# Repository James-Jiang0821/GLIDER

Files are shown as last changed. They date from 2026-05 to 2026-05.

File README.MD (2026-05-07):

# Glider System

Top-level repo for the underwater glider. 

ROS 2 stack on the Raspberry Pi, Teensy firmware for the P&R and VBD boards, KiCad designs for the custom electronics, and post-test analysis tooling.

Each subfolder has its own README with full details.

## Subsystems

- **[ROS2_SYSTEM/](ROS2_SYSTEM/README.md)** — ROS 2 Jazzy stack on the Raspberry Pi: sensor drivers, mission state machine, inner/outer-loop controller, safety watchdog, Iridium telemetry, and the CAN bridge to the Teensy boards.
- **[TEENSY/](TEENSY/)** — Teensy 4.0 firmware for the actuator boards.
  - **[tsyPR/](TEENSY/tsyPR/README.md)** — Pitch & Roll firmware (stepper-driven pitch mass + roll mass).
  - **[tsyVBDL/](TEENSY/tsyVBDL/README.md)** — Variable Buoyancy Device firmware (lead-screw piston with closed-loop position control).
- **[PCB/](PCB/README.MD)** — KiCad schematics and layouts for the custom P&R and VBD boards.
- **[BATTERY_BOARD/](BATTERY_BOARD/README.MD)** — KiCad designs for the P&R and VBD battery boards (A/B variants).
- **[ROS2_TESTING/](ROS2_TESTING/README.md)** — Post-test analysis scripts for ROS 2 bag files (`.mcap` to CSV).

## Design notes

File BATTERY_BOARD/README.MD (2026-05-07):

# Battery Board

KiCad design files for the glider's battery boards.

## Subsystems

- **P&R/** — Pitch & Roll battery board. Powers the P&R subsystem; A and B variants.
- **VBD/** — Variable Buoyancy Device battery board. Powers the VBD subsystem; A and B variants.

Each folder contains the KiCad schematic (`.kicad_sch`), PCB layout (`.kicad_pcb`), and project file (`.kicad_pro`) for both A and B revisions.

## Authors

Bartol Vahcic

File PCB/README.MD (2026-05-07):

# PCB

KiCad design files for the glider's custom boards.

## Subsystems

- **P&R/** — Pitch & Roll board. Drives the pitch and roll actuators; also connects to the Raspberry Pi.
- **VBD/** — Variable Buoyancy Device board. Drives the VBD pump/valve subsystem.

Each folder contains the KiCad schematic (`.kicad_sch`) and PCB layout (`.kicad_pcb`); `P&R/` also includes the project file (`.kicad_pro`).

## Authors

Qihao Zhang

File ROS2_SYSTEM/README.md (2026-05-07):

# Glider ROS 2 System

ROS 2 Jazzy stack for an underwater glider: sensor drivers, mission
state machine, inner/outer-loop controller, safety watchdog, Iridium
telemetry, and a CAN bridge to the Teensy-based P&R and VBD boards.

## Requirements

- Ubuntu 24.04 + ROS 2 Jazzy
- Python 3.12
- Hardware:
  - Raspberry Pi with I2C and UART enabled
  - Pololu MinIMU-9 v6 (I2C)
  - MAX-M10S GNSS (I2C)
  - Keller pressure sensor (I2C)
  - Ping sonar (UART)
  - Iridium modem (UART)
  - CAN bus to Teensy P&R (pitch & roll) + VBD (variable buoyancy) boards

## Build

The project is cloned into the `src/` of a ROS 2 workspace — e.g.
`~/glider_ws/src/ROS2_SYSTEM/`. Build from the workspace root:

```bash
source /opt/ros/jazzy/setup.bash
cd ~/glider_ws
colcon build --packages-select glider_msgs
source install/setup.bash
colcon build --packages-select glider_ros
source install/setup.bash
```

## Run

The system is split across three launch files so each runs in its own
terminal with clean, isolated log output:

```bash
# Main system: drivers, adapters, safety, controller
ros2 launch glider_ros all_nodes_launch.py

# Mission state machine — separate terminal
ros2 launch glider_ros state_manager_launch.py

# CAN bridge (Teensy P&R + VBD) — separate terminal
ros2 launch glider_ros can_bridge_launch.py
```

Each fresh terminal needs `source install/setup.bash` once before
`ros2 launch`. Individual nodes can also be launched with
`ros2 run glider_ros <executable>` — see the full executable list in
[setup.py](src/glider_ros/setup.py).

## System overview

The state manager drives two lifecycle nodes (`controller_node`,
`communication_iridium_node`) through `configure` / `activate` /
`deactivate` / `cleanup` transitions as part of mission phasing.

## Layout

- `src/glider_msgs/` — custom messages and actions (`Float64Stamped`,
  `HomeActuators`, `IridiumWindow`).
- `src/glider_ros/glider_ros/driver/` — hardware-facing nodes (I2C,
  UART).
- `src/glider_ros/glider_ros/bridge/` — protocol bridges to external
  microcontrollers (CAN ↔ Teensy P&R / VBD).
- `src/glider_ros/glider_ros/adapter/` — data fusion and formatting
  adapters.
- `src/glider_ros/glider_ros/manager/` — mission state machine.
- `src/glider_ros/glider_ros/controller/` — flight controller (lifecycle).
- `src/glider_ros/glider_ros/safety/` — and watchdog
  monitor.
- `src/glider_ros/launch/` — launch files per deployment scenario.
- `src/glider_ros/config/` — YAML parameter files.
- `src/glider_ros/test/` — pytest unit/integration tests.

For what each node does, please read the module docstring at the top of its
`.py` file.

## Testing

### Unit Testing

To perform unit testing, from the workspace root, run:

```bash
source /opt/ros/jazzy/setup.bash
source install/setup.bash
python3 -m pytest src/glider_ros/test/ -v --cov=glider_ros --cov-report=term-missing --cov-report=html

```

Unit tests cover the adapter, safety, and state manager nodes. HTML
coverage lands in `htmlcov/`.

## Authors

- James Jiang <jamesjiang0821@gmail.com>
- Hussain Khan <hussainniassuh786@gmail.com>

## License

MIT. See `package.xml` / `setup.py`.

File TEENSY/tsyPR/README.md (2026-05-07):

# P&R Teensy Firmware (`tsyPR`)

Firmware for the Pitch & Roll (P&R) board on the underwater glider.
Runs on a Teensy 4.0 and drives two stepper-actuated axes — a linear
pitch mass and a rotational roll mass — with limit-based homing and a
CAN bridge back to the Raspberry Pi running the
[Glider ROS 2 stack](../../ROS2_SYSTEM/README.md).

A single board handles both axes (`NODE_ID=3`).

## Requirements

- PlatformIO (Arduino framework, `platform = teensy`)
- Hardware:
  - Teensy 4.0
  - 2 × DRV8825 stepper drivers (pitch + roll)
  - Pitch stepper + lead-screw mass slider (0.01 mm/step)
  - Roll stepper + rotational mass (0.045 °/step)
  - 2 × push-switch endstops (pitch fwd/rev limits)
  - Hall-effect sensor (roll zero/homing)
  - Adafruit VL6180X ToF sensor (I2C, pitch position cross-check)
  - TinyBMS over UART (battery telemetry)
  - Leak sensor
  - CAN transceiver on CAN2 (Teensy pins 0/1)

## Build & Flash

From [TEENSY/tsyPR/](.):

```bash
# Build
pio run

# Build + flash over USB
pio run -t upload

# Serial monitor (115200 baud)
pio device monitor
```

Node identity is set by the `-D NODE_ID=...` build flag in
[platformio.ini](platformio.ini). Default is `3` (P&R). Override with:

```bash
pio run -t upload --project-option="build_flags=-D NODE_ID=3"
```

## System overview

The control loop runs:

1. Read step counters + endstops/hall + ToF -> per-axis position
   estimate (steps as primary, ToF/hall as homing reference).
2. `SafetyManager` aggregates leak, driver fault, overcurrent, stall,
   command timeout, and BMS health into `hard_fault` / `soft_fault`
   bits — controllers never decide faults themselves.
3. `PitchController` and `RollController` each run their state machine
   (`UNHOMED -> HOMING -> RUN -> HOLD -> FAULT`), stepping the DRV8825 at
   the configured step rate.
4. CAN frames publish pitch/roll position and status; setpoints and
   mode commands arrive on CAN from the ROS bridge.

## Layout

- [platformio.ini](platformio.ini) — build env, lib deps, `NODE_ID`
- [include/config/](include/config/) — `pin_map.hpp`, `constants.hpp`
  (step geometry, travel limits, safety thresholds, CAN scaling)
- [include/drivers/](include/drivers/) /
  [src/drivers/](src/drivers/) — hardware-facing classes:
  - `stepper_driver` (DRV8825, STEP/DIR/ENA/FLT)
  - `push_switch` (pitch fwd/rev limit endstops)
  - `hall_sensor` (roll homing reference)
  - `tof_sensor` (VL6180X over Wire1)
  - `leak_sensor`, `bms` (TinyBMS UART)
  - `can_bus` (FlexCAN wrapper, 11-bit IDs)
  - `main.cpp` — composition root, control loop
- [include/controllers/](include/controllers/) /
  [src/controllers/](src/controllers/) — control logic:
  - `pitch_controller` (state machine, limit-switch homing,
    soft-zone limits)
  - `roll_controller` (state machine, hall-sensor homing,
    soft-zone limits)
  - `safety_manager` (centralised fault aggregation, latched)
  - `bms_manager` (battery state + timeout policy)
- [include/protocols/](include/protocols/) /
  [src/protocols/](src/protocols/) — `can_messages.hpp`/`.cpp`,
  CAN frame IDs and packing.
- [include/utils/logger.hpp](include/utils/logger.hpp) — serial logging.
- [test/](test/) — bench-test notes for motors, CAN, safety, BMS, etc.

## Key parameters

Defined in [include/config/constants.hpp](include/config/constants.hpp):

- Pitch: 0.01 mm/step, ±56.9 mm physical travel
- Roll: 0.045 °/step, ±90° physical travel
- Overcurrent: 6.0 A hard, 3.0 A stall threshold
- Stall confirm: 2.0 s at ≥25% duty with <0.1 mm motion
- Homing timeout: 60 s
- Leak debounce: 50 ms; driver-fault debounce: 20 ms
- Command timeout: 300 ms (small) / 120 s (large)
- BMS timeout: 5 s (small) / 120 s (large)

## Testing

Bench tests are scripted/manual procedures captured as notes in
[test/](test/), numbered by integration stage (motor only -> motor +
CAN -> safety -> BMS). Run them in order when bringing up a new board.

## Authors

Jasper Yip

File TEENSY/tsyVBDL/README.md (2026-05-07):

# VBD Teensy Firmware (`tsyVBDL`)

Firmware for the Variable Buoyancy Device (VBD) board on the underwater
glider. Runs on a Teensy 4.0 and drives a lead-screw piston via a
brushed DC motor, with closed-loop position control and a CAN bridge
back to the Raspberry Pi running the [Glider ROS 2 stack](../../ROS2_SYSTEM/README.md).

Two physical boards share this firmware — `PORT` (NODE_ID=1) and
`STARBOARD` (NODE_ID=2) — selected at build time.

## Requirements

- PlatformIO (Arduino framework, `platform = teensy`)
- Hardware:
  - Teensy 4.0
  - Pololu G2 High-Power 24v13 motor driver
  - Maxon brushed DC motor + 1024 CPR quadrature encoder, 156:1 gearbox
  - 4 mm/rev lead screw, 150 mm stroke piston
  - Adafruit VL6180X ToF sensor (I2C, stroke fusion)
  - Inductive proximity sensor (homing endstop)
  - TinyBMS over UART (battery telemetry)
  - Leak sensor
  - CAN transceiver on CAN2 (Teensy pins 0/1)

## Build & Flash

From [TEENSY/tsyVBDL/](.):

```bash
# Build
pio run

# Build + flash over USB
pio run -t upload

# Serial monitor (115200 baud)
pio device monitor
```

Node identity is set by the `-D NODE_ID=...` build flag in
[platformio.ini](platformio.ini). Default is `1` (LEFT). Override per
board:

```bash
pio run -t upload --project-option="build_flags=-D NODE_ID=2"
```

## System overview

The 1 kHz control loop runs:

1. Read encoder + ToF -> `Estimator` produces fused stroke estimate
   (counts as primary, ToF as drift/slip correction).
2. `SafetyManager` aggregates leak, motor fault, overcurrent, stall,
   command timeout, and BMS health into `hard_fault` / `soft_fault`
   bits — controllers never decide faults themselves.
3. `PistonController` runs its state machine
   (`UNHOMED -> HOMING -> RUN -> HOLD -> FAULT`), driving `PIDController`
   inside `RUN`.
4. CAN frames at 50 Hz publish position, current, and status; setpoints
   and mode commands arrive on CAN from the ROS bridge.

## Layout

- [platformio.ini](platformio.ini) — build env, lib deps, `NODE_ID`
- [include/config/](include/config/) — `pin_map.hpp`, `constants.hpp`
  (stroke geometry, PID gains, safety thresholds, CAN scaling)
- [include/drivers/](include/drivers/) /
  [src/drivers/](src/drivers/) — hardware-facing classes:
  - `motor_driver` (Pololu G2, PWM/DIR/SLP/FLT, current sense)
  - `encoder` / `enc_alt` (quad encoder, two backends)
  - `tof_sensor` (VL6180X over Wire1)
  - `proximity` (homing endstop)
  - `leak_sensor`, `bms` (TinyBMS UART)
  - `can_bus` (FlexCAN wrapper, 11-bit IDs)
  - `main.cpp` — composition root, control loop
- [include/controllers/](include/controllers/) /
  [src/controllers/](src/controllers/) — control logic:
  - `estimator` (encoder + ToF fusion, slip detection)
  - `pid_controller` (P, I, D with anti-windup + output clamp)
  - `piston_controller` (state machine, homing, soft-zone limits)
  - `safety_manager` (centralised fault aggregation, latched)
  - `bms_manager` (battery state + timeout policy)
- [include/protocols/](include/protocols/) /
  [src/protocols/](src/protocols/) — `can_messages.hpp`/`.cpp`,
  CAN frame IDs and packing (e.g. `STATUS_FAULT 0x050`,
  position in 0.1 mm units).
- [include/utils/logger.hpp](include/utils/logger.hpp) — serial logging.
- [test/](test/) — bench-test notes for motor, ToF, PID, CAN, homing,
  safety, encoder, BMS, leak, prox, etc.

## Key parameters

Defined in [include/config/constants.hpp](include/config/constants.hpp):

- Control loop: 1 kHz, PWM 25 kHz
- Stroke: 0–150 mm physical, 10–145 mm hard limits, 20–135 mm soft zone
- PID: Kp=0.10, Ki=0.0, Kd=0.003
- Position tolerance: 0.1 mm (enter HOLD), 2.0 mm drift restarts PID
- Homing: 40% PWM toward prox, 10% backoff
- Slip detection: 3 mm encoder-vs-ToF disagreement
- Overcurrent: 6.0 A hard, 3.0 A stall threshold
- CAN position scaling: 0.1 mm/LSB

## Testing

Bench tests are scripted/manual
procedures captured as notes in [test/](test/), numbered by integration
stage (motor only -> ToF -> PID -> CAN -> homing -> safety). Run them in
order when bringing up a new board.

## Authors

Jasper Yip

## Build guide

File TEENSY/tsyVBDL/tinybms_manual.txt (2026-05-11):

                     Communication
                     Protocols
                     Tiny BMS
        Revision D, 2025-07-04
                                         Tiny BMS Communication Protocols
         Contents
         Chapter 1: Tiny BMS UART communication protocol.....................................................................................4
           1. Introduction........................................................................................................................................... 4
            1.1. UART communication commands list............................................................................................4
              1.1.1. Tiny BMS acknowledgement.................................................................................................4
              1.1.2. Read Tiny BMS registers block.............................................................................................4
              1.1.3. Read Tiny BMS individual registers......................................................................................5
              1.1.4. Write Tiny BMS registers block.............................................................................................5
              1.1.5. Write Tiny BMS individual registers.......................................................................................5
              1.1.6. Read Tiny BMS registers block (MODBUS compatible)........................................................6
              1.1.7. Write Tiny BMS registers block (MODBUS compatible)........................................................6
              1.1.8. Reset Tiny BMS, clear Events and Statistics........................................................................7
              1.1.9. Read Tiny BMS newest Events.............................................................................................7
              1.1.10.  Read Tiny BMS all Events..................................................................................................7
              1.1.11.  Read battery pack voltage (Reg:36)...................................................................................8
              1.1.12.  Read battery pack current (Reg:38)...................................................................................8
              1.1.13.  Read battery pack max. cell voltage (Reg:41)....................................................................8
              1.1.14.  Read battery pack min. cell voltage (Reg:40).....................................................................8
              1.1.15.  Read Tiny BMS online status (Reg:50)..............................................................................8
              1.1.16.  Read Tiny BMS lifetime counter (Reg:32)..........................................................................9
              1.1.17.  Read Tiny BMS estimated SOC value (Reg:46)................................................................9
              1.1.18.  Read Tiny BMS device temperatures (Reg:48, Reg:42, Reg:43).......................................9
              1.1.19.  Read battery pack cells voltages......................................................................................10
              1.1.20.  Read Tiny BMS settings values (min, max, default, current)............................................10
              1.1.21.  Read Tiny BMS version....................................................................................................10
              1.1.22.  Read Tiny BMS extended version....................................................................................10
              1.1.23.  Read Tiny BMS calculated speed, left distance and estimated time values.....................11
            1.2. CRC checksum calculation..........................................................................................................11
            1.3. UART communication examples.................................................................................................12
              1.3.1. MODBUS write registers example.......................................................................................12
              1.3.2. MODBUS read registers example.......................................................................................13
              1.3.3. Tiny BMS read temperatures example................................................................................13
         Chapter 2: Tiny BMS CAN bus communication protocol..............................................................................14
           2. Introduction......................................................................................................................................... 14
            2.1. CAN bus communication commands list.....................................................................................14
              2.1.1. Reset Tiny BMS, clear Events and Statistics......................................................................14
              2.1.2. Read Tiny BMS registers block...........................................................................................14
              2.1.3. Write Tiny BMS registers block...........................................................................................15
              2.1.4. Read Tiny BMS newest Events...........................................................................................15
              2.1.5. Read Tiny BMS all Events...................................................................................................16
              2.1.6. Read battery pack voltage (Reg:36)....................................................................................17
              2.1.7. Read battery pack current (Reg:38)....................................................................................17
              2.1.8. Read battery pack max. cell voltage (Reg:41).....................................................................17
              2.1.9. Read battery pack min. cell voltage (Reg:40)......................................................................18
              2.1.10.  Read Tiny BMS online status (Reg:50)............................................................................18
              2.1.11.  Read Tiny BMS lifetime counter (Reg:32)........................................................................18
              2.1.12.  Read Tiny BMS estimated SOC value (Reg:46)..............................................................19
              2.1.13.  Read Tiny BMS device temperatures (Reg:48, Reg:42, Reg:43).....................................19
              2.1.14.  Read battery pack cells voltages......................................................................................20
              2.1.15.  Read Tiny BMS settings values (min, max, default, current)............................................20
              2.1.16.  Read Tiny BMS version....................................................................................................21
              2.1.17.  Read Tiny BMS calculated speed, left distance and estimated time values.....................21
              2.1.18.  Read CAN node ID..........................................................................................................22
              2.1.19.  Write CAN node ID...........................................................................................................22
         Chapter 3: Tiny BMS registers map.............................................................................................................23
           3. Introduction......................................................................................................................................... 23
          www.enepaq.com     Revision D, 2025-07-04    Page 2
                                  Tiny BMS Communication Protocols
       3.1. Tiny BMS Live data.....................................................................................................................23
       3.2. Tiny BMS Statistics data.............................................................................................................23
       3.3. Tiny BMS Events data.................................................................................................................24
       3.4. Tiny BMS settings.......................................................................................................................24
       3.5. Tiny BMS version data................................................................................................................25
    Chapter 4: Tiny BMS Events messages list.................................................................................................26
      4. Introduction......................................................................................................................................... 26
       4.1. Tiny BMS Fault messages list.....................................................................................................26
       4.2. Tiny BMS Warning messages list................................................................................................26
       4.3. Tiny BMS Information messages list...........................................................................................26
     www.enepaq.com    Revision D, 2025-07-04    Page 3
                                                                                                       Tiny BMS Communication Protocols
                       Chapter 1: Tiny BMS UART communication protocol
                       1. Introduction
                       Tiny BMS device includes a single multi-purpose UART interface. In combination with various converters, 
                       the interface is compatible with USB, bluetooth and CAN interfaces. Various proprietary commands are 
                       available for fast communication, also MODBUS commands 03 and 16 are supported for rapid integration 
                       to existing industrial systems. An internal Tiny BMS device register map is given in Chapter 3. The register 
                       map values can be read and modified using MODBUS and proprietary commands. This chapter in detail 
                       covers all available commands implemented to communicate with Tiny BMS device. Every command 
                       request and response contains 16 bit CRC checksum. How to calculate CRC value refer to Chapter 1.2.
                        Note: UART configuration: baudrate 115200 bit/s, 8 data bits, 1 stop bit, no parity, no flow control. UART 
                        configuration is not allowed to be changed by the user.
                       1.1. UART communication commands list
                       1.1.1. Tiny BMS acknowledgement
                       Response from BMS [NACK]
                        Byte 1   Byte 2   Byte 3             Byte 4               Byte 5      Byte 6
                         0xAA     0x00     CMD               ERROR              CRC:LSB     CRC:MSB
                                                      0x00 – CMD ERROR
                                                       0x01 – CRC ERROR
                       Response from BMS [ACK]
                        Byte 1   Byte 2   Byte 3     Byte 4      Byte 5
                         0xAA     0x01     CMD     CRC:LSB CRC:MSB
                       CMD – Command code
                       ERROR – Error code
                       1.1.2. Read Tiny BMS registers block
                       Request to BMS
                         Byte1   Byte 2   Byte 3      Byte 4       Byte 5       Byte 6       Byte 7
                         0xAA     0x07      RL     ADDR:LSB      ADDR:MSB      CRC:LSB     CRC:MSB
                                                           [UINT_16]
                       Response from BMS [OK]
                         Byte1   Byte 2   Byte 3      Byte 4       Byte 5      ...   Byte n*2+2     Byte n*2+3    Byte n*2+4    Byte n*2+5
                         0xAA     0x07      PL     DATA1:LSB DATA1:MSB         ...   DATAn:LSB     DATAn:MSB       CRC:LSB      CRC:MSB
                                                           [UINT_16]                         [UINT_16]
                       RL – Registers to read
                       ADDR – First registers block address
                       DATA – Registers block values
                       PL – Payload length byte
                         Bit 7      Bit 6       Bit 5    Bit 4     Bit 3     Bit 2    Bit 1    Bit 0
                           0      Reserved                Payload size in bytes (last packet)
                           1      Reserved                       Current packet ID
                       Response from BMS [ERROR]
                         Byte 1   Byte 2    Byte 3    Byte 4     Byte 5       Byte 6
                         0xAA      0x00      0x07    ERROR CRC:LSB          CRC:MSB
                        www.enepaq.com                                  Revision D, 2025-07-04                                              Page 4
                                                                                   Tiny BMS Communication Protocols
         1.1.3. Read Tiny BMS individual registers
         Request to BMS
           Byte1  Byte 2   Byte 3     Byte 4        Byte 5      ...  Byte n*2+2    Byte n*2+3   Byte n*2+4  Byte n*2+5
           0xAA    0x09      PL     ADDR1:LSB ADDR1:MSB         ...  ADDRn:LSB    ADDRn:MSB      CRC:LSB    CRC:MSB
                                            [UINT_16]                        [UINT_16]
         PL – Payload length in bytes
         Response from BMS [OK]
           Byte1   Byte 2  Byte 3     Byte 4        Byte 5        Byte 6      Byte 7      ...    Byte n*4    Byte n*4+1
           0xAA    0x09      PL     ADDR1:LSB    ADDR1:MSB DATA1:LSB DATA1:MSB            ...  ADDRn:LSB     ADDRn:MSB
                                            [UINT_16]                  [UINT_16]                       [UINT_16]
           Byte n*4+2   Byte n*4+3   Byte n*4+4  Byte n*4+5
           DATAn:LSB   DATAn:MSB     CRC:LSB     CRC:MSB
                  [UINT_16]
         Request to BMS
         ADDR – Individual registers addresses
         DATA – Registers values
         PL – Payload length byte
           Bit 7     Bit 6      Bit 5   Bit 4     Bit 3    Bit 2    Bit 1   Bit 0
             0     Reserved              Payload size in bytes (last packet)
             1     Reserved                     Current packet ID
         Response from BMS [ERROR]
            Byte 1     Byte 2    Byte 3     Byte 4      Byte 5       Byte 6
            0xAA       0x00       0x09      ERROR      CRC:LSB     CRC:MSB
         1.1.4. Write Tiny BMS registers block
         Request to BMS
           Byte1    Byte 2   Byte 3      Byte 4       Byte 5        Byte 6       Byte 7      ... Byte n*2+4   Byte n*2+5
           0xAA     0x0B       PL      ADDR:LSB     ADDR:MSB     DATA1:LSB     DATA1:MSB     ... DATAn:LSB    DATAn:MSB
                                              [UINT_16]                  [UINT_16]                      [UINT_16]
           Byte n*2+6  Byte n*2+7
           CRC:LSB     CRC:MSB
         ADDR – First registers block address (valid addresses to write 0x012C to 0x018F)
         DATA – Registers block values to write
         PL – Payload length byte
           Bit 7     Bit 6      Bit 5   Bit 4     Bit 3    Bit 2    Bit 1   Bit 0
             0     Reserved              Payload size in bytes (last packet)
             1     Reserved                     Current packet ID
         Response from BMS [ACK]
           Byte 1  Byte 2    Byte 3    Byte 4      Byte 5
           0xAA     0x01     0x0B     CRC:LSB    CRC:MSB
         Response from BMS [ERROR]
           Byte 1  Byte 2    Byte 3    Byte 4      Byte 5      Byte 6
           0xAA     0x00     0x0B     ERROR      CRC:LSB     CRC:MSB
         1.1.5. Write Tiny BMS individual registers
         Request to BMS
           Byte1   Byte 2    Byte 3      Byte 4        Byte 5        Byte 6       Byte 7     ...   Byte n*4     Byte n*4+1
           0xAA     0x0D      PL      ADDR1:LSB     ADDR1:MSB     DATA1:LSB    DATA1:MSB     ... ADDRn:LSB ADDRn:MSB
                                              [UINT_16]                   [UINT_16]                      [UINT_16]
          www.enepaq.com                               Revision D, 2025-07-04                                        Page 5
                                                                                                   Tiny BMS Communication Protocols
                        Byte n*4+2   Byte n*4+3    Byte n*4+4  Byte n*4+5
                        DATAn:LSB    DATAn:MSB     CRC:LSB      CRC:MSB
                               [UINT_16]
                      ADDR – Individual registers addresses (valid addresses to write 0x012C to 0x018F)
                      DATA – Individual registers values to write
                      PL – Payload length byte
                        Bit 7      Bit 6      Bit 5    Bit 4    Bit 3     Bit 2    Bit 1    Bit 0
                          0      Reserved              Payload size in bytes (last packet)
                          1      Reserved                      Current packet ID
                      Response from BMS [ACK]
                       Byte 1   Byte 2     Byte 3    Byte 4      Byte 5
                        0xAA     0x01      0x0D     CRC:LSB CRC:MSB
                      Response from BMS [ERROR]
                       Byte 1   Byte 2     Byte 3    Byte 4      Byte 5      Byte 6
                        0xAA     0x00      0x0D      ERROR     CRC:LSB     CRC:MSB
                      1.1.6. Read Tiny BMS registers block (MODBUS compatible)
                      Request to BMS
                        Byte1   Byte 2       Byte 3         Byte 4      Byte 5   Byte 6    Byte 7      Byte 8
                        0xAA     0x03     ADDR1:MSB      ADDR1:LSB      0x00       RL     CRC:LSB CRC:MSB
                                                   [UINT_16]
                      ADDR – First registers block address
                      RL – Registers to read. Max. 127 registers (0x7F)
                      Response from BMS [OK]
                        Byte1    Byte 2    Byte 3     Byte 4        Byte 5      ...   Byte n*2+2    Byte n*2+3   Byte n*2+4  Byte n*2+5
                        0xAA      0x03       PL     DATA1:MSB     DATA1:LSB     ...  DATAn:MSB     DATAn:LSB     CRC:LSB     CRC:MSB
                                                            [UINT_16]                        [UINT_16]
                      PL – Payload length in bytes
                      Response from BMS [ERROR]
                        Byte 1   Byte 2    Byte 3    Byte 4     Byte 5      Byte 6
                        0xAA      0x00      0x03    ERROR CRC:LSB         CRC:MSB
                      1.1.7. Write Tiny BMS registers block (MODBUS compatible)
                      Request to BMS
                        Byte 1   Byte 2      Byte 3        Byte 4     Byte 5     Byte 6    Byte 7         Byte8           Byte 9      ...
                        0xAA      0x10     ADDR:MSB      ADDR:LSB      0x00       RL         PL        DATA1:MSB        DATA1:LSB     ...
                                                  [UINT_16]                                                     [UINT_16]
                        Byte n*2+6   Byte n*2+7    Byte n*2+8  Byte n*2+9
                       DATAn:MSB     DATAn:LSB     CRC:LSB      CRC:MSB
                               [UINT_16]
                      Response from BMS [OK]
                        Byte1    Byte 2       Byte 3         Byte 4       Byte 5     Byte 6       Byte 7        Byte 8
                        0xAA      0x10     ADDR:MSB        ADDR:LSB        0x00        RL       CRC:LSB       CRC:MSB
                                                    [UINT_16]
                      ADDR – First registers block address
                      RL – Registers to write. Max. 100 registers (0x64)
                      PL – Payload length in bytes
                      DATA – Registers block values to write
                      Response from BMS [ERROR]
                        Byte 1   Byte 2     Byte 3     Byte 4      Byte 5       Byte 6
                        0xAA      0x00      0x10      ERROR      CRC:LSB      CRC:MSB
                        www.enepaq.com                                Revision D, 2025-07-04                                           Page 6
                                                                                         Tiny BMS Communication Protocols
          1.1.8. Reset Tiny BMS, clear Events and Statistics
          Request to BMS
           Byte 1    Byte 2             Byte 3              Byte 4       Byte 5
            0xAA      0x02             OPTION              CRC:LSB     CRC:MSB
                                  0x01 – Clear Events
                                 0x02 – Clear Statistics
                                   0x05 – Reset BMS
          Response from BMS [ACK]
           Byte 1    Byte 2     Byte 3     Byte 4      Byte 5
            0xAA      0x01      0x02      CRC:LSB     CRC:MSB
          Response from BMS [ERROR]
           Byte 1    Byte 2     Byte 3     Byte 4       Byte 5      Byte 6
            0xAA      0x00      0x02      ERROR       CRC:LSB     CRC:MSB
          1.1.9. Read Tiny BMS newest Events
          Request to BMS
           Byte 1    Byte 2     Byte 3      Byte 4
            0xAA      0x11     CRC:LSB CRC:MSB
          Response from BMS [OK]
           Byte 1    Byte 2     Byte 3      Byte 4     Byte 5   Byte 6     Byte 7       Byte 8     Byte 9     Byte 10    Byte 11    ...
            0xAA      0x11        PL      BTSP:LSB     BTSP      BTSP BTSP:MSB TSP1:LSB             TSP1    TSP1:MSB EVENT1         ...
                                                          [UINT32]                                [UINT24]              [UINT_8]
           Byte n*4+4 Byte n*4+5 Byte n*4+6 Byte n*4+7     Byte n*4+8   Byte n*4+9
           TSPn:LSB      TSPn     TSPn:MSB     EVENTn      CRC:LSB      CRC:MSB
                      [UINT_24]                [UINT_8]
          PL – Payload length in bytes
          PTSP – BMS timestamp in seconds
          TSP – Event timestamp in seconds
          EVENT – BMS Event ID
          Response from BMS [ERROR]
            Byte 1    Byte 2    Byte 3      Byte 4       Byte 5        Byte 6
            0xAA      0x00       0x11      ERROR       CRC:LSB       CRC:MSB
          1.1.10. Read Tiny BMS all Events
          Request to BMS
            Byte 1    Byte 2    Byte 3      Byte 4
            0xAA      0x12     CRC:LSB CRC:MSB
          Response from BMS [OK]
            Byte 1    Byte 2    Byte 3      Byte 4     Byte 5   Byte 6     Byte 7       Byte 8     Byte 9     Byte 10   Byte 11    ...
            0xAA      0x12        PL      BTSP:LSB     BTSP      BTSP BTSP:MSB TSP1:LSB             TSP1    TSP1:MSB EVENT1        ...
                                                          [UINT_32]                              [UINT_24]              [UINT_8]
           Byte n*4+4 Byte n*4+5 Byte n*4+6 Byte n*4+7     Byte n*4+8   Byte n*4+9
           TSPn:LSB      TSPn     TSPn:MSB     EVENTn      CRC:LSB      CRC:MSB
                      [UINT_24]                [UINT_8]
          PL – Payload length in bytes
          PTSP – BMS timestamp in seconds
          TSP – Event timestamp in seconds
          EVENT – BMS Event ID
          Response from BMS [ERROR]
            Byte 1    Byte 2    Byte 3      Byte 4      Byte 5      Byte 6
            0xAA      0x00       0x12      ERROR      CRC:LSB CRC:MSB
           www.enepaq.com                                  Revision D, 2025-07-04                                              Page 7
                                                                                                       Tiny BMS Communication Protocols
                       1.1.11. Read battery pack voltage (Reg:36)
                       Request to BMS
                         Byte 1    Byte 2     Byte 3      Byte 4
                         0xAA      0x14     CRC:LSB     CRC:MSB
                       Response from BMS [OK]
                         Byte 1    Byte 2       Byte 3       Byte 4        Byte 5        Byte 6      Byte 7       Byte 8
                         0xAA       0x14      DATA:LSB        DATA         DATA       DATA:MSB      CRC:LSB     CRC:MSB
                                                                   [FLOAT]
                       Response from BMS [ERROR]
                         Byte 1    Byte 2      Byte 3      Byte 4       Byte 5       Byte 6
                         0xAA       0x00        0x14      ERROR       CRC:LSB      CRC:MSB
                       1.1.12. Read battery pack current (Reg:38)
                       Request to BMS
                         Byte 1    Byte 2      Byte 3       Byte 4
                         0xAA       0x15     CRC:LSB      CRC:MSB
                       Response from BMS [OK]
                         Byte 1    Byte 2       Byte 3      Byte 4      Byte 5       Byte 6        Byte 7        Byte 8
                         0xAA       0x15      DATA:LSB       DATA       DATA       DATA:MSB       CRC:LSB      CRC:MSB
                                                                 [FLOAT]
                       Response from BMS [ERROR]
                         Byte 1    Byte 2      Byte 3       Byte 4      Byte 5       Byte 6
                         0xAA       0x00        0x15       ERROR      CRC:LSB      CRC:MSB
                       1.1.13. Read battery pack max. cell voltage (Reg:41)
                       Request to BMS
                         Byte 1    Byte 2      Byte 3       Byte 4
                         0xAA       0x16     CRC:LSB      CRC:MSB
                       Response from BMS [OK]
                         Byte 1    Byte 2       Byte 3         Byte 4         Byte 5        Byte 6
                         0xAA       0x16      DATA:LSB       DATA:MSB       CRC:LSB       CRC:MSB
                                                      [UINT_16]
                       Response from BMS [ERROR]
                         Byte 1    Byte 2     Byte 3      Byte 4       Byte 5       Byte 6
                         0xAA       0x00       0x16      ERROR       CRC:LSB      CRC:MSB
                       1.1.14. Read battery pack min. cell voltage (Reg:40)
                       Request to BMS
                         Byte 1    Byte 2     Byte 3      Byte 4
                         0xAA       0x17     CRC:LSB CRC:MSB
                       Response from BMS [OK]
                         Byte 1    Byte 2       Byte 3         Byte 4         Byte 5         Byte 6
                         0xAA       0x17      DATA:LSB       DATA:MSB        CRC:LSB       CRC:MSB
                                                      [UINT_16]
                       Response from BMS [ERROR]
                         Byte 1    Byte 2     Byte 3      Byte 4      Byte 5        Byte 6
                         0xAA       0x00       0x17      ERROR       CRC:LSB      CRC:MSB
                       1.1.15. Read Tiny BMS online status (Reg:50)
                       Request to BMS
                         Byte 1    Byte 2     Byte 3      Byte 4
                         0xAA       0x18     CRC:LSB CRC:MSB
                        www.enepaq.com                                  Revision D, 2025-07-04                                              Page 8
                                                                                         Tiny BMS Communication Protocols
          Response from BMS [OK]
            Byte 1    Byte 2        Byte 3          Byte 4        Byte 5      Byte 6
            0xAA       0x18       DATA:LSB       DATA:MSB       CRC:LSB      CRC:MSB
                                    0x91 – Charging [INFO]
                                 0x92 – Fully Charged [INFO]
                                  0x93 – Discharging [INFO]
                                  0x96 – Regeneration [INFO]
                                      0x97 – Idle [INFO]
                                    0x9B – Fault [ERROR]
          Response from BMS [ERROR]
            Byte 1    Byte 2       Byte 3       Byte 4       Byte 5       Byte 6
            0xAA       0x00         0x18       ERROR       CRC:LSB      CRC:MSB
          1.1.16. Read Tiny BMS lifetime counter (Reg:32)
          Request to BMS
            Byte 1    Byte 2      Byte 3       Byte 4
            0xAA       0x19     CRC:LSB      CRC:MSB
          Response from BMS [OK]
            Byte 1    Byte 2      Byte 3       Byte 4       Byte 5        Byte 6       Byte 7       Byte 8
            0xAA       0x19     DATA:LSB       DATA         DATA       DATA:MSB       CRC:LSB     CRC:MSB
                                                    [UINT_32]
          Response from BMS [ERROR]
            Byte 1    Byte 2      Byte 3       Byte 4       Byte 5        Byte 6
            0xAA       0x00       0x19        ERROR       CRC:LSB       CRC:MSB
          1.1.17. Read Tiny BMS estimated SOC value (Reg:46)
          Request to BMS
            Byte 1     Byte 2      Byte 3       Byte 4
             0xAA       0x1A      CRC:LSB     CRC:MSB
          Response from BMS [OK]
            Byte 1     Byte 2      Byte 3       Byte 4      Byte 5        Byte 6        Byte 7       Byte 8
             0xAA       0x1A     DATA:LSB       DATA        DATA       DATA:MSB       CRC:LSB      CRC:MSB
                                                     [UINT_32]
          Response from BMS [ERROR]
            Byte 1     Byte 2      Byte 3       Byte 4      Byte 5        Byte 6
             0xAA       0x00        0x1A       ERROR      CRC:LSB       CRC:MSB
          1.1.18. Read Tiny BMS device temperatures (Reg:48, Reg:42, Reg:43)
          Request to BMS
           Byte 1   Byte 2    Byte 3       Byte 4
            0xAA    0x1B     CRC:LSB     CRC:MSB
          Response from BMS [OK]
           Byte 1   Byte 2  Byte 3     Byte 4      Byte 5       Byte 6       Byte 7      Byte 8       Byte 9      Byte 10    Byte 11
            0xAA    0x1B      PL    DATA1:LSB DATA1:MSB DATA2:LSB DATA2:MSB DATA3:LSB DATA3:MSB CRC:LSB CRC:MSB
                                            [INT_16]                 [INT_16]                  [INT_16]
          PL – Payload length in bytes
          DATA1 – Tiny BMS internal temperature
          DATA2 – External temperature sensor #1 temperature value (value of -32768 if not connected)
          DATA3 – External temperature sensor #2 temperature value (value of -32768 if not connected)
          Response from BMS [ERROR]
           Byte 1   Byte 2    Byte 3    Byte 4      Byte 5        Byte 6
            0xAA    0x00      0x1B      ERROR      CRC:LSB      CRC:MSB
           www.enepaq.com                                  Revision D, 2025-07-04                                              Page 9
                                                                                                       Tiny BMS Communication Protocols
                       1.1.19. Read battery pack cells voltages
                       Request to BMS
                         Byte 1   Byte 2     Byte 3       Byte 4
                         0xAA      0x1C    CRC:LSB      CRC:MSB
                       Response from BMS [OK]
                        Byte 1   Byte 2   Byte 3    Byte 4      Byte 5      ...    Byte n*2+2   Byte n*2+3    Byte n*2+4    Byte n*2+5
                         0xAA    0x1C      PL    DATA1:LSB DATA1:MSB        ...   DATAn:LSB DATAn:MSB         CRC:LSB       CRC:MSB
                                                        [UINT_16]                         [UINT_16]
                       PL – Payload length in bytes
                       Response from BMS [ERROR]
                         Byte 1   Byte 2     Byte 3      Byte 4       Byte 5        Byte 6
                         0xAA      0x00      0x1C       ERROR       CRC:LSB       CRC:MSB
                       1.1.20. Read Tiny BMS settings values (min, max, default, current)
                       Request to BMS
                        Byte 1 Byte 2           Byte 3           Byte 4   Byte 5       Byte 6        Byte 7
                         0xAA    0x1D          OPTION             0x00      RL       CRC:LSB       CRC:MSB
                                          0x01 – Min. settings
                                          0x02 – Max. settings
                                         0x03 – Default settings
                                        0x04 – Current settings
                       RL – Registers to read. Max. 100 (0x64) registers
                       Response from BMS [OK]
                        Byte 1   Byte 2   Byte 3    Byte 4      Byte 5      ...    Byte n*2+2   Byte n*2+3    Byte n*2+4    Byte n*2+5
                         0xAA    0x1D      PL    DATA1:LSB DATA1:MSB        ...   DATAn:LSB DATAn:MSB         CRC:LSB       CRC:MSB
                                                        [UINT_16]                         [UINT_16]
                       PL – Payload length in bytes
                       Response from BMS [ERROR]
                        Byte 1   Byte 2   Byte 3    Byte 4      Byte 5        Byte 6
                         0xAA     0x00     0x1D     ERROR      CRC:LSB      CRC:MSB
                       1.1.21. Read Tiny BMS version
                       Request to BMS
                        Byte 1   Byte 2      Byte 3        Byte 4
                         0xAA    0x1E      CRC:LSB       CRC:MSB
                       Response from BMS [OK]
                        Byte 1   Byte 2   Byte 3    Byte 4      Byte 5     Byte 6      Byte 7        Byte 8      Byte 9     Byte 10
                         0xAA     0x1E     PL       DATA1       DATA2      DATA3     DATA4:LSB     DATA4:MSB CRC:LSB CRC:MSB
                                                   [UINT_8]    [UINT_8]   [UINT_8]          [UINT_16]
                       PL – Payload length in bytes
                       DATA1 – Hardware version
                       DATA2 – Hardware changes version
                       DATA3 – Firmware public version
                       DATA4 – Firmware internal version
                       Response from BMS [ERROR]
                        Byte 1   Byte 2    Byte 3       Byte 4       Byte 5        Byte 6
                         0xAA     0x00      0x1E       ERROR       CRC:LSB       CRC:MSB
                       1.1.22. Read Tiny BMS extended version
                       Request to BMS
                        Byte 1   Byte 2    Byte 3       Byte 4
                         0xAA     0x1F    CRC:LSB     CRC:MSB
                        www.enepaq.com                                  Revision D, 2025-07-04                                             Page 10
                                                                                         Tiny BMS Communication Protocols
          Response from BMS [OK]
           Byte 1    Byte 2   Byte 3   Byte 4     Byte 5    Byte 6      Byte 7       Byte 8      Byte 9   Byte 10    Byte 11   Byte 12
            0xAA      0x1F      PL     DATA1      DATA2     DATA3     DATA4:LSB DATA4:MSB DATA5            DATA6 CRC:LSBCRC:MSB
                                      [UINT_8] [UINT_8] [UINT_8]             [UINT_16]          [UINT_8] [UINT_8]
          PL – Payload length in bytes
          DATA1 – Hardware version
          DATA2 – Hardware changes version
          DATA3 – Firmware public version
          DATA4 – Firmware internal version
          DATA5 – Bootloader version
          DATA6 – Register map version
          Response from BMS [ERROR]
           Byte 1    Byte 2   Byte 3   Byte 4      Byte 5      Byte 6
            0xAA      0x00     0x1F   ERROR CRC:LSB CRC:MSB
          1.1.23. Read Tiny BMS calculated speed, left distance and estimated time values
          Request to BMS
           Byte 1    Byte 2      Byte 3       Byte 4
            0xAA      0x20     CRC:LSB      CRC:MSB
          Response from BMS [OK]
           Byte 1      Byte 2         Byte 3        Byte 4    Byte 5      Byte 6       Byte 7      Byte 8      Byte 9       Byte 10
            0xAA       0x20         DATA1:LSB       DATA1     DATA1 DATA1:MSB DATA2:LSB            DATA2       DATA2      DATA2:MSB
                                                      [FLOAT]                                            [UINT_32]
            Byte 11     Byte 12    Byte 13      Byte 14       Byte 15     Byte 16
          DATA3:LSB     DATA3       DATA3     DATA3:MSB      CRC:LSB     CRC:MSB
                              [UINT_32]
          DATA1 – Speed (km/h)
          DATA2 – Left distance to empty battery (km)
          DATA3 – Estimated time left to empty battery (seconds)
          Response from BMS [ERROR]
           Byte 1    Byte 2     Byte 3      Byte 4       Byte 5       Byte 6
            0xAA      0x00       0x20      ERROR       CRC:LSB      CRC:MSB
          1.2. CRC checksum calculation
          CRC stands for Cyclic Redundancy Check. It is two bytes added to the end of every command message for 
          error detection. Every byte in the message is used to calculate the CRC value. The receiving device also 
          must calculate the CRC and compare it to the CRC from sending device. If even one bit in the message is 
          received incorrectly, the CRC values will be different and will result in an error. In the Tiny BMS UART 
          communication protocol the CRC checksum is 16 bit value, calculated based on standard MODBUS CRC 
                          16  15   2
          polynomial  x +x +x +1  (0x8005  in  HEX  format). Below is the function example in  C  programming 
          language that can be used as a reference to calculate the 16 bit CRC value:
          const static uint16_t crcTable[256]={
              0x0000, 0xC0C1, 0xC181, 0x0140, 0xC301, 0x03C0, 0x0280, 0xC241,
              0xC601, 0x06C0, 0x0780, 0xC741, 0x0500, 0xC5C1, 0xC481, 0x0440,
              0xCC01, 0x0CC0, 0x0D80, 0xCD41, 0x0F00, 0xCFC1, 0xCE81, 0x0E40,
              0x0A00, 0xCAC1, 0xCB81, 0x0B40, 0xC901, 0x09C0, 0x0880, 0xC841,
              0xD801, 0x18C0, 0x1980, 0xD941, 0x1B00, 0xDBC1, 0xDA81, 0x1A40,
              0x1E00, 0xDEC1, 0xDF81, 0x1F40, 0xDD01, 0x1DC0, 0x1C80, 0xDC41,
              0x1400, 0xD4C1, 0xD581, 0x1540, 0xD701, 0x17C0, 0x1680, 0xD641,
              0xD201, 0x12C0, 0x1380, 0xD341, 0x1100, 0xD1C1, 0xD081, 0x1040,
              0xF001, 0x30C0, 0x3180, 0xF141, 0x3300, 0xF3C1, 0xF281, 0x3240,
              0x3600, 0xF6C1, 0xF781, 0x3740, 0xF501, 0x35C0, 0x3480, 0xF441,
           www.enepaq.com                                  Revision D, 2025-07-04                                             Page 11
                                                                       Tiny BMS Communication Protocols
                   0x3C00, 0xFCC1, 0xFD81, 0x3D40, 0xFF01, 0x3FC0, 0x3E80, 0xFE41,
                   0xFA01, 0x3AC0, 0x3B80, 0xFB41, 0x3900, 0xF9C1, 0xF881, 0x3840,
                   0x2800, 0xE8C1, 0xE981, 0x2940, 0xEB01, 0x2BC0, 0x2A80, 0xEA41,
                   0xEE01, 0x2EC0, 0x2F80, 0xEF41, 0x2D00, 0xEDC1, 0xEC81, 0x2C40,
                   0xE401, 0x24C0, 0x2580, 0xE541, 0x2700, 0xE7C1, 0xE681, 0x2640,
                   0x2200, 0xE2C1, 0xE381, 0x2340, 0xE101, 0x21C0, 0x2080, 0xE041,
                   0xA001, 0x60C0, 0x6180, 0xA141, 0x6300, 0xA3C1, 0xA281, 0x6240,
                   0x6600, 0xA6C1, 0xA781, 0x6740, 0xA501, 0x65C0, 0x6480, 0xA441,
                   0x6C00, 0xACC1, 0xAD81, 0x6D40, 0xAF01, 0x6FC0, 0x6E80, 0xAE41,
                   0xAA01, 0x6AC0, 0x6B80, 0xAB41, 0x6900, 0xA9C1, 0xA881, 0x6840,
                   0x7800, 0xB8C1, 0xB981, 0x7940, 0xBB01, 0x7BC0, 0x7A80, 0xBA41,
                   0xBE01, 0x7EC0, 0x7F80, 0xBF41, 0x7D00, 0xBDC1, 0xBC81, 0x7C40,
                   0xB401, 0x74C0, 0x7580, 0xB541, 0x7700, 0xB7C1, 0xB681, 0x7640,
                   0x7200, 0xB2C1, 0xB381, 0x7340, 0xB101, 0x71C0, 0x7080, 0xB041,
                   0x5000, 0x90C1, 0x9181, 0x5140, 0x9301, 0x53C0, 0x5280, 0x9241,
                   0x9601, 0x56C0, 0x5780, 0x9741, 0x5500, 0x95C1, 0x9481, 0x5440,
                   0x9C01, 0x5CC0, 0x5D80, 0x9D41, 0x5F00, 0x9FC1, 0x9E81, 0x5E40,
                   0x5A00, 0x9AC1, 0x9B81, 0x5B40, 0x9901, 0x59C0, 0x5880, 0x9841,
                   0x8801, 0x48C0, 0x4980, 0x8941, 0x4B00, 0x8BC1, 0x8A81, 0x4A40,
                   0x4E00, 0x8EC1, 0x8F81, 0x4F40, 0x8D01, 0x4DC0, 0x4C80, 0x8C41,
                   0x4400, 0x84C1, 0x8581, 0x4540, 0x8701, 0x47C0, 0x4680, 0x8641,
                   0x8201, 0x42C0, 0x4380, 0x8341, 0x4100, 0x81C1, 0x8081, 0x4040 
                };
                uint16_t CRC16 (const uint8_t* data, uint16_t length)
                {
                   uint8_t tmp;
                   uint16_t crcWord = 0xFFFF;
                   while (length--)
                   {
                      tmp = *data++ ^ crcWord;
                      crcWord >>= 8;
                      crcWord ^= crcTable[tmp];
                   }
                   return crcWord;
                }
                1.3. UART communication examples
                 Note: If Tiny BMS device is in sleep mode, the first command must be send twice. After received the first 
                 command BMS wakes up from sleep mode, but the response to the command will be sent when it 
                 receives the command a second time. Tiny BMS does not enter sleep mode again while communication is 
                 ongoing.
                1.3.1. MODBUS write registers example
                Below is an example, how to configure Over-Voltage Cutoff threshold to 4.2 V value and Under-Voltage 
                Cutoff threshold to 2.5 V value using MODBUS write command:
                Over-Voltage Cutoff register address is 315 (0x013B)
                Under-Voltage Cutoff register address is 316 (0x013C)
                According to 1.1.7 chapter: 
                ADDR = 0x013B (according to Tiny BMS registers map);
                RL=0x02 (write two registers);
                PL=0x04 (all Tiny BMS registers contains two bytes);
                DATA: 4.2 V=4200 mV (0x1068), 2.5 V=2500 mV (0x09C4);
                 www.enepaq.com                   Revision D, 2025-07-04                        Page 12
                                  Tiny BMS Communication Protocols
    CRC = 0x6119.
    Command request bytes sequence to send to BMS according to 1.1.7 chapter:
    0xAA 0x10 0x01 0x3B 0x00 0x02 0x04 0x10 0x68 0x09 0xC4 0x19 0x61.
    If command was sended successfully, BMS responds with data:
    0xAA 0x10 0x01 0x3B 0x00 0x02 0x28 0x22
    Configured registers block address – 0x013B; 
    Configurred two registers – 0x0002; 
    CRC – 0x2228. 
    1.3.2. MODBUS read registers example
    Below is an example, how to read five cells voltages (cell 5 to cell 9) using MODBUS read command:
    According to 1.1.6 chapter: 
    ADDR = 0x0005 (cell 5 address according to Tiny BMS registers map);
    RL=0x05 (read five registers);
    CRC = 0x138C.
    Command request bytes sequence to send to BMS according to 1.1.6 chapter:
    0xAA 0x03 0x00 0x05 0x00 0x05 0x8C 0x13.
    If command was sent successfully, BMS responds with data:
    0xAA 0x03 0x0A 0x97 0x40 0x97 0x40 0x97 0x2C 0x97 0x2C 0x97 0x2C 0x3E 0xC7
    Payload length – 0x0A (10 bytes);
    Cell 5 voltage – 0x9740 (38720 decimal or 3.872 V according to Tiny BMS registers map)
    Cell 6 voltage – 0x9740 (38720 decimal or 3.872 V according to Tiny BMS registers map)
    Cell 7 voltage – 0x972C (38700 decimal or 3.870 V according to Tiny BMS registers map)
    Cell 8 voltage – 0x972C (38700 decimal or 3.870 V according to Tiny BMS registers map)
    Cell 9 voltage – 0x972C (38700 decimal or 3.870 V according to Tiny BMS registers map)
    CRC – 0xC73E. 
    1.3.3. Tiny BMS read temperatures example
    Below is provided an example, how to read temperature values using read Tiny BMS device temperatures 
    command:
    Command request bytes sequence to send to BMS according to 1.1.18 chapter:
    0xAA 0x1B 0x3F 0x1B
    CRC = 0x1B3F.
    If command was sent successfully, BMS responds with data:
    0xAA 0x1B 0x06 0x16 0x01 0x14 0x01 0x16 0x01 0x0E 0x4E
    Payload length – 0x06 (6 bytes);
    Tiny BMS internal temperature – 0x0116 (278 decimal or 27.8 °C according to Tiny BMS registers map)
    Tiny BMS external #1 temperature – 0x0114 (276 decimal or 27.6 °C according to Tiny BMS registers map)
    Tiny BMS external #2 temperature – 0x0116 (278 decimal or 27.8 °C according to Tiny BMS registers map)
    CRC – 0x4E0E. 
     www.enepaq.com    Revision D, 2025-07-04   Page 13
                                                                                                         Tiny BMS Communication Protocols
                        Chapter 2: Tiny BMS CAN bus communication protocol
                        2. Introduction
                        Tiny BMS  device used along with  Enepaq CAN-UART  converter module gives an instant  CAN  bus 
                        connectivity with the user side CAN controller or other industrial equipment. Various proprietary commands 
                        are available for fast  CAN  bus communication. This chapter in detail covers all available commands 
                        implemented to communicate with Tiny BMS device.  An internal Tiny BMS registers map is given in 
                        Chapter 3.
                        Note: CAN bitrate is 500 kbit/s (not allowed to change by the user). Default node ID after firmware update 
                        is 0x01. When multi-slave CAN bus topology is used, node ID can be assigned with 19 Tiny BMS CAN 
                        command. Automatic node ID assignment is not available.
                        Note: Tiny BMS CAN-UART converter works and CAN bus communication is available only when BMS 
                        device is in active state (charging, discharging or Ignition enabled).
                        2.1. CAN bus communication commands list
                        2.1.1. Reset Tiny BMS, clear Events and Statistics
                        Request to BMS
                                 CAN identifier 11 bits                                              8 data bytes*
                        10 9 8 7 6 5 4 3 2 1 0 Byte 1                          Byte 2          Byte 3*  Byte 4*    Byte 5*   Byte 6*   Byte 7*  Byte 8*
                         0 1 0 0 0 Node ID (0x01...0x3F) 0x02                 OPTION            0x00     0x00       0x00      0x00      0x00     0x00
                                        Default node ID - 0x01          0x01 – Clear Events
                                                                       0x02 – Clear Statistics
                                                                         0x05 – Reset BMS
                        * - Last command bytes with zeros can be ignored
                        Response from BMS [OK]
                                 CAN identifier 11 bits          2 data bytes
                        10 9 8 7 6 5 4 3 2 1 0 Byte 1 Byte 2
                         0 1 0 0 1 Node ID (0x01...0x3F) 0x01            0x02
                                        Default node ID - 0x01
                        Response from BMS [ERROR]
                                 CAN identifier 11 bits                 3 data bytes
                        10 9 8 7 6 5 4 3 2 1 0 Byte 1 Byte 2                       Byte 3
                         0 1 0 0 1 Node ID (0x01...0x3F) 0x00            0x02      ERROR
                                        Default node ID - 0x01
                        ERROR – Response error code
                        2.1.2. Read Tiny BMS registers block
                        Request to BMS
                                 CAN identifier 11 bits                                              8 data bytes*
                        10 9 8 7 6 5 4 3 2 1 0 Byte 1                      Byte 2          Byte 3        Byte 4    Byte 5    Byte 6*   Byte 7*  Byte 8*
                         0 1 0 0 0 Node ID (0x01...0x3F) 0x03            ADDR:MSB        ADDR:LSB        0x00        RL       0x00      0x00     0x00
                                        Default node ID - 0x01                    [UINT_16]
                        * - Last command bytes with zeros can be ignored
                        ADDR – Registers block start addresses
                        RL – Registers to read. Max. 127 (0x7F) registers
                        The number of CAN messages responded from BMS is equal to the count of registers requested to read. First CAN message returns 
                        first register value and each other CAN message returns next registers values respectively.
                         www.enepaq.com                                   Revision D, 2025-07-04                                              Page 14
                                                                           Tiny BMS Communication Protocols
         Response from BMS [OK] – MSG 1
                CAN identifier 11 bits                          6 data bytes
         10 9 8 7 6 5 4 3 2 1 0 Byte 1 Byte 2           Byte 3    Byte 4       Byte 5      Byte 6
         0 1 0 0 1 Node ID (0x01...0x3F) 0x01    0x03    PL     DATA1:MSB    DATA1:LSB     0x00
                      Default node ID - 0x01                           [UINT_16]
         Response from BMS [OK] – MSG n
                CAN identifier 11 bits                          6 data bytes
         10 9 8 7 6 5 4 3 2 1 0 Byte 1 Byte 2           Byte 3    Byte 4       Byte 5      Byte 6
         0 1 0 0 1 Node ID (0x01...0x3F) 0x01    0x03    PL     DATAn:MSB    DATAn:LSB      n-1
                      Default node ID - 0x01                           [UINT_16]
        PL – Payload (DATA) length in bytes
        DATA – Registers data
         Response from BMS [ERROR]
                CAN identifier 11 bits          3 data bytes
         10 9 8 7 6 5 4 3 2 1 0 Byte 1 Byte 2            Byte 3
         0 1 0 0 1 Node ID (0x01...0x3F) 0x00    0x03    ERROR
                      Default node ID - 0x01
        ERROR – Response error code
        2.1.3. Write Tiny BMS registers block
        The number of CAN messages sent to BMS is equal to the count of registers requested to write. First CAN message contains start 
        address, register length and first register value and each other CAN message contains next registers values respectively.
         Request to BMS – MSG 1
                CAN identifier 11 bits                                  8 data bytes
         10 9 8 7 6 5 4 3 2 1 0 Byte 1            Byte 2    Byte 3    Byte 4 Byte 5    Byte 6     Byte 7    Byte 8
         0 1 0 0 0 Node ID (0x01...0x3F) 0x10  ADDR:MSB ADDR:LSB      0x00     RL   DATA1:MSB DATA1:LSB     0x00
                      Default node ID - 0x01         [UINT_16]                             [UINT_16]
         Request to BMS – MSG n
                CAN identifier 11 bits                                  8 data bytes
         10 9 8 7 6 5 4 3 2 1 0 Byte 1            Byte 2    Byte 3    Byte 4 Byte 5    Byte 6     Byte 7    Byte 8
         0 1 0 0 0 Node ID (0x01...0x3F) 0x10  ADDR:MSB ADDR:LSB      0x00     RL   DATAn:MSB DATAn:LSB      n-1
                      Default node ID - 0x01         [UINT_16]                             [UINT_16]
        ADDR - Registers block start addresses. Start address can be in range 0x12C to 0x18F
        RL – Registers to write. Max. 100 (0x64) registers
        DATA – Registers data to write
         Response from BMS [OK]
                CAN identifier 11 bits                          6 data bytes
         10 9 8 7 6 5 4 3 2 1 0 Byte 1 Byte 2             Byte 3      Byte 4     Byte 5    Byte 6
         0 1 0 0 1 Node ID (0x01...0x3F) 0x01    0x10   ADDR:MSB    ADDR:LSB      0x00      RL
                      Default node ID - 0x01                   [UINT_16]
        ADDR – Configured registers blosck start address
        RL – Configured registers
         Response from BMS [ERROR]
                CAN identifier 11 bits          3 data bytes
         10 9 8 7 6 5 4 3 2 1 0 Byte 1 Byte 2            Byte 3
         0 1 0 0 1 Node ID (0x01...0x3F) 0x00    0x10    ERROR
                      Default node ID - 0x01
        ERROR – Response error code
        2.1.4. Read Tiny BMS newest Events
         Request to BMS
                CAN identifier 11 bits                                8 data bytes*
         10 9 8 7 6 5 4 3 2 1 0 Byte 1           Byte 2*  Byte 3*  Byte 4*  Byte 5*  Byte 6*  Byte 7*  Byte 8*
         0 1 0 0 0 Node ID (0x01...0x3F)  0x11    0x00     0x00     0x00     0x00     0x00     0x00     0x00
                      Default node ID - 0x01
          www.enepaq.com                          Revision D, 2025-07-04                                  Page 15
                                                                                                       Tiny BMS Communication Protocols
                       * - Last command bytes with zeros can be ignored
                       The number of CAN messages responded from BMS is equal to the count of events requested. First CAN message returns current 
                       BMS timestamp and each other CAN message returns new event ID and timestamp respectively.
                       Response from BMS [OK] – MSG 1
                                CAN identifier 11 bits                                          8 data bytes
                        10 9 8 7 6 5 4 3 2 1 0 Byte 1 Byte 2 Byte 3                       Byte 4     Byte 5    Byte 6      Byte 7      Byte 8
                        0 1 0 0 1 Node ID (0x01...0x3F)        0x01    0x11      PL     BTSP:LSB      BTSP     BTSP      BTSP:MSB       0x00
                                       Default node ID - 0x01                                            [UINT_32]
                       Response from BMS [OK] – MSG n
                                CAN identifier 11 bits                                          8 data bytes
                        10 9 8 7 6 5 4 3 2 1 0 Byte 1 Byte 2 Byte 3                       Byte 4      Byte 5      Byte 6      Byte 7   Byte 8
                        0 1 0 0 1 Node ID (0x01...0x3F)        0x01    0x11      PL      TSPn:LSB      TSPn     TSPn:MSB       IDn       n-1
                                       Default node ID - 0x01                                        [UINT_24]               [UINT_8]
                       PL – Payload (DATA) length in bytes
                       BTSP – Tiny BMS timestamp in seconds
                       TSP – Newest Event timestamp in seconds
                       ID – Event ID
                       Response from BMS [ERROR]
                                CAN identifier 11 bits                3 data bytes
                        10 9 8 7 6 5 4 3 2 1 0 Byte 1 Byte 2                     Byte 3
                        0 1 0 0 1 Node ID (0x01...0x3F) 0x00           0x11      ERROR
                                       Default node ID - 0x01
                       ERROR – Response error code
                       2.1.5. Read Tiny BMS all Events
                       Request to BMS
                                CAN identifier 11 bits                                          8 data bytes*
                        10 9 8 7 6 5 4 3 2 1 0 Byte 1                   Byte 2*   Byte 3*    Byte 4*   Byte 5*    Byte 6*    Byte 7*   Byte 8*
                        0 1 0 0 0 Node ID (0x01...0x3F)        0x12      0x00      0x00       0x00      0x00       0x00       0x00      0x00
                                       Default node ID - 0x01
                       * - Last command bytes with zeros can be ignored
                       The number of CAN messages responded from BMS is equal to the count of events requested. First CAN message returns current 
                       BMS timestamp and each other CAN message returns event ID and timestamp respectively.
                       Response from BMS [OK] – MSG 1
                                CAN identifier 11 bits                                          8 data bytes
                        10 9 8 7 6 5 4 3 2 1 0 Byte 1 Byte 2 Byte 3                       Byte 4     Byte 5    Byte 6      Byte 7      Byte 8
                        0 1 0 0 1 Node ID (0x01...0x3F)        0x01    0x12      PL     BTSP:LSB      BTSP     BTSP      BTSP:MSB       0x00
                                       Default node ID - 0x01                                            [UINT_32]
                       Response from BMS [OK] – MSG n
                                CAN identifier 11 bits                                          8 data bytes
                        10 9 8 7 6 5 4 3 2 1 0 Byte 1 Byte 2 Byte 3                       Byte 4      Byte 5      Byte 6      Byte 7   Byte 8
                        0 1 0 0 1 Node ID (0x01...0x3F)        0x01    0x12      PL      TSPn:LSB      TSPn     TSPn:MSB       IDn       n-1
                                       Default node ID - 0x01                                        [UINT_24]               [UINT_8]
                       PL – Payload (DATA) length in bytes
                       BTSP – Tiny BMS timestamp in seconds
                       TSP – Newest Event timestamp in seconds
                       ID – Event ID
                       Response from BMS [ERROR]
                                CAN identifier 11 bits                3 data bytes
                        10 9 8 7 6 5 4 3 2 1 0 Byte 1 Byte 2                     Byte 3
                        0 1 0 0 1 Node ID (0x01...0x3F) 0x00           0x12      ERROR
                                       Default node ID - 0x01
                       ERROR – Response error code
                        www.enepaq.com                                  Revision D, 2025-07-04                                             Page 16
                                                                                            Tiny BMS Communication Protocols
          2.1.6. Read battery pack voltage (Reg:36)
          Request to BMS
                   CAN identifier 11 bits                                            8 data bytes*
           10 9 8 7 6 5 4 3 2 1 0 Byte 1                    Byte 2*    Byte 3*    Byte 4*   Byte 5*    Byte 6*    Byte 7*    Byte 8*
           0 1 0 0 0 Node ID (0x01...0x3F)         0x14      0x00       0x00       0x00      0x00       0x00       0x00       0x00
                           Default node ID - 0x01
          * - Last command bytes with zeros can be ignored
          Response from BMS [OK]
                   CAN identifier 11 bits                                     6 data bytes
           10 9 8 7 6 5 4 3 2 1 0 Byte 1 Byte 2                        Byte 3       Byte 4      Byte 5       Byte 6
           0 1 0 0 1 Node ID (0x01...0x3F) 0x01            0x14      DATA:LSB        DATA       DATA       DATA:MSB
                           Default node ID - 0x01                                        [FLOAT]
          Response from BMS [ERROR]
                   CAN identifier 11 bits                 3 data bytes
           10 9 8 7 6 5 4 3 2 1 0 Byte 1 Byte 2                       Byte 3
           0 1 0 0 1 Node ID (0x01...0x3F) 0x00             0x14     ERROR
                           Default node ID - 0x01
          ERROR – Response error code
          2.1.7. Read battery pack current (Reg:38)
          Request to BMS
                   CAN identifier 11 bits                                            8 data bytes*
           10 9 8 7 6 5 4 3 2 1 0 Byte 1                    Byte 2*    Byte 3*    Byte 4*   Byte 5*    Byte 6*    Byte 7*    Byte 8*
           0 1 0 0 0 Node ID (0x01...0x3F)         0x15      0x00       0x00       0x00      0x00       0x00       0x00       0x00
                           Default node ID - 0x01
          * - Last command bytes with zeros can be ignored
          Response from BMS [OK]
                   CAN identifier 11 bits                                     6 data bytes
           10 9 8 7 6 5 4 3 2 1 0 Byte 1 Byte 2                        Byte 3       Byte 4      Byte 5       Byte 6
           0 1 0 0 1 Node ID (0x01...0x3F) 0x01            0x15      DATA:LSB        DATA       DATA       DATA:MSB
                           Default node ID - 0x01                                        [FLOAT]
          Response from BMS [ERROR]
                   CAN identifier 11 bits                 3 data bytes
           10 9 8 7 6 5 4 3 2 1 0 Byte 1 Byte 2                       Byte 3
           0 1 0 0 1 Node ID (0x01...0x3F) 0x00             0x15     ERROR
                           Default node ID - 0x01
          ERROR – Response error code
          2.1.8. Read battery pack max. cell voltage (Reg:41)
          Request to BMS
                   CAN identifier 11 bits                                            8 data bytes*
           10 9 8 7 6 5 4 3 2 1 0 Byte 1                    Byte 2*    Byte 3*    Byte 4*   Byte 5*    Byte 6*    Byte 7*    Byte 8*
           0 1 0 0 0 Node ID (0x01...0x3F)         0x16      0x00       0x00       0x00      0x00       0x00       0x00       0x00
                           Default node ID - 0x01
          * - Last command bytes with zeros can be ignored
          Response from BMS [OK]
                   CAN identifier 11 bits                          4 data bytes
           10 9 8 7 6 5 4 3 2 1 0 Byte 1 Byte 2                        Byte 3         Byte 4
           0 1 0 0 1 Node ID (0x01...0x3F) 0x01            0x16      DATA:LSB      DATA:MSB
                           Default node ID - 0x01                           [UINT_16]
            www.enepaq.com                                   Revision D, 2025-07-04                                              Page 17
                                                                                                                  Tiny BMS Communication Protocols
                          Response from BMS [ERROR]
                                    CAN identifier 11 bits                    3 data bytes
                          10 9 8 7 6 5 4 3 2 1 0 Byte 1 Byte 2                             Byte 3
                           0 1 0 0 1 Node ID (0x01...0x3F) 0x00                0x16       ERROR
                                            Default node ID - 0x01
                          ERROR – Response error code
                          2.1.9. Read battery pack min. cell voltage (Reg:40)
                          Request to BMS
                                    CAN identifier 11 bits                                                 8 data bytes*
                          10 9 8 7 6 5 4 3 2 1 0 Byte 1                         Byte 2*     Byte 3*    Byte 4*     Byte 5*     Byte 6*     Byte 7*    Byte 8*
                           0 1 0 0 0 Node ID (0x01...0x3F)            0x17       0x00        0x00        0x00       0x00        0x00        0x00        0x00
                                            Default node ID - 0x01
                          * - Last command bytes with zeros can be ignored
                          Response from BMS [OK]
                                    CAN identifier 11 bits                             4 data bytes
                          10 9 8 7 6 5 4 3 2 1 0 Byte 1 Byte 2                              Byte 3          Byte 4
                           0 1 0 0 1 Node ID (0x01...0x3F) 0x01                0x17      DATA:LSB        DATA:MSB
                                            Default node ID - 0x01                                [UINT_16]
                          Response from BMS [ERROR]
                                    CAN identifier 11 bits                    3 data bytes
                          10 9 8 7 6 5 4 3 2 1 0 Byte 1 Byte 2                             Byte 3
                           0 1 0 0 1 Node ID (0x01...0x3F) 0x00                0x17       ERROR
                                            Default node ID - 0x01
                          ERROR – Response error code
                          2.1.10. Read Tiny BMS online status (Reg:50)
                          Request to BMS
                                    CAN identifier 11 bits                                                 8 data bytes*
                          10 9 8 7 6 5 4 3 2 1 0 Byte 1                         Byte 2*     Byte 3*    Byte 4*     Byte 5*     Byte 6*     Byte 7*    Byte 8*
                           0 1 0 0 0 Node ID (0x01...0x3F)            0x18       0x00        0x00        0x00       0x00        0x00        0x00        0x00
                                            Default node ID - 0x01
                          * - Last command bytes with zeros can be ignored
                          Response from BMS [OK]
                                    CAN identifier 11 bits                             4 data bytes
                          10 9 8 7 6 5 4 3 2 1 0 Byte 1 Byte 2                              Byte 3          Byte 4
                           0 1 0 0 1 Node ID (0x01...0x3F) 0x01                0x18      DATA:LSB        DATA:MSB
                                            Default node ID - 0x01                        0x91 – Charging [INFO]
                                                                                        0x92 – Fully charged [INFO]
                                                                                         0x93 – Discharging [INFO]
                                                                                        0x96 – Regeneration [INFO]
                                                                                             0x97 – Idle [INFO]
                                                                                           0x9B – Fault [ERROR]
                          Response from BMS [ERROR]
                                    CAN identifier 11 bits                    3 data bytes
                          10 9 8 7 6 5 4 3 2 1 0 Byte 1 Byte 2                             Byte 3
                           0 1 0 0 1 Node ID (0x01...0x3F) 0x00                0x18       ERROR
                                            Default node ID - 0x01
                          ERROR – Response error code
                          2.1.11. Read Tiny BMS lifetime counter (Reg:32)
                          Request to BMS
                                    CAN identifier 11 bits                                                 8 data bytes*
                          10 9 8 7 6 5 4 3 2 1 0 Byte 1                         Byte 2*     Byte 3*    Byte 4*     Byte 5*     Byte 6*     Byte 7*    Byte 8*
                           0 1 0 0 0 Node ID (0x01...0x3F)            0x19       0x00        0x00        0x00       0x00        0x00        0x00        0x00
                                            Default node ID - 0x01
                           www.enepaq.com                                       Revision D, 2025-07-04                                                    Page 18
                                                                           Tiny BMS Communication Protocols
        * - Last command bytes with zeros can be ignored
         Response from BMS [OK]
                CAN identifier 11 bits                          6 data bytes
         10 9 8 7 6 5 4 3 2 1 0 Byte 1 Byte 2             Byte 3     Byte 4    Byte 5     Byte 6
         0 1 0 0 1 Node ID (0x01...0x3F) 0x01    0x19    DATA:LSB    DATA      DATA     DATA:MSB
                      Default node ID - 0x01                             [UINT32]
         Response from BMS [ERROR]
                CAN identifier 11 bits          3 data bytes
         10 9 8 7 6 5 4 3 2 1 0 Byte 1 Byte 2            Byte 3
         0 1 0 0 1 Node ID (0x01...0x3F) 0x00    0x19    ERROR
                      Default node ID - 0x01
        ERROR – Response error code
        2.1.12. Read Tiny BMS estimated SOC value (Reg:46)
         Request to BMS
                CAN identifier 11 bits                                8 data bytes*
         10 9 8 7 6 5 4 3 2 1 0 Byte 1           Byte 2*  Byte 3*  Byte 4*  Byte 5*  Byte 6*  Byte 7*  Byte 8*
         0 1 0 0 0 Node ID (0x01...0x3F)  0x1A    0x00     0x00     0x00     0x00     0x00     0x00     0x00
                      Default node ID - 0x01
        * - Last command bytes with zeros can be ignored
         Response from BMS [OK]
                CAN identifier 11 bits                          6 data bytes
         10 9 8 7 6 5 4 3 2 1 0 Byte 1 Byte 2             Byte 3     Byte 4    Byte 5     Byte 6
         0 1 0 0 1 Node ID (0x01...0x3F) 0x01    0x1A    DATA:LSB    DATA      DATA     DATA:MSB
                      Default node ID - 0x01                             [UINT32]
         Response from BMS [ERROR]
                CAN identifier 11 bits          3 data bytes
         10 9 8 7 6 5 4 3 2 1 0 Byte 1 Byte 2            Byte 3
         0 1 0 0 1 Node ID (0x01...0x3F) 0x00    0x1A    ERROR
                      Default node ID - 0x01
        ERROR – Response error code
        2.1.13. Read Tiny BMS device temperatures (Reg:48, Reg:42, Reg:43)
         Request to BMS
                CAN identifier 11 bits                                8 data bytes*
         10 9 8 7 6 5 4 3 2 1 0 Byte 1           Byte 2*  Byte 3*  Byte 4*  Byte 5*  Byte 6*  Byte 7*  Byte 8*
         0 1 0 0 0 Node ID (0x01...0x3F)  0x1B    0x00     0x00     0x00     0x00     0x00     0x00     0x00
                      Default node ID - 0x01
        * - Last command bytes with zeros can be ignored
         Response from BMS [OK] – MSG 1
                CAN identifier 11 bits                          6 data bytes
         10 9 8 7 6 5 4 3 2 1 0 Byte 1 Byte 2           Byte 3     Byte 4       Byte 5     Byte 6
         0 1 0 0 1 Node ID (0x01...0x3F) 0x01    0x1B     PL     DATA1:LSB    DATA1:MSB     0x00
                      Default node ID - 0x01                             [INT_16]
         Response from BMS [OK] – MSG 2
                CAN identifier 11 bits                          6 data bytes
         10 9 8 7 6 5 4 3 2 1 0 Byte 1 Byte 2           Byte 3     Byte 4       Byte 5     Byte 6
         0 1 0 0 1 Node ID (0x01...0x3F) 0x01    0x1B     PL     DATA2:LSB    DATA2:MSB     0x01
                      Default node ID - 0x01                             [INT_16]
         Response from BMS [OK] – MSG 3
                CAN identifier 11 bits                          6 data bytes
         10 9 8 7 6 5 4 3 2 1 0 Byte 1 Byte 2           Byte 3     Byte 4       Byte 5     Byte 6
         0 1 0 0 1 Node ID (0x01...0x3F) 0x01    0x1B     PL     DATA3:LSB    DATA3:MSB     0x02
                      Default node ID - 0x01                             [INT_16]
          www.enepaq.com                          Revision D, 2025-07-04                                  Page 19
                                                                                                                  Tiny BMS Communication Protocols
                          PL – Payload (DATA) length in bytes
                          DATA1 – Tiny BMS internal temperature
                          DATA2 – External temperature sensor #1 temperature value (value of -32768 if not connected)
                          DATA3 – External temperature sensor #2 temperature value (value of -32768 if not connected)
                          Response from BMS [ERROR]
                                    CAN identifier 11 bits                    3 data bytes
                          10 9 8 7 6 5 4 3 2 1 0 Byte 1 Byte 2                             Byte 3
                           0 1 0 0 1 Node ID (0x01...0x3F) 0x00                0x1B       ERROR
                                            Default node ID - 0x01
                          ERROR – Response error code
                          2.1.14. Read battery pack cells voltages
                          Request to BMS
                                    CAN identifier 11 bits                                                 8 data bytes*
                          10 9 8 7 6 5 4 3 2 1 0 Byte 1                         Byte 2*     Byte 3*    Byte 4*     Byte 5*     Byte 6*     Byte 7*    Byte 8*
                           0 1 0 0 0 Node ID (0x01...0x3F)            0x1C       0x00        0x00        0x00       0x00        0x00        0x00        0x00
                                            Default node ID - 0x01
                          * - Last command bytes with zeros can be ignored
                          BMS response returned CAN messages are equal to battery cells count. First CAN message returns first cell voltage and each other 
                          CAN message returns next cells voltages respectively.
                          Response from BMS [OK] – MSG 1
                                    CAN identifier 11 bits                                          6 data bytes
                          10 9 8 7 6 5 4 3 2 1 0 Byte 1 Byte 2                           Byte 3        Byte 4            Byte 5        Byte 6
                           0 1 0 0 1 Node ID (0x01...0x3F) 0x01                0x1C        PL       DATA1:LSB         DATA1:MSB         0x00
                                            Default node ID - 0x01                                            [UINT_16]
                          Response from BMS [OK] – MSG n
                                    CAN identifier 11 bits                                          6 data bytes
                          10 9 8 7 6 5 4 3 2 1 0 Byte 1 Byte 2                           Byte 3        Byte 4            Byte 5        Byte 6
                           0 1 0 0 1 Node ID (0x01...0x3F) 0x01                0x1C        PL       DATAn:LSB         DATAn:MSB          n-1
                                            Default node ID - 0x01                                            [UINT_16]
                          PL – Payload (DATA) length in bytes
                          Response from BMS [ERROR]
                                    CAN identifier 11 bits                    3 data bytes
                          10 9 8 7 6 5 4 3 2 1 0 Byte 1 Byte 2                             Byte 3
                           0 1 0 0 1 Node ID (0x01...0x3F) 0x00                0x1C       ERROR
                                            Default node ID - 0x01
                          ERROR – Response error code
                          2.1.15. Read Tiny BMS settings values (min, max, default, current)
                          Request to BMS
                                    CAN identifier 11 bits                                                 8 data bytes*
                          10 9 8 7 6 5 4 3 2 1 0 Byte 1                               Byte 2            Byte 3    Byte 4 Byte 5* Byte 6* Byte 7* Byte 8*
                           0 1 0 0 0 Node ID (0x01...0x3F) 0x1D                      OPTION              0x00       RL      0x00      0x00     0x00      0x00
                                            Default node ID - 0x01             0x01 – Min. settings
                                                                              0x02 – Max. settings
                                                                             0x03 – Default settings
                                                                             0x04 – Current settings
                          * - Last command bytes with zeros can be ignored
                          RL – Registers to read. Max. 100 (0x64) registers
                          The number of CAN messages responded from BMS is equal to the count of settings registers requested. First CAN message returns 
                          first register and each other CAN message returns next registers respectively.
                          Response from BMS [OK] – MSG 1
                                    CAN identifier 11 bits                                          6 data bytes
                          10 9 8 7 6 5 4 3 2 1 0 Byte 1 Byte 2                           Byte 3        Byte 4            Byte 5        Byte 6
                           0 1 0 0 1 Node ID (0x01...0x3F) 0x01                0x1D        PL       DATA1:LSB         DATA1:MSB         0x00
                                            Default node ID - 0x01                                            [UINT_16]
                           www.enepaq.com                                       Revision D, 2025-07-04                                                    Page 20
                                                                           Tiny BMS Communication Protocols
         Response from BMS [OK] – MSG n
                CAN identifier 11 bits                          6 data bytes
         10 9 8 7 6 5 4 3 2 1 0 Byte 1 Byte 2           Byte 3     Byte 4       Byte 5     Byte 6
         0 1 0 0 1 Node ID (0x01...0x3F) 0x01    0x1D     PL     DATAn:LSB    DATAn:MSB      n-1
                      Default node ID - 0x01                            [UINT_16]
        PL – Payload (DATA) length in bytes
         Response from BMS [ERROR]
                CAN identifier 11 bits          3 data bytes
         10 9 8 7 6 5 4 3 2 1 0 Byte 1 Byte 2            Byte 3
         0 1 0 0 1 Node ID (0x01...0x3F) 0x00    0x1D    ERROR
                      Default node ID - 0x01
        ERROR – Response error code
        2.1.16. Read Tiny BMS version
         Request to BMS
                CAN identifier 11 bits                                8 data bytes*
         10 9 8 7 6 5 4 3 2 1 0 Byte 1           Byte 2*  Byte 3*  Byte 4*  Byte 5*  Byte 6*  Byte 7*  Byte 8*
         0 1 0 0 0 Node ID (0x01...0x3F)  0x1E    0x00     0x00     0x00     0x00     0x00     0x00     0x00
                      Default node ID - 0x01
        * - Last command bytes with zeros can be ignored
         Response from BMS [OK]
                CAN identifier 11 bits                                8 data bytes
         10 9 8 7 6 5 4 3 2 1 0 Byte 1 Byte 2 Byte 3           Byte 4  Byte 5  Byte 6    Byte 7      Byte 8
         0 1 0 0 1 Node ID (0x01...0x3F)  0x01   0x1E   PL    DATA1   DATA2    DATA3   DATA4:LSB   DATA4:MSB
                      Default node ID - 0x01                  [UINT_8] [UINT_8] [UINT_8]      [UINT_16]
        PL – Payload (DATA) length in bytes
        DATA1 – Hardware version
        DATA2 – Hardware changes version
        DATA3 – Firmware public version
        DATA4 – Firmware internal version
         Response from BMS [ERROR]
                CAN identifier 11 bits          3 data bytes
         10 9 8 7 6 5 4 3 2 1 0 Byte 1 Byte 2            Byte 3
         0 1 0 0 1 Node ID (0x01...0x3F) 0x00    0x1E    ERROR
                      Default node ID - 0x01
        ERROR – Response error code
        2.1.17. Read Tiny BMS calculated speed, left distance and estimated time values
         Request to BMS
                CAN identifier 11 bits                                8 data bytes*
         10 9 8 7 6 5 4 3 2 1 0 Byte 1           Byte 2*  Byte 3*  Byte 4*  Byte 5*  Byte 6*  Byte 7*  Byte 8*
         0 1 0 0 0 Node ID (0x01...0x3F)  0x20    0x00     0x00     0x00     0x00     0x00     0x00     0x00
                      Default node ID - 0x01
        * - Last command bytes with zeros can be ignored
         Response from BMS [OK] – MSG 1
                CAN identifier 11 bits                                8 data bytes
         10 9 8 7 6 5 4 3 2 1 0 Byte 1 Byte 2 Byte 3            Byte 4    Byte 5   Byte 6    Byte 7    Byte 8
         0 1 0 0 1 Node ID (0x01...0x3F) 0x01    0x20    PL   DATA1:LSB   DATA1    DATA1   DATA1:MSB    0x00
                      Default node ID - 0x01                                  [FLOAT]
         Response from BMS [OK] – MSG 2
                CAN identifier 11 bits                                8 data bytes
         10 9 8 7 6 5 4 3 2 1 0 Byte 1 Byte 2 Byte 3            Byte 4    Byte 5   Byte 6    Byte 7    Byte 8
         0 1 0 0 1 Node ID (0x01...0x3F) 0x01    0x20    PL   DATA2:LSB   DATA2    DATA2   DATA2:MSB    0x01
                      Default node ID - 0x01                                 [UINT_32]
          www.enepaq.com                          Revision D, 2025-07-04                                  Page 21
                                                                                      Tiny BMS Communication Protocols
                    Response from BMS [OK] – MSG 3
                           CAN identifier 11 bits                                8 data bytes
                    10 9 8 7 6 5 4 3 2 1 0 Byte 1 Byte 2 Byte 3            Byte 4    Byte 5   Byte 6    Byte 7    Byte 8
                    0 1 0 0 1 Node ID (0x01...0x3F) 0x01    0x20    PL   DATA3:LSB   DATA3    DATA3   DATA3:MSB    0x02
                                 Default node ID - 0x01                                 [UINT_32]
                    PL – Payload length in bytes
                    DATA1 – Speed (km/h)
                    DATA2 – Left distance to empty battery (km)
                    DATA3 – Estimated time left to empty battery (seconds)
                    Response from BMS [ERROR]
                           CAN identifier 11 bits          3 data bytes
                    10 9 8 7 6 5 4 3 2 1 0 Byte 1 Byte 2             Byte 3
                    0 1 0 0 1 Node ID (0x01...0x3F) 0x00    0x20    ERROR
                                 Default node ID - 0x01
                    ERROR – Response error code
                    2.1.18. Read CAN node ID
                    Request to BMS
                           CAN identifier 11 bits                                8 data bytes*
                    10 9 8 7 6 5 4 3 2 1 0 Byte 1            Byte 2* Byte 3*  Byte 4*  Byte 5*  Byte 6*  Byte 7*  Byte 8*
                    0 1 0 0 0 0 0 0 0 0 0            0x28    0x00     0x00     0x00     0x00     0x00     0x00     0x00
                    * - Last command bytes with zeros can be ignored
                    Response from BMS [OK]
                           CAN identifier 11 bits          3 data bytes
                    10 9 8 7 6 5 4 3 2 1 0 Byte 1 Byte 2             Byte 3
                    0 1 0 0 1 Node ID (0x01...0x3F) 0x01    0x28     DATA
                                 Default node ID - 0x01
                    DATA – CAN-UART converter CAN node ID (0x01 to 0x3F)
                    Response from BMS [ERROR]
                           CAN identifier 11 bits          3 data bytes
                    10 9 8 7 6 5 4 3 2 1 0 Byte 1 Byte 2             Byte 3
                    0 1 0 0 1 Node ID (0x01...0x3F) 0x00    0x28    ERROR
                                 Default node ID - 0x01
                    ERROR – Response error code
                    2.1.19. Write CAN node ID
                    Request to BMS
                           CAN identifier 11 bits                                8 data bytes*
                    10 9 8 7 6 5 4 3 2 1 0 Byte 1            Byte 2  Byte 3*  Byte 4*  Byte 5*  Byte 6*  Byte 7*  Byte 8*
                    0 1 0 0 0 Old ID (0x01...0x3F)   0x29    DATA     0x00     0x00     0x00     0x00     0x00     0x00
                    * - Last command bytes with zeros can be ignored
                    DATA - CAN-UART converter CAN node new ID (0x01 to 0x3F)
                    Response from BMS [OK]
                           CAN identifier 11 bits          3 data bytes
                    10 9 8 7 6 5 4 3 2 1 0 Byte 1 Byte 2             Byte 3
                    0 1 0 0 1 New ID (0x01...0x3F)   0x01   0x29     DATA
                    DATA – CAN-UART converter CAN node new ID (0x01 to 0x3F)
                    Response from BMS [ERROR]
                           CAN identifier 11 bits          3 data bytes
                    10 9 8 7 6 5 4 3 2 1 0 Byte 1 Byte 2             Byte 3
                    0 1 0 0 1 New ID (0x01...0x3F)   0x00   0x28    ERROR
                    ERROR – Response error code
                     www.enepaq.com                          Revision D, 2025-07-04                                  Page 22
                                                                                                 Tiny BMS Communication Protocols
           Chapter 3: Tiny BMS registers map
           3. Introduction
           This chapter in detail covers all an internal Tiny BMS registers map.
           3.1. Tiny BMS Live data
           Reg. Nr.    0      1      2       3      4      5       6      7       8       9      10     11      12     13      14     15    Action
               0                                        Cell 1 Voltage [UINT_16] / Resolution 0.1 mV                                          R
               1                                        Cell 2 Voltage [UINT_16] / Resolution 0.1 mV                                          R
               2                                        Cell 3 Voltage [UINT_16] / Resolution 0.1 mV                                          R
               3                                        Cell 4 Voltage [UINT_16] / Resolution 0.1 mV                                          R
               4                                        Cell 5 Voltage [UINT_16] / Resolution 0.1 mV                                          R
               5                                        Cell 6 Voltage [UINT_16] / Resolution 0.1 mV                                          R
               6                                        Cell 7 Voltage [UINT_16] / Resolution 0.1 mV                                          R
               7                                        Cell 8 Voltage [UINT_16] / Resolution 0.1 mV                                          R
               8                                        Cell 9 Voltage [UINT_16] / Resolution 0.1 mV                                          R
               9                                        Cell 10 Voltage [UINT_16] / Resolution 0.1 mV                                         R
              10                                        Cell 11 Voltage [UINT_16] / Resolution 0.1 mV                                         R
              11                                        Cell 12 Voltage [UINT_16] / Resolution 0.1 mV                                         R
              12                                        Cell 13 Voltage [UINT_16] / Resolution 0.1 mV                                         R
              13                                        Cell 14 Voltage [UINT_16] / Resolution 0.1 mV                                         R
              14                                        Cell 15 Voltage [UINT_16] / Resolution 0.1 mV                                         R
              15                                        Cell 16 Voltage [UINT_16] / Resolution 0.1 mV                                         R
             16-31                                                         Reserved                                                           R
              32                                      BMS Lifetime Counter [UINT_32] / Resolution 1 s                                         R
              33
              34                                        Estimated Time Left [UINT_32] / Resolution 1 s                                        R
              35
              36                                        Battery Pack Voltage [FLOAT] / Resolution 1 V                                         R
              37
              38                                        Battery Pack Current [FLOAT] / Resolution 1 A                                         R
              39
              40                                      Minimal Cell Voltage [UINT_16] / Resolution 1 mV                                        R
              41                                      Maximal Cell Voltage [UINT_16] / Resolution 1 mV                                        R
              42                             External Temp. Sensor #1 Temperature [INT_16] / Resolution 0.1 °C                                R
              43                             External Temp. Sensor #2 Temperature [INT_16] / Resolution 0.1 °C                                R
              44                                 Distance Left To Empty Battery [UINT_16] / Resolution 1 km                                   R
              45                                State Of Health [UINT_16] [0 to 50000] / Resolution 0.002 %                                   R
              46                                     State Of Charge [UINT_32] / Resolution 0.000001 %                                        R
              47
              48                                   BMS Internal Temperature [INT_16] / Resolution 0.1 °C                                      R
              49                                                           Reserved                                                           R
              50                            BMS Online Status [UINT_16] / 0x91-Charging, 0x92-Fully Charged,                                  R
                                                 0x93-Discharging, 0x96-Regenertion, 0x97-Idle, 0x9B-Fault
              51      Balancing Decision Bits [UINT_16] / First Cell - LSB Bit of LSB Byte: 1 - need balancing, 0 - cell no need balance      R
              52               Real Balancing Bits [UINT_16] / First Cell - LSB Bit of LSB Byte: 1 - balancing, 0 – not balancing             R
              53                                             Number Of Detected Cells [UINT_16]                                               R
              54                                                     Speed [FLOAT] km/h                                                       R
              55                                                                                                                              R
             56-99                                                         Reserved                                                           R
           3.2. Tiny BMS Statistics data
           Reg. Nr.    0      1      2       3      4      5       6      7       8       9      10     11      12     13      14     15    Action
              100                                       Total Distance [UINT_32] / Resolution 0.01 km                                         R
              101
              102                                Maximal Discharge Current [UINT_16] / Resolution 100 mA                                      R
              103                                  Maximal Charge Current [UINT_16] / Resolution 100 mA                                       R
              104                              Maximal Cell Voltage Difference [UINT_16] / Resolution 0.1 mV                                  R
              105                              Under-Voltage Protection Count [UINT_16] / Resolution 1 count                                  R
              106                               Over-Voltage Protection Count [UINT_16] / Resolution 1 count                                  R
            www.enepaq.com                                      Revision D, 2025-07-04                                                  Page 23
                                                                                                         Tiny BMS Communication Protocols
                          107                         Discharge Over-Current Protection Count [UINT_16] / Resolution 1 count                        R
                          108                          Charge Over-Curent Protection Count [UINT_16] / Resolution 1 count                           R
                          109                               Over-Heat Protection Count [UINT_16] / Resolution 1 count                               R
                           110                                                      Reserved                                                        R
                           111                                    Charging Count [UINT_16] / Resolution 1 count                                     R
                           112                                   Full Charge Count [UINT_16] / Resolution 1 count                                   R
                           113       Min. Pack Temperature [INT_8] / Resolution 1 °C         Max. Pack Temperature [INT_8] / Resolution 1 °C        R
                                            Last BMS Reset Event [UINT_8] /               Last Wakeup From BMS Sleep Mode Event [UINT_8] /
                                         0x00-Unknown, 0x01-Low power reset,                     0x00-Charger connected, 0x01-Ignition, 
                           114                0x02-Window watchdog reset,                              0x02-Discharging detected,                   R
                                 0x03-Independent watchdog reset, 0x04-Software reset,             0x03-UART communication detected
                                          0x05-POR/PDR reset, 0x06-PIN reset, 
                                             0x07-Options bytes loading reset
                           115                                                      Reserved                                                        R
                           116                            Statistics Last Cleared On Tmestamp [UINT_32] / Resolution 1s                             R
                           117
                        118-199                                                     Reserved                                                        R
                        3.3. Tiny BMS Events data
                        Reg. Nr.   0      1      2      3      4      5      6      7      8      9      10     11     12      13     14     15   Action
                          200                                   Event_0 Timestamp [UINT_24 LSB] / Resolution 1 s                                    R
                          201      Event_0 Timestamp [UINT_24 MSB] / Resolution 1 s                  Event_0 Message ID* [UINT_8]                   R
                          202                                   Event_1 Timestamp [UINT_24 LSB] / Resolution 1 s                                    R
                          203      Event_1 Timestamp [UINT_24 MSB] / Resolution 1 s                  Event_1 Message ID* [UINT_8]                   R
                          204                                   Event_2 Timestamp [UINT_24 LSB] / Resolution 1 s                                    R
                          205      Event_2 Timestamp [UINT_24 MSB] / Resolution 1 s                  Event_2 Message ID* [UINT_8]                   R
                          206                                   Event_3 Timestamp [UINT_24 LSB] / Resolution 1 s                                    R
                          207      Event_3 Timestamp [UINT_24 MSB] / Resolution 1 s                  Event_3 Message ID* [UINT_8]                   R
                           ...                                                          ...                                                         ...
                           ...                              ...                                                     ...                             ...
                          296                                  Event_48 Timestamp [UINT_24 LSB] / Resolution 1 s                                    R
                          297      Event_48 Timestamp [UINT_24 MSB] / Resolution 1 s                 Event_48 Message ID* [UINT_8]                  R
                          298                                                       Reserved                                                        R
                          299                                                       Reserved                                                        R
                        * - Events messages ID list is attached in the Chapter 4.
                        3.4. Tiny BMS settings
                        Reg. Nr.   0      1      2      3      4      5      6      7      8      9      10     11     12      13     14     15   Action
                          300                            Fully Charged Voltage [UINT_16] [1200 to 4500] / Resolution 1 mV                          R/W
                          301                          Fully Discharged Voltage [UINT_16] [1000 to 3500] / Resolution 1 mV                         R/W
                          302                                                       Reserved                                                       R/W
                          303                          Early Balancing Threshold [UINT_16] [1000 to 4500] / Resolution 1 mV                        R/W
                          304                           Charge Finished Current [UINT_16] [100 to 5000]* / Resolution 1 mA                         R/W
                          305                                Peak Discharge Current Cutoff [UINT_16] /Resolution 1 A                               R/W
                          306                              Battery Capacity [UINT_16] [10 to 65500] / Resolution 0.01 Ah                           R/W
                          307                           Number Of Series Cells [UINT_16] [4 to 16] / Resolution 1 cell count                       R/W
                          308                               Allowed Disbalance [UINT_16] [15 to 100] / Resolution 1 mV                             R/W
                          309                                                       Reserved                                                       R/W
                          310                              Charger Startup Delay [UINT_16] [5 to 60] / Resolution 1 sec.                           R/W
                           311                             Charger Disable Delay [UINT_16] [0 to 60] / Resolution 1 sec.                           R/W
                          312                           Pulses Per Unit [UINT_32] [1 to 100000] / Resolution 1 pulse per unit                      R/W
                          313
                          314              Distance Unit Name [UINT_16] / 0x01-Meter, 0x02-Kilometer, 0x03-Feet, 0x04-Mile, 0x05-Yard              R/W
                          315                             Over-Voltage Cutoff [UINT_16] [1200 to 4500] / Resolution 1 mV                           R/W
                          316                             Under-Voltage Cutoff [UINT_16] [800 to 3500] / Resolution 1 mV                           R/W
                          317                           Discharge Over-Current Cutoff [UINT_16] [1 to 750]* / Resolution 1 A                       R/W
                          318                            Charge Over-Current Cutoff [UINT_16] [1 to 750]* / Resolution 1 A                         R/W
                          319                                 Over-Heat Cutoff [INT_16] [+20 to +90] / Resolution 1 °C                             R/W
                          320                         Low Temperature Charger Cutoff [INT_16] [-40 to +10] / Resolution 1 °C                       R/W
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

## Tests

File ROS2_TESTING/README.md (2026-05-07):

# ROS2 Testing

Post-test analysis scripts for ROS2 bag files recorded on a Raspberry Pi. Each folder corresponds to a test session and contains scripts to extract and process data from `.mcap` bag files into CSV format for analysis.

## Test Sessions

| Folder | Date | Description |
|---|---|---|
| `gnss_test_07-03-2026` | 07 Mar 2026 | GPS fix, velocity and diagnostics |
| `imu_test_07-03-2026` | 07 Mar 2026 | IMU data |
| `imu_test_2_16-03-2026` | 16 Mar 2026 | IMU data (second run) |
| `iridium_node_test_08-03-2026` | 08 Mar 2026 | Iridium modem node |
| `iridium_gnss_signal_test` | — | Iridium signal strength with GNSS |
| `iridium_gnss_test2_21-03-2026` | 21 Mar 2026 | Iridium and GNSS (second run) |
| `iridium_gnss_test4_22-03-2026` | 22 Mar 2026 | Iridium and GNSS (fourth run) |
| `pressure_test_16-03-2026` | 16 Mar 2026 | Fluid pressure and temperature |
| `sonar_test_14-03-2026` | 14 Mar 2026 | Sonar |
| `sonar_water_test_v2-20-04-2026` | 20 Apr 2026 | Sonar in water (v2) |

## Scripts

Each session folder typically contains one or more of these:

- `bag_to_csv.py` — extracts all topics from the bag into CSV files
- `split.py` — splits specific topics into separate CSV files
- `plot.py` / `graph.py` — plots extracted data

## Requirements

```
mcap
mcap-ros2-support
pandas
matplotlib
numpy
```

Install with:

```bash
pip install mcap mcap-ros2-support pandas matplotlib numpy
```

## Usage

Set the `MCAP_FILE` variable in each script to your bag file, then run:

```bash
python bag_to_csv.py
```

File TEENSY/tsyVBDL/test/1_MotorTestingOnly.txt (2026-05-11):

#include <Arduino.h>
#include "config/pin_map.hpp"
#include "config/constants.hpp"
#include "utils/logger.hpp"
#include "drivers/encoder.hpp"
#include "drivers/motor_driver.hpp"
#include "controllers/estimator.hpp"

// --- Encoder ---
static EncoderDriver enc({
  .pin_a = PIN_ENC_A,
  .pin_b = PIN_ENC_B,
  .pin_z = PIN_ENC_Z,

  .counts_per_rev = config::COUNTS_PER_SCREW_REV,
  .lead_screw_pitch_mm = config::LEAD_SCREW_MM_PER_REV
});

// --- Motor ---
static MotorDriver motor({
  .pin_pwm = PIN_MOTOR_PWM,
  .pin_dir = PIN_MOTOR_DIR,
  .pin_slp = PIN_MOTOR_SLP,
  .pin_flt = PIN_MOTOR_FLT,
  .pin_cs  = PIN_MOTOR_CS,

  .pwm_freq_hz = 25000.0f,
  .pwm_max = 255,

  .flt_active_low = true,

  .cs_volts_per_amp = 0.04f,
  .adc_ref_volts = 3.3f,
  .adc_bits = 12
});

static Estimator estimator;

enum class Phase {
  RAMP_UP,
  HOLD,
  RAMP_DOWN
};

enum class ControlMode {
  AUTO_PROFILE,
  MANUAL
};

Phase phase = Phase::RAMP_UP;
ControlMode mode = ControlMode::MANUAL;

int pwm = 0;
const int PWM_MAX = 240;
const int PWM_STEP = 1;

bool forward = true;

uint32_t lastUpdate = 0;
uint32_t phaseStart = 0;
uint32_t lastPrint = 0;

uint32_t lastEstimatorUpdate = 0;

const uint32_t PRINT_INTERVAL_MOVING = 1000;  // ms
const uint32_t PRINT_INTERVAL_IDLE   = 5000; // ms

// Serial command buffer
String cmdBuffer;

// -----------------------------
// Helpers
// -----------------------------
void printHelp() {
  Serial.println("\n=== Commands ===");
  Serial.println("h / help   -> show help");
  Serial.println("m          -> manual mode");
  Serial.println("a          -> auto trapezoid mode");
  Serial.println("f          -> direction forward / extend");
  Serial.println("b          -> direction backward / retract");
  Serial.println("p<number>  -> set PWM, example: p120");
  Serial.println("s          -> stop motor (PWM=0)");
  Serial.println("z          -> zero encoder counts");
  Serial.println("status     -> print current status");
  Serial.println();
}

bool isMoving() {
  return pwm > 0;
}

void applyDirection() {
  motor.setDirection(
    forward ? MotorDriver::Direction::EXTEND
            : MotorDriver::Direction::RETRACT
  );
}

void printStatus() {
  Serial.print("mode=");
  Serial.print(mode == ControlMode::AUTO_PROFILE ? "AUTO" : "MANUAL");

  Serial.print("  pwm=");
  Serial.print(pwm);

  Serial.print("  dir=");
  Serial.print(forward ? "F" : "B");

  Serial.print("  phase=");
  Serial.print(
    phase == Phase::RAMP_UP ? "UP" :
    phase == Phase::HOLD    ? "HOLD" : "DOWN"
  );

  Serial.print("  counts=");
  Serial.print(enc.readCounts());

  Serial.print("  mm=");
  Serial.print(enc.readPositionMm(), 4);

  Serial.println();
}

void handleCommand(String cmd) {
  cmd.trim();
  cmd.toLowerCase();

  if (cmd.length() == 0) return;

  if (cmd == "h" || cmd == "help") {
    printHelp();
  }
  else if (cmd == "m") {
    mode = ControlMode::MANUAL;
    Serial.println("Switched to MANUAL mode");
  }
  else if (cmd == "a") {
    mode = ControlMode::AUTO_PROFILE;
    phase = Phase::RAMP_UP;
    phaseStart = millis();
    Serial.println("Switched to AUTO profile mode");
  }
  else if (cmd == "f") {
    forward = true;
    applyDirection();
    Serial.println("Direction = FORWARD / EXTEND");
  }
  else if (cmd == "b") {
    forward = false;
    applyDirection();
    Serial.println("Direction = BACKWARD / RETRACT");
  }
  else if (cmd.startsWith("p")) {
    int newPwm = cmd.substring(1).toInt();
    newPwm = constrain(newPwm, 0, 255);
    pwm = newPwm;
    motor.setPWM(pwm);

    Serial.print("PWM set to ");
    Serial.println(pwm);
  }
  else if (cmd == "s") {
    pwm = 0;
    motor.setPWM(0);
    Serial.println("Motor stopped");
  }
  else if (cmd == "z") {
    enc.writeCounts(0);
    Serial.println("Encoder zeroed");
  }
  else if (cmd == "status") {
    printStatus();
  }
  else {
    Serial.print("Unknown command: ");
    Serial.println(cmd);
    printHelp();
  }
}

void readSerialCommands() {
  while (Serial.available()) {
    char c = Serial.read();

    if (c == '\n' || c == '\r') {
      if (cmdBuffer.length() > 0) {
        handleCommand(cmdBuffer);
        cmdBuffer = "";
      }
    } else {
      cmdBuffer += c;
    }
  }
}

// -----------------------------
// Setup
// -----------------------------
void setup() {
  logger::begin(115200);
  Serial.begin(115200);

  LOGI("Trapezoidal Motion Test");

  enc.begin();
  enc.writeCounts(0);

  motor.begin();
  motor.enable();

  applyDirection();

  phaseStart = millis();

  delay(500);
  printHelp();
  printStatus();
}

// -----------------------------
// Main loop
// -----------------------------
void loop() {
  readSerialCommands();

  // Safety
  if (motor.faultActive()) {
    motor.stop();
    LOGE("MOTOR FAULT!");
    Serial.println("MOTOR FAULT!");
    while (1);
  }

  uint32_t now = millis();

  // --- AUTO MOTION PROFILE ---
  if (mode == ControlMode::AUTO_PROFILE && (now - lastUpdate >= 10)) {
    lastUpdate = now;

    switch (phase) {
      case Phase::RAMP_UP:
        pwm += PWM_STEP;
        if (pwm >= PWM_MAX) {
          pwm = PWM_MAX;
          phase = Phase::HOLD;
          phaseStart = now;
        }
        break;

      case Phase::HOLD:
        if (now - phaseStart > 1500) {
          phase = Phase::RAMP_DOWN;
        }
        break;

      case Phase::RAMP_DOWN:
        pwm -= PWM_STEP;
        if (pwm <= 0) {
          pwm = 0;

          forward = !forward;
          applyDirection();

          phase = Phase::RAMP_UP;
        }
        break;
    }

    motor.setPWM(pwm);
  }

  // --- PERIODIC STATUS PRINT ---
  bool moving = isMoving();
  uint32_t interval = moving ? PRINT_INTERVAL_MOVING
                             : PRINT_INTERVAL_IDLE;

  if (now - lastPrint >= interval) {
    lastPrint = now;

    if (moving) {
      Serial.print("[MOV] ");
    } else {
      Serial.print("[IDLE] ");
    }

    printStatus();
  }
}

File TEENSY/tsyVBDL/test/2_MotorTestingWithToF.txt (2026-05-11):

#include <Arduino.h>
#include "config/pin_map.hpp"
#include "config/constants.hpp"
#include "utils/logger.hpp"
#include "drivers/enc_alt.hpp"
#include "drivers/motor_driver.hpp"
#include "controllers/estimator.hpp"
#include "drivers/tof_sensor.hpp"

// --- Encoder ---
static EncoderAlt enc({
  .channel = 2,

  .pin_a = PIN_ENC_A,
  .pin_b = PIN_ENC_B,

  .counts_per_rev = config::COUNTS_PER_SCREW_REV,
  .lead_screw_pitch_mm = config::LEAD_SCREW_MM_PER_REV
});

// --- Motor ---
static MotorDriver motor({
  .pin_pwm = PIN_MOTOR_PWM,
  .pin_dir = PIN_MOTOR_DIR,
  .pin_slp = PIN_MOTOR_SLP,
  .pin_flt = PIN_MOTOR_FLT,
  .pin_cs  = PIN_MOTOR_CS,

  .pwm_freq_hz = 25000.0f,
  .pwm_max = 255,

  .flt_active_low = true,

  .cs_volts_per_amp = 0.04f,
  .adc_ref_volts = 3.3f,
  .adc_bits = 12
});

static Estimator estimator({
  .mm_per_count      = config::MM_PER_COUNT,
  .tof_gain          = config::TOF_FUSION_GAIN,
  .recovery_gain     = config::SLIP_RECOVERY_GAIN,
  .slip_detect_mm    = config::SLIP_DETECT_MM,
  .tof_min_valid_mm  = config::TOF_MIN_VALID_MM
});

static ToFSensor tof(PIN_TOF_SDA, PIN_TOF_SCL);

enum class Phase {
  RAMP_UP,
  HOLD,
  RAMP_DOWN
};

enum class ControlMode {
  AUTO_PROFILE,
  MANUAL
};

Phase phase = Phase::RAMP_UP;
ControlMode mode = ControlMode::MANUAL;

int pwm = 0;
const int PWM_MAX = 240;
const int PWM_STEP = 1;

bool forward = true;

uint32_t lastUpdate = 0;
uint32_t phaseStart = 0;
uint32_t lastPrint = 0;

uint32_t lastEstimatorUpdate = 0;

const uint32_t PRINT_INTERVAL_MOVING = 1000;  // ms
const uint32_t PRINT_INTERVAL_IDLE   = 5000; // ms

Estimator::Output lastEst{};

// Serial command buffer
String cmdBuffer;

// -----------------------------
// Helpers
// -----------------------------
void printHelp() {
  Serial.println("\n=== Commands ===");
  Serial.println("h / help   -> show help");
  Serial.println("m          -> manual mode");
  Serial.println("a          -> auto trapezoid mode");
  Serial.println("f          -> direction forward / extend");
  Serial.println("b          -> direction backward / retract");
  Serial.println("p<number>  -> set PWM, example: p120");
  Serial.println("s          -> stop motor (PWM=0)");
  Serial.println("z          -> zero encoder counts");
  Serial.println("status     -> print current status");
  Serial.println();
}

bool isMoving() {
  return pwm > 0;
}

void applyDirection() {
  motor.setDirection(
    forward ? MotorDriver::Direction::EXTEND
            : MotorDriver::Direction::RETRACT
  );
}

void printStatus(const Estimator::Output& est) {
  Serial.print("mode=");
  Serial.print(mode == ControlMode::AUTO_PROFILE ? "AUTO" : "MANUAL");

  Serial.print("  pwm=");
  Serial.print(pwm);

  Serial.print("  dir=");
  Serial.print(forward ? "F" : "B");

  Serial.print("  phase=");
  Serial.print(
    phase == Phase::RAMP_UP ? "UP" :
    phase == Phase::HOLD    ? "HOLD" : "DOWN"
  );

  Serial.print("  counts=");
  Serial.print(enc.readCounts());

  Serial.print("  enc_mm=");
  Serial.print(enc.readPositionMm(), 4);

  Serial.print("  mm=");
  Serial.print(est.pos_est_mm, 4);

  Serial.print("  tof=");
  Serial.print(est.tof_mm);

  Serial.print("  valid=");
  Serial.print(est.tof_valid ? "Y" : "N");

  Serial.print("  slip=");
  Serial.print(est.slip_detected ? "Y" : "N");

  Serial.println();
}

void handleCommand(String cmd) {
  cmd.trim();
  cmd.toLowerCase();

  if (cmd.length() == 0) return;

  if (cmd == "h" || cmd == "help") {
    printHelp();
  }
  else if (cmd == "m") {
    mode = ControlMode::MANUAL;
    Serial.println("Switched to MANUAL mode");
  }
  else if (cmd == "a") {
    mode = ControlMode::AUTO_PROFILE;
    phase = Phase::RAMP_UP;
    phaseStart = millis();
    Serial.println("Switched to AUTO profile mode");
  }
  else if (cmd == "f") {
    forward = true;
    applyDirection();
    Serial.println("Direction = FORWARD / EXTEND");
  }
  else if (cmd == "b") {
    forward = false;
    applyDirection();
    Serial.println("Direction = BACKWARD / RETRACT");
  }
  else if (cmd.startsWith("p")) {
    int newPwm = cmd.substring(1).toInt();
    newPwm = constrain(newPwm, 0, 255);
    pwm = newPwm;
    motor.setPWM(pwm);

    Serial.print("PWM set to ");
    Serial.println(pwm);
  }
  else if (cmd == "s") {
    pwm = 0;
    motor.setPWM(0);
    Serial.println("Motor stopped");
  }
  else if (cmd == "z") {
    float home_mm = 10.0f;
    int32_t home_counts = (int32_t)roundf(home_mm / config::MM_PER_COUNT);
    enc.writeCounts(home_counts);
    estimator.reset();
    estimator.setPositionMm(home_mm);
    estimator.syncEncoder(enc.readCounts());
    lastEst = {};
    Serial.println("Position zeroed to 10 mm (encoder + estimator)");
  }
  else if (cmd == "status") {
    printStatus(lastEst);
  }
  else {
    Serial.print("Unknown command: ");
    Serial.println(cmd);
    printHelp();
  }
}

void readSerialCommands() {
  while (Serial.available()) {
    char c = Serial.read();

    if (c == '\n' || c == '\r') {
      if (cmdBuffer.length() > 0) {
        handleCommand(cmdBuffer);
        cmdBuffer = "";
      }
    } else {
      cmdBuffer += c;
    }
  }
}

// -----------------------------
// Setup
// -----------------------------
void setup() {
  logger::begin(115200);
  Serial.begin(115200);

  LOGI("Trapezoidal Motion Test");

  enc.begin();
  enc.writeCounts(0);

  estimator.reset();

  // --- ToF init ---
  if (!tof.begin(Wire1)) {
    Serial.println("ToF init FAILED");
  } else {
    Serial.println("ToF init OK");
  }

  motor.begin();
  motor.enable();

  applyDirection();

  phaseStart = millis();

  delay(500);
  printHelp();
  Estimator::Output dummy{};
  printStatus(dummy);
}

// -----------------------------
// Main loop
// -----------------------------
void loop() {
  uint32_t now = millis();

  float dt = (lastEstimatorUpdate == 0) ? 0.0f
                                        : (now - lastEstimatorUpdate) / 1000.0f;
  lastEstimatorUpdate = now;

  // --- ToF  ---
  auto tof_reading = tof.read();

  bool tof_valid = tof_reading.valid && tof_reading.fresh;
  uint16_t tof_mm = tof_reading.mm;

  // --- Estimator update ---
  lastEst = estimator.update(
    enc.readCounts(),
    false,     //enable = tof_valid
    tof_mm,    //enable = tof_mm
    dt
  );

  readSerialCommands();

  // Safety
  if (motor.faultActive()) {
    motor.stop();
    LOGE("MOTOR FAULT!");
    Serial.println("MOTOR FAULT!");
    while (1);
  }

  // --- AUTO MOTION PROFILE ---
  if (mode == ControlMode::AUTO_PROFILE && (now - lastUpdate >= 10)) {
    lastUpdate = now;

    switch (phase) {
      case Phase::RAMP_UP:
        pwm += PWM_STEP;
        if (pwm >= PWM_MAX) {
          pwm = PWM_MAX;
          phase = Phase::HOLD;
          phaseStart = now;
        }
        break;

      case Phase::HOLD:
        if (now - phaseStart > 1500) {
          phase = Phase::RAMP_DOWN;
        }
        break;

      case Phase::RAMP_DOWN:
        pwm -= PWM_STEP;
        if (pwm <= 0) {
          pwm = 0;

          forward = !forward;
          applyDirection();

          phase = Phase::RAMP_UP;
        }
        break;
    }

    motor.setPWM(pwm);
  }

  // --- PERIODIC STATUS PRINT ---
  bool moving = isMoving();
  uint32_t interval = moving ? PRINT_INTERVAL_MOVING
                             : PRINT_INTERVAL_IDLE;

  if (now - lastPrint >= interval) {
    lastPrint = now;

    if (moving) {
      Serial.print("[MOV] ");
    } else {
      Serial.print("[IDLE] ");
    }

    printStatus(lastEst);
  }
}

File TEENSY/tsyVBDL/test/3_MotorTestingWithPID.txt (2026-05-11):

#include <Arduino.h>
#include "config/pin_map.hpp"
#include "config/constants.hpp"
#include "utils/logger.hpp"
#include "drivers/enc_alt.hpp"
#include "drivers/motor_driver.hpp"
#include "controllers/estimator.hpp"
#include "controllers/pid_controller.hpp"
#include "drivers/tof_sensor.hpp"

// --- Encoder ---
static EncoderAlt enc({
  .channel = 2,

  .pin_a = PIN_ENC_A,
  .pin_b = PIN_ENC_B,

  .counts_per_rev = config::COUNTS_PER_SCREW_REV,
  .lead_screw_pitch_mm = config::LEAD_SCREW_MM_PER_REV
});

// --- Motor ---
static MotorDriver motor({
  .pin_pwm = PIN_MOTOR_PWM,
  .pin_dir = PIN_MOTOR_DIR,
  .pin_slp = PIN_MOTOR_SLP,
  .pin_flt = PIN_MOTOR_FLT,
  .pin_cs  = PIN_MOTOR_CS,
  .pwm_freq_hz = 25000.0f,
  .pwm_max = 255,
  .flt_active_low = true,
  .cs_volts_per_amp = 0.04f,
  .adc_ref_volts = 3.3f,
  .adc_bits = 12
});

// --- Estimator ---
static Estimator estimator({
  .mm_per_count      = config::MM_PER_COUNT,
  .tof_gain          = config::TOF_FUSION_GAIN,
  .recovery_gain     = config::SLIP_RECOVERY_GAIN,
  .slip_detect_mm    = config::SLIP_DETECT_MM,
  .tof_min_valid_mm  = config::TOF_MIN_VALID_MM
});

// --- PID ---
static PIDController pid;

// --- ToF ---
static ToFSensor tof(PIN_TOF_SDA, PIN_TOF_SCL);

enum class ControlMode {
  AUTO,
  MANUAL
};

ControlMode mode = ControlMode::MANUAL;

int pwm = 0;               // applied PWM after safety shaping
int manual_pwm_cmd = 0;    // raw manual command from serial
const int PWM_MAX = 255;

bool forward = true;

uint32_t lastEstimatorUpdate = 0;
uint32_t lastControlUpdate = 0;
uint32_t lastPrint = 0;

const uint32_t CONTROL_INTERVAL_MS = 2; // 500Hz

Estimator::Output lastEst{};
ToFSensor::Reading lastToF{};

// --- Control state ---
float target_mm_cmd = config::STROKE_HARD_MIN_MM;
float target_mm = target_mm_cmd;       // filtered target
float target_percent = 0.0f;

bool homed = false;
bool holding = false;
bool posHardFaultLatched = false;

// Serial buffer
String cmdBuffer;
const uint16_t CMD_BUFFER_MAX_LEN = 64;

// -----------------------------
// Helpers
// -----------------------------
float percentToMm(float percent)
{
  percent = constrain(percent, 0.0f, 100.0f);

  return config::STROKE_HARD_MIN_MM +
         (percent / 100.0f) * config::STROKE_SPAN_MM;
}

float computeSoftZoneScale(float pos_mm)
{
  if (pos_mm <= config::STROKE_SOFT_START_MM) {
    float t = (pos_mm - config::STROKE_HARD_MIN_MM) /
              (config::STROKE_SOFT_START_MM - config::STROKE_HARD_MIN_MM);
    t = constrain(t, 0.0f, 1.0f);

    return config::SOFT_ZONE_MAX_DUTY +
           t * (1.0f - config::SOFT_ZONE_MAX_DUTY);
  }

  if (pos_mm >= config::STROKE_SOFT_END_MM) {
    float t = (config::STROKE_HARD_MAX_MM - pos_mm) /
              (config::STROKE_HARD_MAX_MM - config::STROKE_SOFT_END_MM);
    t = constrain(t, 0.0f, 1.0f);

    return config::SOFT_ZONE_MAX_DUTY +
           t * (1.0f - config::SOFT_ZONE_MAX_DUTY);
  }

  return 1.0f;
}

bool isHardLimitHit(float pos_mm, bool extending)
{
  if (extending) {
    return pos_mm >= config::STROKE_HARD_MAX_MM;
  }

  return pos_mm <= config::STROKE_HARD_MIN_MM;
}

void printHelp() {
  Serial.println("\n=== Commands ===");
  Serial.println("m          -> manual mode");
  Serial.println("a          -> auto mode");
  Serial.println("%<num>     -> set target (AUTO only)");
  Serial.println("p<num>     -> set PWM (manual)");
  Serial.println("f / b      -> direction (manual)");
  Serial.println("s          -> stop");
  Serial.println("x          -> clear latched position hard fault");
  Serial.println("z          -> home (must be near 10mm)");
  Serial.println("status     -> print status\n");
}

void printStatus(const Estimator::Output& est) {
  float error = target_mm - est.pos_est_mm;
  float motor_current_a = motor.readCurrentA();
  bool flt_active = motor.faultActive();

  Serial.print("mode=");
  Serial.print(mode == ControlMode::AUTO ? "AUTO" : "MANUAL");

  Serial.print("  mm=");
  Serial.print(est.pos_est_mm, 3);

  Serial.print("  target=");
  Serial.print(target_mm, 2);

  Serial.print("  target%=");
  Serial.print(target_percent, 1);

  Serial.print("  err=");
  Serial.print(error, 3);

  Serial.print("  vel=");
  Serial.print(est.vel_est_mm_s, 2);

  Serial.print("  pwm=");
  Serial.print(pwm);

  Serial.print("  flt=");
  Serial.print(flt_active ? "Y" : "N");

  Serial.print("  iA=");
  Serial.print(motor_current_a, 2);

  Serial.print("  tof=");
  Serial.print(lastToF.mm);

  Serial.print("  tofSt=");
  Serial.print(lastToF.status);

  Serial.print("  tofV=");
  Serial.print(lastToF.valid ? "Y" : "N");

  Serial.print("  tofF=");
  Serial.print(lastToF.fresh ? "Y" : "N");

  Serial.print("  hardLatch=");
  Serial.print(posHardFaultLatched ? "Y" : "N");

  Serial.print("  homed=");
  Serial.print(homed ? "Y" : "N");

  Serial.println();
}

// -----------------------------
// Command handling
// -----------------------------
void handleCommand(String cmd) {
  cmd.trim();
  cmd.toLowerCase();

  if (cmd == "m") {
    mode = ControlMode::MANUAL;
    manual_pwm_cmd = 0;
    pwm = 0;
    motor.setPWM(0);
    Serial.println("MANUAL mode");
  }
  else if (cmd == "a") {
    if (!homed) {
      Serial.println("ERROR: Not homed");
      return;
    }

    mode = ControlMode::AUTO;
    target_mm = lastEst.pos_est_mm;
    target_mm_cmd = target_mm;
    pid.reset();
    holding = false;

    Serial.println("AUTO mode");
  }
  else if (cmd.startsWith("%")) {
    if (mode != ControlMode::AUTO) {
      Serial.println("ERROR: AUTO mode only");
      return;
    }

    float pct = cmd.substring(1).toFloat();
    target_percent = constrain(pct, 0.0f, 100.0f);
    target_mm_cmd = percentToMm(target_percent);

    Serial.print("Target: ");
    Serial.print(target_percent);
    Serial.print("% -> ");
    Serial.println(target_mm_cmd);
  }
  else if (cmd.startsWith("p")) {
    if (mode == ControlMode::AUTO) return;

    manual_pwm_cmd = constrain(cmd.substring(1).toInt(), 0, 255);
  }
  else if (cmd == "f") {
    if (mode == ControlMode::AUTO) return;
    forward = true;
    motor.setDirection(MotorDriver::Direction::EXTEND);
  }
  else if (cmd == "b") {
    if (mode == ControlMode::AUTO) return;
    forward = false;
    motor.setDirection(MotorDriver::Direction::RETRACT);
  }
  else if (cmd == "s") {
    manual_pwm_cmd = 0;
    pwm = 0;
    motor.setPWM(0);
  }
  else if (cmd == "x") {
    if (motor.faultActive()) {
      Serial.println("ERROR: Driver fault still active");
      return;
    }

    if (lastEst.pos_est_mm < config::STROKE_REAL_MIN_MM ||
        lastEst.pos_est_mm > config::STROKE_REAL_MAX_MM) {
      Serial.println("ERROR: Position still outside 0..150mm");
      return;
    }

    posHardFaultLatched = false;
    motor.enable();
    Serial.println("Position hard fault latch cleared");
  }
  else if (cmd == "z") {
    float pos = lastEst.pos_est_mm;

    // if (fabs(pos - 10.0f) > 2.0f) {
    //   Serial.println("ERROR: Not near 10mm");
    //   return;
    // }

    float home_mm = 10.0f;
    int32_t home_counts = roundf(home_mm / config::MM_PER_COUNT);

    enc.writeCounts(home_counts);
    estimator.reset();
    estimator.setPositionMm(home_mm);
    estimator.syncEncoder(enc.readCounts());

    pid.reset();
    homed = true;

    Serial.println("HOMED at 10mm");
  }
}

void readSerialCommands() {
  while (Serial.available()) {
    char c = Serial.read();

    if (c == '\n' || c == '\r') {
      handleCommand(cmdBuffer);
      cmdBuffer = "";
    } else {
      if (cmdBuffer.length() < CMD_BUFFER_MAX_LEN) {
        cmdBuffer += c;
      } else {
        cmdBuffer = "";
        Serial.println("ERROR: Command too long");
      }
    }
  }
}

// -----------------------------
// Setup
// -----------------------------
void setup() {
  Serial.begin(115200);
  logger::begin(115200);
  cmdBuffer.reserve(CMD_BUFFER_MAX_LEN);

  enc.begin();

  estimator.reset();
  estimator.syncEncoder(enc.readCounts());  // IMPORTANT

  if (!tof.begin(Wire1)) {
    Serial.println("WARN: ToF init failed");
  } else {
    Serial.println("ToF init OK");
  }

  motor.begin();
  motor.enable();

  pid.configure({
    config::PID_KP,
    config::PID_KI,
    config::PID_KD,
    config::PID_I_LIMIT,
    config::PID_OUT_LIMIT
  });

  printHelp();
}

// -----------------------------
// Loop
// -----------------------------
void loop() {
  uint32_t now = millis();

  // -----------------------------
  // Time delta (shared)
  // -----------------------------
  static uint32_t lastTime = 0;
  float dt = (lastTime == 0) ? 0.0f :
             (now - lastTime) / 1000.0f;
  lastTime = now;

  // If the control loop hiccups badly, drop motor output immediately.
  if (dt > 0.2f) {
    manual_pwm_cmd = 0;
    pwm = 0;
    holding = false;
    pid.reset();
    motor.setPWM(0);
  }

  // -----------------------------
  // Read encoder (fast path)
  // -----------------------------
  int32_t counts = enc.readCounts();

  // -----------------------------
  // Read ToF (slow / optional)
  // -----------------------------
  lastToF = tof.read();

  bool tof_valid = lastToF.valid && lastToF.fresh;

  // -----------------------------
  // Estimator (runs EVERY loop)
  // -----------------------------
  lastEst = estimator.update(
    counts,
    tof_valid,          // fuse only if valid (tof_valid) or false
    lastToF.mm,
    dt
  );

  // -----------------------------
  // Serial
  // -----------------------------
  readSerialCommands();

  // -----------------------------
  // Safety
  // -----------------------------
  bool driverFaultActive = motor.faultActive();
  bool posBeyondRealLimit =
    (lastEst.pos_est_mm < config::STROKE_REAL_MIN_MM) ||
    (lastEst.pos_est_mm > config::STROKE_REAL_MAX_MM);

  if (posBeyondRealLimit) {
    posHardFaultLatched = true;
  }

  bool inhibitMotion = false;
  if (posHardFaultLatched) {
    manual_pwm_cmd = 0;
    pwm = 0;
    motor.disable();
    inhibitMotion = true;

    static uint32_t lastFaultPrint = 0;
    if (now - lastFaultPrint >= 1000) {
      lastFaultPrint = now;
      Serial.println("FAULT: Position exceeded 0..150mm, output disabled");
    }
  } else if (driverFaultActive) {
    manual_pwm_cmd = 0;
    pwm = 0;
    motor.setPWM(0);
    inhibitMotion = true;

    static uint32_t lastDriverWarnPrint = 0;
    if (now - lastDriverWarnPrint >= 1000) {
      lastDriverWarnPrint = now;
      Serial.println("WARN: Driver fault active, output inhibited");
    }
  }

  // -----------------------------
  // MANUAL CONTROL WITH SAFETY (runs EVERY loop)
  // -----------------------------
  if (!inhibitMotion && mode == ControlMode::MANUAL) {
    float pos = lastEst.pos_est_mm;
    bool extending = forward;

    float duty = static_cast<float>(manual_pwm_cmd) / static_cast<float>(PWM_MAX);
    duty *= computeSoftZoneScale(pos);

    if (isHardLimitHit(pos, extending)) {
      duty = 0.0f;
    }

    duty = constrain(duty, 0.0f, 1.0f);

    pwm = static_cast<int>(roundf(duty * static_cast<float>(PWM_MAX)));

    motor.setDirection(extending ?
      MotorDriver::Direction::EXTEND :
      MotorDriver::Direction::RETRACT);
    motor.setPWM(pwm);
  }

  // -----------------------------
  // AUTO CONTROL (runs EVERY loop)
  // -----------------------------
  else if (!inhibitMotion) {

    float pos = lastEst.pos_est_mm;
    float vel = lastEst.vel_est_mm_s;

    // --- target smoothing ---
    float max_step = 40.0f * dt;  // mm/s limit (tune this)

    float delta = target_mm_cmd - target_mm;

    if (fabs(delta) > max_step) {
      target_mm += (delta > 0 ? max_step : -max_step);
    } else {
      target_mm = target_mm_cmd;
    }

    target_mm = constrain(target_mm,
                          config::STROKE_HARD_MIN_MM,
                          config::STROKE_HARD_MAX_MM);

    float error = target_mm - pos;

    bool skipPid = false;

    // --- Holding logic ---
    if (holding) {
      if (fabs(error) > config::DRIFT_RESTART_MM) {
        holding = false;
      } else {
        pwm = 0;
        motor.setPWM(0);
        skipPid = true;
      }
    }

    // --- improved stop condition ---
    if (!skipPid) {
      bool near_target = fabs(error) <= config::POS_TOL_MM;
      bool slow = fabs(vel) < 0.5f;  // tighter threshold

      // check if we are NOT still moving toward the target
      bool not_pushing_toward_target =
        (error > 0 && vel <= 0) ||   // target ahead, but not moving toward it
        (error < 0 && vel >= 0);     // target behind, but not moving toward it

      if (near_target && slow && not_pushing_toward_target) {
        pwm = 0;
        motor.setPWM(0);
        holding = true;
        skipPid = true;
      }
    }

    if (!skipPid) {
      // --- PID ---
      float effort = pid.update(target_mm, pos, vel, dt);

      bool dir = (effort > 0);
      motor.setDirection(dir ?
        MotorDriver::Direction::EXTEND :
        MotorDriver::Direction::RETRACT);

      float duty = fabs(effort);

      if (duty > 0.0f) {
        duty = config::MIN_DUTY +
               (1.0f - config::MIN_DUTY) * duty;
      }

      duty *= computeSoftZoneScale(pos);

      if (isHardLimitHit(pos, dir)) {
        duty = 0.0f;
      }

      duty = constrain(duty, 0.0f, 1.0f);

      pwm = duty * PWM_MAX;
      motor.setPWM(pwm);
    }
  }

  // -----------------------------
  // STATUS (slow)
  // -----------------------------
  if (now - lastPrint >= 1000) {
    lastPrint = now;
    printStatus(lastEst);
  }
}

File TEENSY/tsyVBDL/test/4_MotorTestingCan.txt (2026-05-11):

#include <Arduino.h>
#include <stdint.h>
#include "config/pin_map.hpp"
#include "config/constants.hpp"
#include "utils/logger.hpp"
#include "drivers/enc_alt.hpp"
#include "drivers/motor_driver.hpp"
#include "controllers/estimator.hpp"
#include "controllers/pid_controller.hpp"
#include "drivers/tof_sensor.hpp"
#include "drivers/can_bus.hpp"
#include "protocols/can_messages.hpp"

// --- CAN ---
CanFrame lastFrame{};
bool hasLastFrame = false;
constexpr uint8_t CAN_NODE_ID = config::NODE_ID_LEFT;
static CanBus canBus;
uint8_t canSequence = 0;
uint32_t lastCanTx = 0;
const uint32_t CAN_TX_INTERVAL_MS = 20; // 50Hz
float lastTofMm = 0.0f;
bool lastDirectionExtend = true;

struct FrameCache {
  bool valid;
  CanFrame frame;
};

FrameCache lastFrames[2048]; // enough for 11-bit IDs

// --- Encoder ---
static EncoderAlt enc({
  .channel = 2,

  .pin_a = PIN_ENC_A,
  .pin_b = PIN_ENC_B,

  .counts_per_rev = config::COUNTS_PER_SCREW_REV,
  .lead_screw_pitch_mm = config::LEAD_SCREW_MM_PER_REV
});

// --- Motor ---
static MotorDriver motor({
  .pin_pwm = PIN_MOTOR_PWM,
  .pin_dir = PIN_MOTOR_DIR,
  .pin_slp = PIN_MOTOR_SLP,
  .pin_flt = PIN_MOTOR_FLT,
  .pin_cs  = PIN_MOTOR_CS,
  .pwm_freq_hz = 25000.0f,
  .pwm_max = 255,
  .flt_active_low = true,
  .cs_volts_per_amp = 0.04f,
  .adc_ref_volts = 3.3f,
  .adc_bits = 12
});

// --- Estimator ---
static Estimator estimator({
  .mm_per_count      = config::MM_PER_COUNT,
  .tof_gain          = config::TOF_FUSION_GAIN,
  .recovery_gain     = config::SLIP_RECOVERY_GAIN,
  .slip_detect_mm    = config::SLIP_DETECT_MM,
  .tof_min_valid_mm  = config::TOF_MIN_VALID_MM
});

// --- PID ---
static PIDController pid;

// --- ToF ---
static ToFSensor tof(PIN_TOF_SDA, PIN_TOF_SCL);

enum class ControlMode {
  AUTO,
  MANUAL,
  CAN
};

ControlMode mode = ControlMode::MANUAL;

int pwm = 0;
const int PWM_MAX = 255;

uint32_t lastEstimatorUpdate = 0;
uint32_t lastControlUpdate = 0;
uint32_t lastPrint = 0;

const uint32_t CONTROL_INTERVAL_MS = 2; // 500Hz

Estimator::Output lastEst{};

float lastTofRawMm = 0.0f;

// --- Control state ---
float target_mm_cmd = config::STROKE_HARD_MIN_MM;
float target_mm = target_mm_cmd;       // filtered target
float target_percent = 0.0f;

bool homed = false;
bool holding = false;

// Serial buffer
String cmdBuffer;

// CAN timeout
uint32_t lastCanRx = 0;
const uint32_t CAN_TIMEOUT_MS = 5000;

// LED
uint32_t lastLedToggle = 0;
bool ledOn = false;

// -----------------------------
// Helpers
// -----------------------------
bool isFrameDifferentIgnoreSeq(const CanFrame& a, const CanFrame& b, int seqIndex)
{
  if (a.id != b.id) return true;
  if (a.len != b.len) return true;

  for (uint8_t i = 0; i < a.len; i++) {
    if (i == seqIndex) continue; // 👈 ignore sequence byte

    if (a.data[i] != b.data[i]) return true;
  }

  return false;
}

float percentToMm(float percent)
{
  percent = constrain(percent, 0.0f, 100.0f);

  return config::STROKE_HARD_MIN_MM +
         (percent / 100.0f) * config::STROKE_SPAN_MM;
}

float computeSoftZoneScale(float pos_mm)
{
  if (pos_mm <= config::STROKE_SOFT_START_MM) {
    float t = (pos_mm - config::STROKE_HARD_MIN_MM) /
              (config::STROKE_SOFT_START_MM - config::STROKE_HARD_MIN_MM);
    t = constrain(t, 0.0f, 1.0f);

    return config::SOFT_ZONE_MAX_DUTY +
           t * (1.0f - config::SOFT_ZONE_MAX_DUTY);
  }

  if (pos_mm >= config::STROKE_SOFT_END_MM) {
    float t = (config::STROKE_HARD_MAX_MM - pos_mm) /
              (config::STROKE_HARD_MAX_MM - config::STROKE_SOFT_END_MM);
    t = constrain(t, 0.0f, 1.0f);

    return config::SOFT_ZONE_MAX_DUTY +
           t * (1.0f - config::SOFT_ZONE_MAX_DUTY);
  }

  return 1.0f;
}

void printHelp() {
  Serial.println("\n=== Commands ===");
  Serial.println("m          -> manual mode");
  Serial.println("a          -> auto mode");
  Serial.println("%<num>     -> set target (AUTO only)");
  Serial.println("p<num>     -> set PWM (manual)");
  Serial.println("f / b      -> direction (manual)");
  Serial.println("s          -> stop");
  Serial.println("z          -> home (must be near 10mm)");
  Serial.println("status     -> print status\n");
}

void printStatus(const Estimator::Output& est) {
  float error = target_mm - est.pos_est_mm;

  Serial.print("mode=");
  switch (mode) {
    case ControlMode::AUTO:
      Serial.print("AUTO");
      break;

    case ControlMode::MANUAL:
      Serial.print("MANUAL");
      break;

    case ControlMode::CAN:
      Serial.print("CAN");
      break;
  }
  
  Serial.print("  mm=");
  Serial.print(est.pos_est_mm, 3);

  Serial.print("  tof=");
  Serial.print(lastTofMm, 1);

  Serial.print("  target=");
  Serial.print(target_mm, 2);

  Serial.print("  target%=");
  Serial.print(target_percent, 1);

  Serial.print("  err=");
  Serial.print(error, 3);

  Serial.print("  vel=");
  Serial.print(est.vel_est_mm_s, 2);

  Serial.print("  pwm=");
  Serial.print(pwm);

  Serial.print("  homed=");
  Serial.print(homed ? "Y" : "N");

  Serial.println();
}

// -----------------------------
// Command handling
// -----------------------------
void handleCommand(String cmd) {
  cmd.trim();
  cmd.toLowerCase();

  if (cmd == "m") {
    mode = ControlMode::MANUAL;
    motor.setPWM(0);
    Serial.println("MANUAL mode");
  }
  else if (cmd == "a") {
    if (!homed) {
      Serial.println("ERROR: Not homed");
      return;
    }

    mode = ControlMode::AUTO;
    target_mm = lastEst.pos_est_mm;
    target_mm_cmd = target_mm;
    pid.reset();
    holding = false;

    Serial.println("AUTO mode");
  }
  else if (cmd.startsWith("%")) {
    if (mode != ControlMode::AUTO) {
      Serial.println("ERROR: AUTO mode only");
      return;
    }

    float pct = cmd.substring(1).toFloat();
    target_percent = constrain(pct, 0.0f, 100.0f);
    target_mm_cmd = percentToMm(target_percent);

    Serial.print("Target: ");
    Serial.print(target_percent);
    Serial.print("% -> ");
    Serial.println(target_mm_cmd);
  }
  else if (cmd.startsWith("p")) {
    if (mode == ControlMode::AUTO) return;

    pwm = constrain(cmd.substring(1).toInt(), 0, 255);
    motor.setPWM(pwm);
  }
  else if (cmd == "f") {
    if (mode == ControlMode::AUTO) return;
    motor.setDirection(MotorDriver::Direction::EXTEND);
    lastDirectionExtend = true;  
  }
  else if (cmd == "b") {
    if (mode == ControlMode::AUTO) return;
    motor.setDirection(MotorDriver::Direction::RETRACT);
    lastDirectionExtend = false; 
  }
  else if (cmd == "s") {
    pwm = 0;
    motor.setPWM(0);
  }
  else if (cmd == "z") {
    //float pos = lastEst.pos_est_mm;

    // if (fabs(pos - 10.0f) > 2.0f) {
    //   Serial.println("ERROR: Not near 10mm");
    //   return;
    // }

    float home_mm = 10.0f;
    int32_t home_counts = roundf(home_mm / config::MM_PER_COUNT);

    enc.writeCounts(home_counts);
    estimator.reset();
    estimator.setPositionMm(home_mm);
    estimator.syncEncoder(enc.readCounts());

    pid.reset();
    homed = true;

    Serial.println("HOMED at 10mm");
  }
  else if (cmd == "c") {
    if (!homed) {
      Serial.println("ERROR: Not homed");
      return;
    }

    mode = ControlMode::CAN;

    lastCanRx = millis();

    target_mm = lastEst.pos_est_mm;
    target_mm_cmd = target_mm;

    pid.reset();
    holding = false;

    Serial.println("CAN mode");
  }
}

void readSerialCommands() {
  while (Serial.available()) {
    char c = Serial.read();

    if (c == '\n' || c == '\r') {
      handleCommand(cmdBuffer);
      cmdBuffer = "";
    } else {
      cmdBuffer += c;
    }
  }
}

void handleCan()
{
  CanFrame frame;

  while (canBus.read(frame)) {

    //🔍 DEBUG PRINT (add this)
    constexpr int SEQ_INDEX = 6;
    uint16_t id = frame.id & 0x7FF; // standard ID
    if (!lastFrames[id].valid ||
        isFrameDifferentIgnoreSeq(frame, lastFrames[id].frame, SEQ_INDEX)) {

      Serial.print("RX id=0x");
      Serial.print(frame.id, HEX);
      Serial.print(" len=");
      Serial.print(frame.len);
      Serial.print(" data=");

      for (uint8_t i = 0; i < frame.len; i++) {
        Serial.print(frame.data[i]);
        Serial.print(" ");
      }
      Serial.println();

      lastFrames[id].frame = frame;
      lastFrames[id].valid = true;
    }
    
    if (frame.id == can::CMD_SETPOINT_BASE + CAN_NODE_ID) {

      lastCanRx = millis();

      can::CmdSetpoint msg;
      can::unpackCmdSetpoint(frame.data, msg);

      // Only apply CAN commands if we are in CAN mode
      if (mode != ControlMode::CAN) {
        continue;
      }

      if (!homed) {
        continue;
      }

      // --- Apply setpoint ---
      float pct = constrain(msg.stroke_percent, 0, 100);

      static uint8_t last_pct = 255;

      if (msg.stroke_percent != last_pct) {
        pid.reset();
        holding = false;
        last_pct = msg.stroke_percent;
      }

      target_percent = pct;
      target_mm_cmd = percentToMm(pct);
    }
  }
}

uint8_t buildControlFlags()
{
  uint8_t flags = 0;

  if (homed) flags |= can::FLAG_HOMED;

  if (fabs(lastEst.vel_est_mm_s) > 0.5f)
    flags |= can::FLAG_MOVING;

  flags |= can::FLAG_MOTOR_EN;

  if (lastDirectionExtend)
    flags |= can::FLAG_DIR;

  if (motor.faultActive())
    flags |= can::FLAG_DRIVER_FLT;

  return flags;
}

void sendStatusControl()
{
  can::StatusControl msg{};

  msg.est_position_01mm =
    (uint16_t)constrain(lastEst.pos_est_mm * 100.0f, 0, 65535);

  msg.tof_position_mm =
    (uint16_t)constrain(lastTofMm, 0, 65535);

  msg.flags = buildControlFlags();

  msg.pwm = (uint8_t)pwm;

  msg.sequence = canSequence++;

  float currentA = motor.readCurrentA();
  msg.motor_current =
    (int8_t)constrain(currentA * 10.0f, -127, 127); // 0.1A/LSB

  uint8_t buf[8];
  can::packStatusControl(buf, msg);

  CanFrame frame;
  frame.id = can::STATUS_CONTROL_BASE + CAN_NODE_ID;
  frame.len = 8;

  for (int i = 0; i < 8; i++) frame.data[i] = buf[i];

  canBus.write(frame);
}

// -----------------------------
// Setup
// -----------------------------
void setup() {
  Serial.begin(115200);
  logger::begin(115200);

  pinMode(LED_BUILTIN, OUTPUT);
  digitalWrite(LED_BUILTIN, LOW);

  enc.begin();

  estimator.reset();
  estimator.syncEncoder(enc.readCounts());  // IMPORTANT

  tof.begin(Wire1);

  motor.begin();
  motor.enable();

  pid.configure({
    config::PID_KP,
    config::PID_KI,
    config::PID_KD,
    config::PID_I_LIMIT,
    config::PID_OUT_LIMIT
  });

  canBus.begin(500000, PIN_CAN_R, PIN_CAN_D); // or whatever your bus speed is

  printHelp();
}

// -----------------------------
// Loop
// -----------------------------
void loop() {
  uint32_t now = millis();

  // -----------------------------
  // LED toggle
  // -----------------------------
  if (!ledOn && (now - lastLedToggle >= 5000)) {
    digitalWrite(LED_BUILTIN, HIGH);
    ledOn = true;
    lastLedToggle = now;
  }
  if (ledOn && (now - lastLedToggle >= 100)) {
    digitalWrite(LED_BUILTIN, LOW);
    ledOn = false;
  }

  // -----------------------------
  // Time delta (shared)
  // -----------------------------
  static uint32_t lastTime = 0;
  float dt = (lastTime == 0) ? 0.0f :
             (now - lastTime) / 1000.0f;
  lastTime = now;

  // -----------------------------
  // Read encoder (fast path)
  // -----------------------------
  int32_t counts = enc.readCounts();

  // -----------------------------
  // Read ToF (slow / optional)
  // -----------------------------
  auto tof_reading = tof.read();

  lastTofRawMm = tof_reading.mm;

  bool tof_valid = tof_reading.valid && tof_reading.fresh;

  if (tof_valid) {
    lastTofMm = tof_reading.mm;
  }
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

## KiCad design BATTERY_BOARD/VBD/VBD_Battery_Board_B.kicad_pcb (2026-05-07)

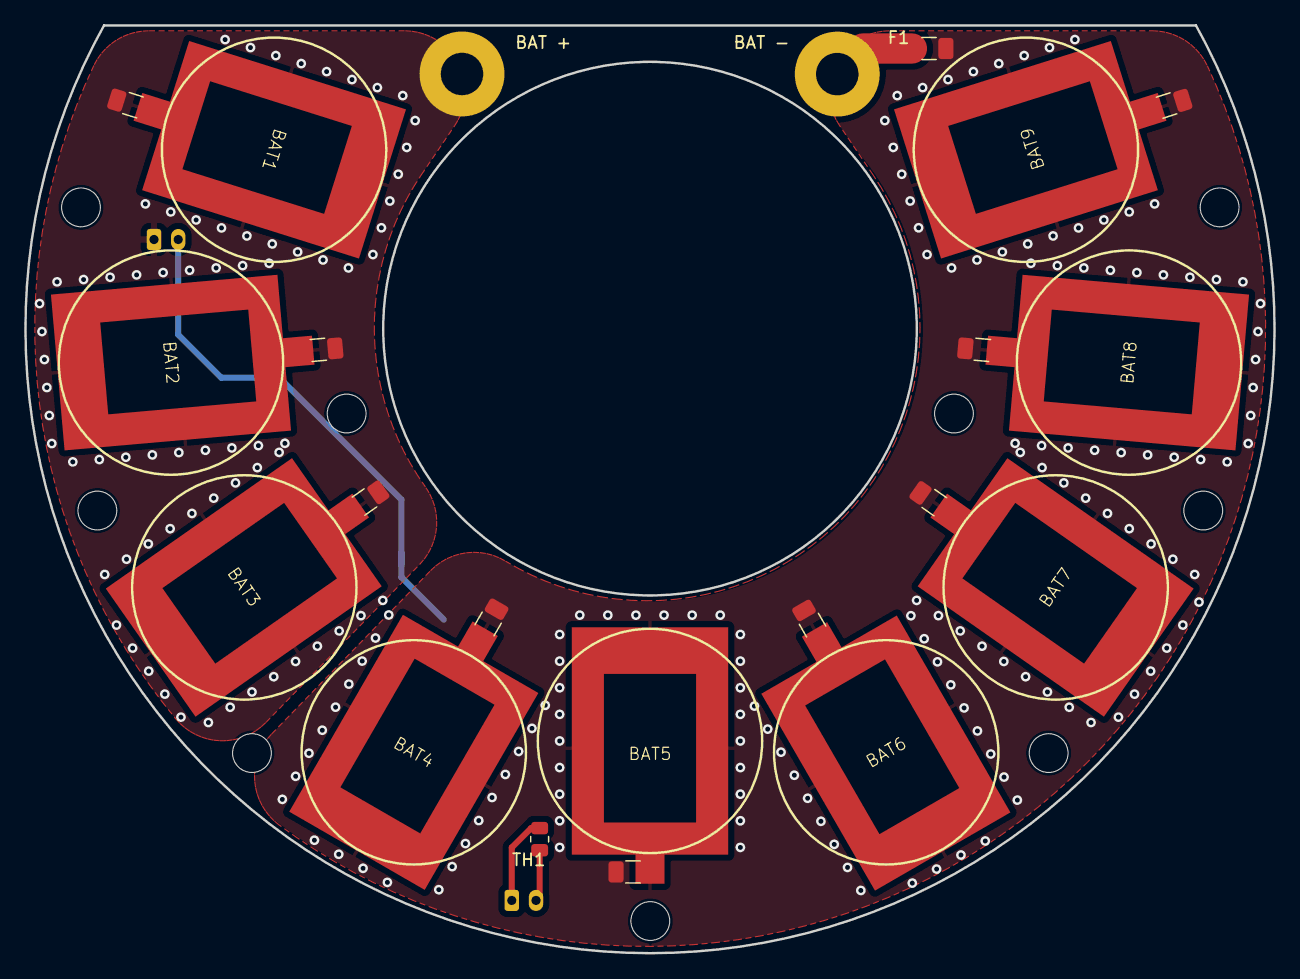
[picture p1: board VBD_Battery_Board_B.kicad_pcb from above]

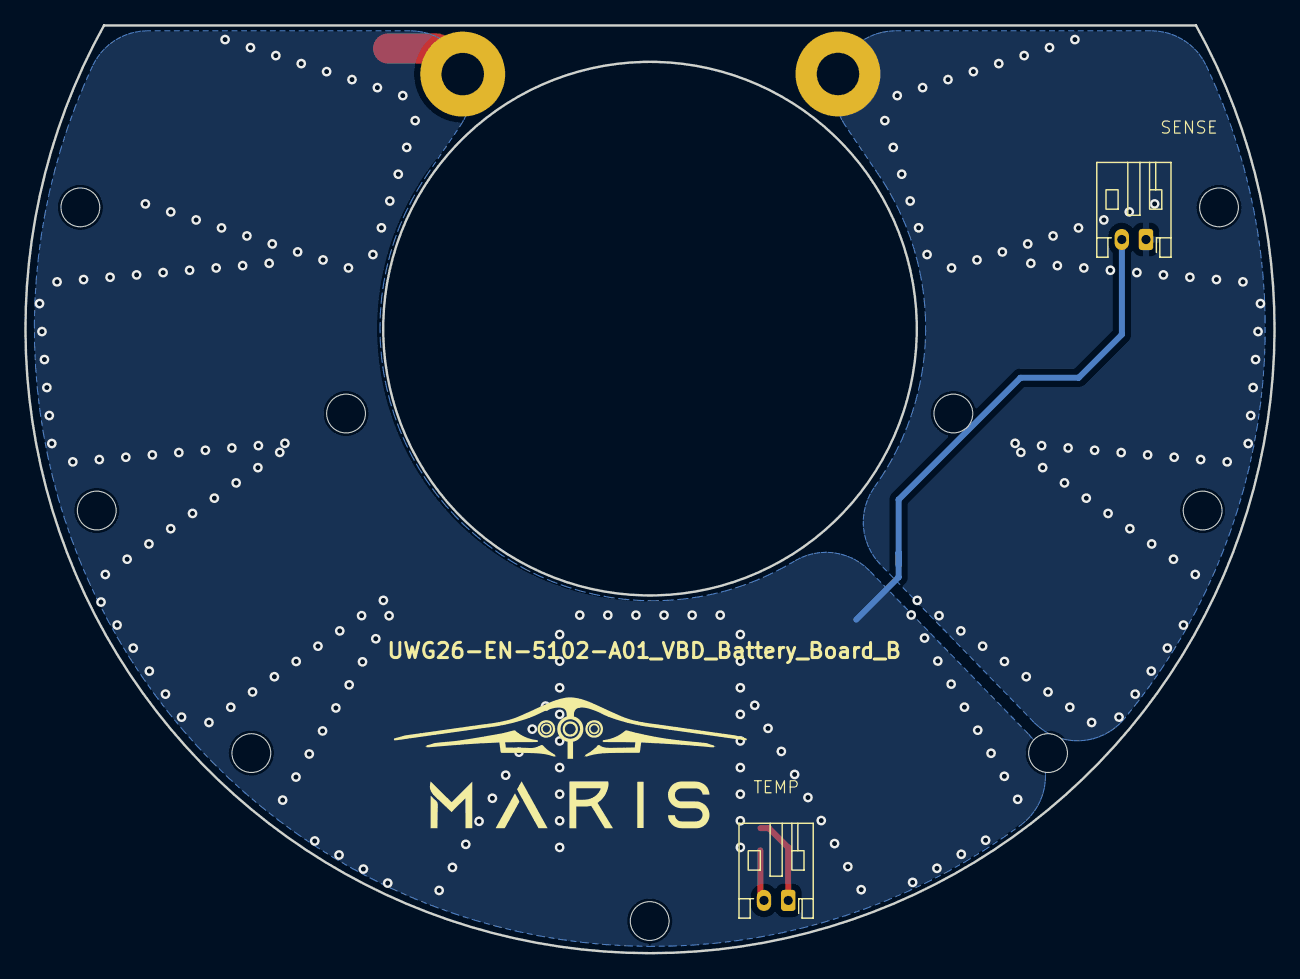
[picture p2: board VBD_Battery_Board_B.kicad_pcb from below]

Board: 2 copper layers, 103.0 x 76.5 mm, 15 parts (2 on the bottom side), 5 nets.

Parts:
BAT1, BAT2, BAT3, BAT4, BAT5, BAT6, BAT7, BAT8, BAT9: Keystone_109-2
BAT +: Conn_01x01_Pin; MountingHole_3.5mm_Pad
BAT -: Conn_01x01_Pin; MountingHole_3.5mm_Pad
F1: Fuse; Fuse_1206_3216Metric
J1, J4: Conn_01x02_Pin; JST_PH_S2B-PH-K_1x02_P2.00mm_Horizontal
TH1: Thermistor_NTC; R_0805_2012Metric

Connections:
/S1_POS: BAT1.1, BAT2.1, BAT3.1, BAT +.1, J1.1
/S3_POS: BAT4.1, BAT5.1, BAT6.1, BAT7.1, BAT8.1, BAT9.1, F1.2, J1.2
/TEMP: J4.1, TH1.1
/TEMP_GND: J4.2, TH1.2
unnamed: BAT -.1, F1.1

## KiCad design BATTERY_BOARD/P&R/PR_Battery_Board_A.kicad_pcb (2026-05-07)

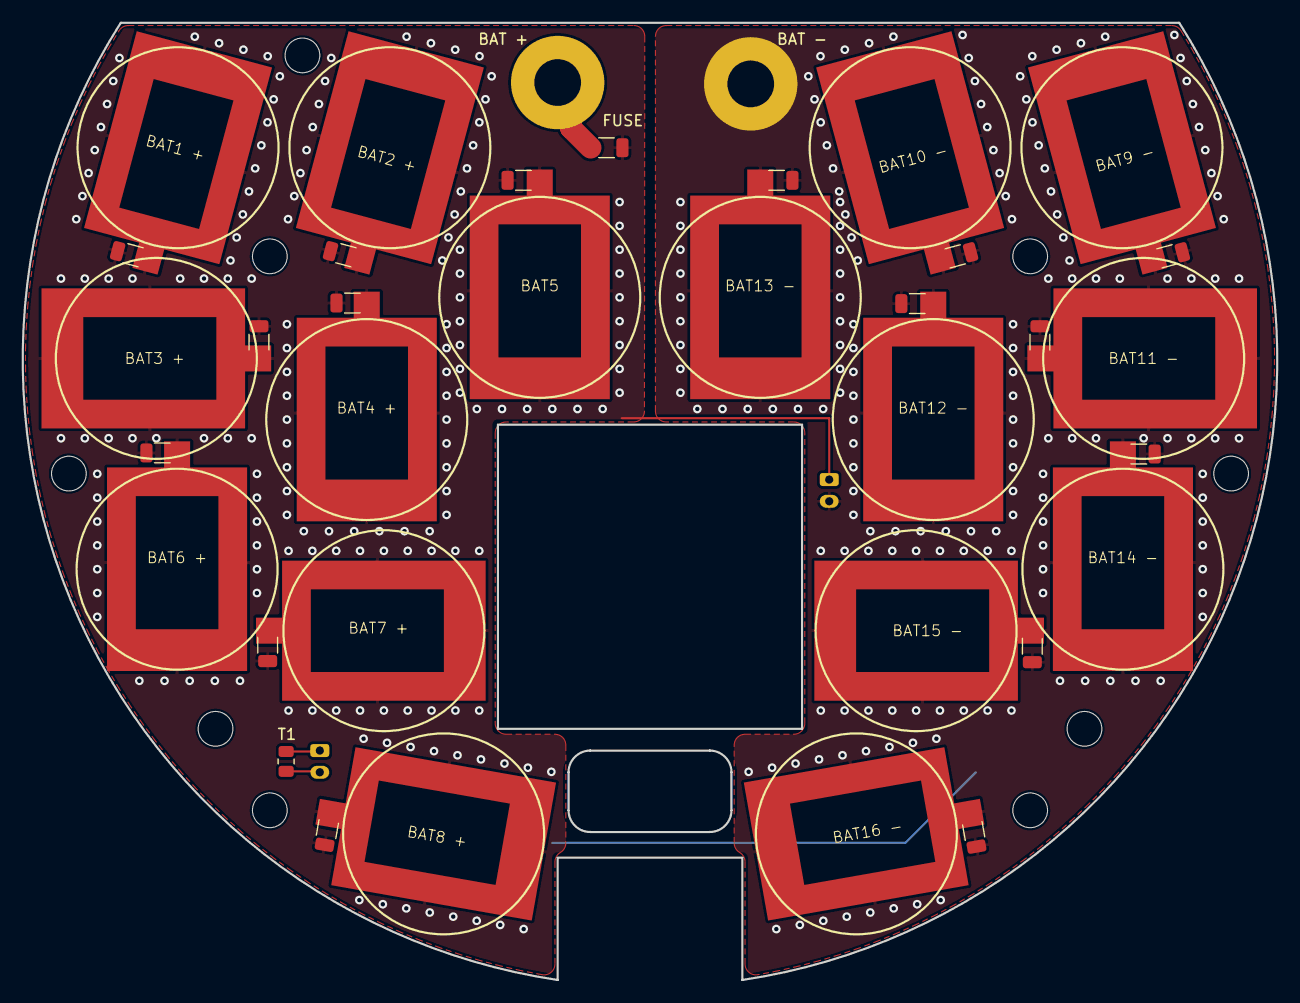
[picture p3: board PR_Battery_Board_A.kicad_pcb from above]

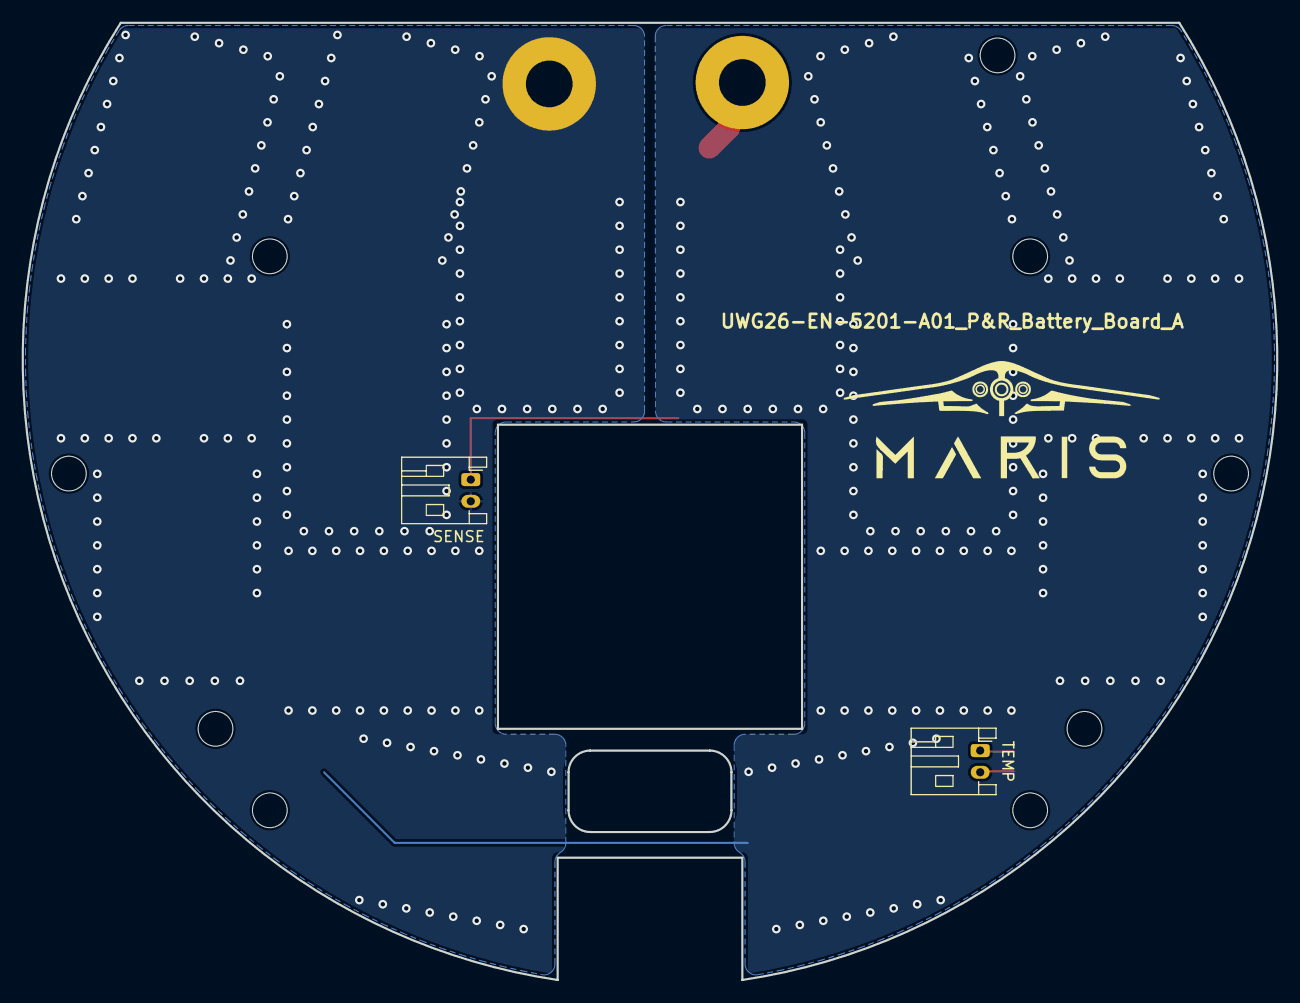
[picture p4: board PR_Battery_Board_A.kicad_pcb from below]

Board: 2 copper layers, 115.5 x 88.1 mm, 38 parts (2 on the bottom side), 5 nets.

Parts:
BAT1 +, BAT2 +, BAT3 +, BAT4 +, BAT5, BAT6 +, BAT7 +, BAT8 +, BAT9 -, BAT10 -, BAT11 -, BAT12 -, BAT13 -, BAT14 -, BAT15 -, BAT16 -: Keystone_109-2
BAT +: MountingHole_Pad; MountingHole_4.3mm_M4_Pad
BAT -: MountingHole_Pad; MountingHole_4.3mm_M4_Pad
F1, F2, F3, F4, F5, F6, F7, F8, F9, F10, F11, F12, F13, F14, F15, F16: DNP; R_1206_3216Metric
FUSE: F10; R_1206_3216Metric
SENSE: Conn_01x02_Pin; JST_PH_S2B-PH-K_1x02_P2.00mm_Horizontal
T1: 10K NTC; R_0805_2012Metric
TEMP: Conn_01x02_Pin; JST_PH_S2B-PH-K_1x02_P2.00mm_Horizontal

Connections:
/B_PLUS: BAT +.1, FUSE.2
/NTC_GND: T1.1, TEMP.2
/NTC_SIG: T1.2, TEMP.1
/S1_POS: BAT1 +.1, BAT2 +.1, BAT3 +.1, BAT4 +.1, BAT5.1, BAT6 +.1, BAT7 +.1, BAT8 +.1, F1.1, F1.2, F2.1, F2.2, F3.1, F3.2, F4.1, F4.2, F5.1, F5.2, F6.1, F6.2, F7.1, F7.2, F8.1, F8.2, FUSE.1, SENSE.1
/S2_NEG: BAT9 -.1, BAT10 -.1, BAT11 -.1, BAT12 -.1, BAT13 -.1, BAT14 -.1, BAT15 -.1, BAT16 -.1, BAT -.1, F9.1, F9.2, F10.1, F10.2, F11.1, F11.2, F12.1, F12.2, F13.1, F13.2, F14.1, F14.2, F15.1, F15.2, F16.1, F16.2, SENSE.2

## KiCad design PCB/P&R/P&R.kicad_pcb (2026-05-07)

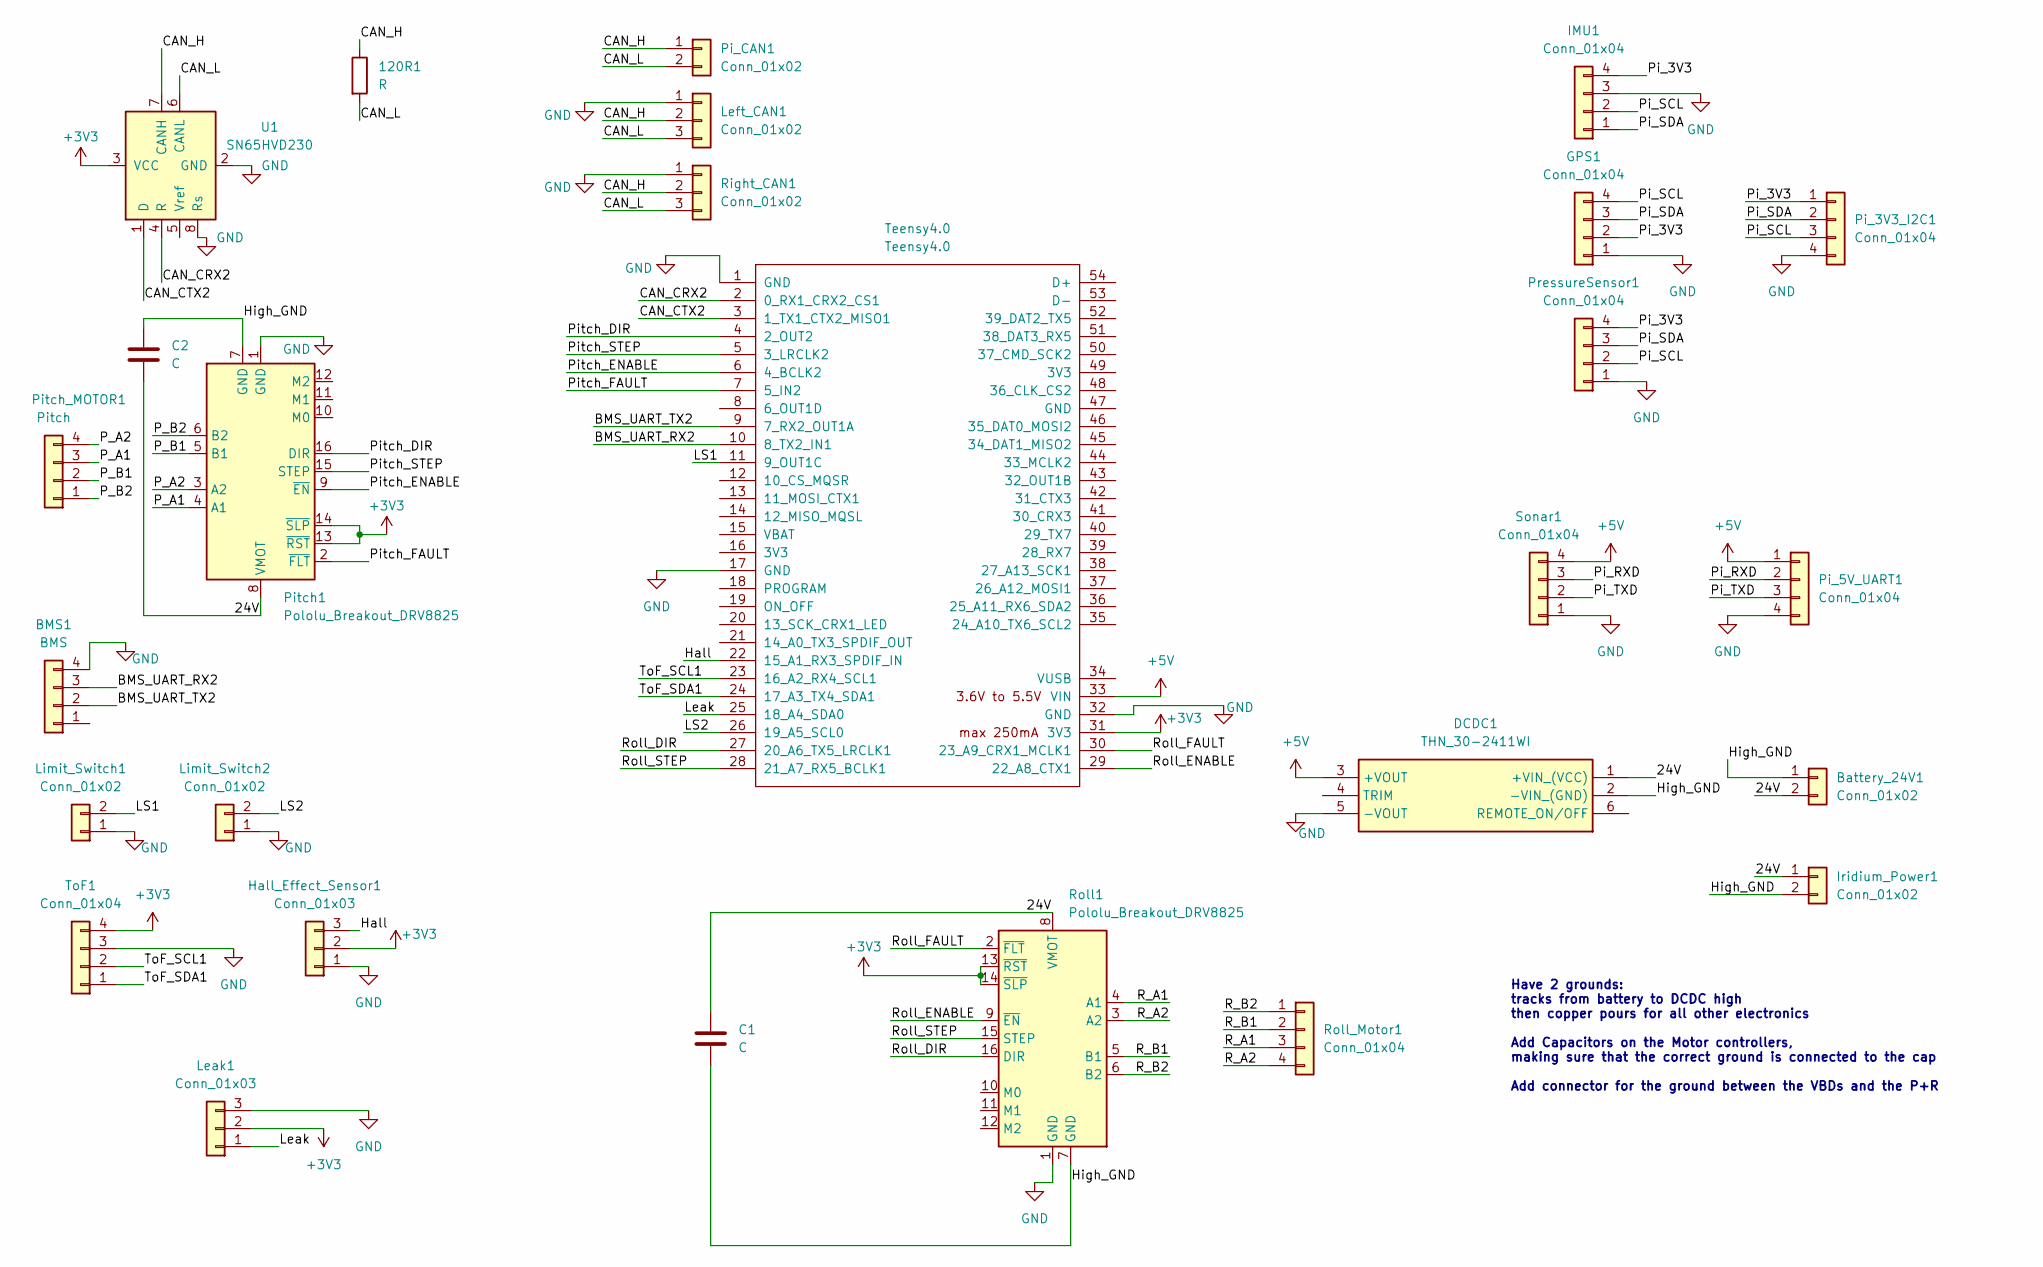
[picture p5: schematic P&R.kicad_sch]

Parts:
120R1: R; R_0805_2012Metric_Pad1.20x1.40mm_HandSolder
BMS1: BMS; JST_XH_B4B-XH-A_1x04_P2.50mm_Vertical
Battery_24V1: Conn_01x02; TerminalBlock_WAGO_2601-1102_1x02_P3.50mm_Horizontal
C1, C2: C; CP_Radial_D8.0mm_P3.50mm
DCDC1: THN_30-2411WI; THN302415WI; Mouser Part Number 495-THN-30-2411WI
GPS1: Conn_01x04; NewnewGNSS
Hall_Effect_Sensor1: Conn_01x03; JST_XH_B3B-XH-A_1x03_P2.50mm_Vertical
IMU1: Conn_01x04; JST_XH_B4B-XH-A_1x04_P2.50mm_Vertical
Iridium_Power1: Conn_01x02; JST_XH_B2B-XH-A_1x02_P2.50mm_Vertical
Leak1: Conn_01x03; SOS_Leak_Sensor_Board
Left_CAN1: Conn_01x02; JST_XH_B3B-XH-A_1x03_P2.50mm_Vertical
Limit_Switch1, Limit_Switch2: Conn_01x02; JST_XH_B2B-XH-A_1x02_P2.50mm_Vertical
Pi_3V3_I2C1, Pi_5V_UART1: Conn_01x04; JST_XH_B4B-XH-A_1x04_P2.50mm_Vertical
Pi_CAN1: Conn_01x02; JST_XH_B2B-XH-A_1x02_P2.50mm_Vertical
Pitch1: Pololu_Breakout_DRV8825; Pololu_Breakout-16_15.2x20.3mm
Pitch_MOTOR1: Pitch; JST_XH_B4B-XH-A_1x04_P2.50mm_Vertical
PressureSensor1: Conn_01x04; JST_XH_B4B-XH-A_1x04_P2.50mm_Vertical
Right_CAN1: Conn_01x02; JST_XH_B3B-XH-A_1x03_P2.50mm_Vertical
Roll1: Pololu_Breakout_DRV8825; Pololu_Breakout-16_15.2x20.3mm
Roll_Motor1: Conn_01x04; JST_XH_B4B-XH-A_1x04_P2.50mm_Vertical
Sonar1: Conn_01x04; JST_XH_B4B-XH-A_1x04_P2.50mm_Vertical
Teensy4.0: Teensy4.0; Teensy40
ToF1: Conn_01x04; JST_XH_B4B-XH-A_1x04_P2.50mm_Vertical
U1: SN65HVD230; SOIC-8_3.9x4.9mm_P1.27mm

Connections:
+3V3: Hall_Effect_Sensor1.2, Leak1.2, Pitch1.13 (~RST), Pitch1.14 (~SLP), Roll1.13 (~RST), Roll1.14 (~SLP), Teensy4.0.31 (3V3), ToF1.4, U1.3 (VCC)
+5V: DCDC1.3 (+VOUT), Pi_5V_UART1.1, Sonar1.4, Teensy4.0.33 (VIN)
/24V: Battery_24V1.2, C1.1, C2.2, DCDC1.1 (+VIN_(VCC)), Iridium_Power1.1, Pitch1.8 (VMOT), Roll1.8 (VMOT)
/BMS_UART_RX2: BMS1.3, Teensy4.0.10 (8_TX2_IN1)
/BMS_UART_TX2: BMS1.2, Teensy4.0.9 (7_RX2_OUT1A)
/CAN_CRX2: Teensy4.0.2 (0_RX1_CRX2_CS1), U1.4 (R)
/CAN_CTX2: Teensy4.0.3 (1_TX1_CTX2_MISO1), U1.1 (D)
/CAN_H: 120R1.1, Left_CAN1.2, Pi_CAN1.1, Right_CAN1.2, U1.7 (CANH)
/CAN_L: 120R1.2, Left_CAN1.3, Pi_CAN1.2, Right_CAN1.3, U1.6 (CANL)
/Hall: Hall_Effect_Sensor1.3, Teensy4.0.22 (15_A1_RX3_SPDIF_IN)
/High_GND: Battery_24V1.1, C1.2, C2.1, DCDC1.2 (-VIN_(GND)), Iridium_Power1.2, Pitch1.7 (GND), Roll1.7 (GND)
/LS1: Limit_Switch1.2, Teensy4.0.11 (9_OUT1C)
/LS2: Limit_Switch2.2, Teensy4.0.26 (19_A5_SCL0)
/Leak: Leak1.1, Teensy4.0.25 (18_A4_SDA0)
/P_A1: Pitch1.4 (A1), Pitch_MOTOR1.3
/P_A2: Pitch1.3 (A2), Pitch_MOTOR1.4
/P_B1: Pitch1.5 (B1), Pitch_MOTOR1.2
/P_B2: Pitch1.6 (B2), Pitch_MOTOR1.1
/Pi_3V3: GPS1.2, IMU1.4, Pi_3V3_I2C1.1, PressureSensor1.4
/Pi_RXD: Pi_5V_UART1.2, Sonar1.3
/Pi_SCL: GPS1.4, IMU1.2, Pi_3V3_I2C1.3, PressureSensor1.2
/Pi_SDA: GPS1.3, IMU1.1, Pi_3V3_I2C1.2, PressureSensor1.3
/Pi_TXD: Pi_5V_UART1.3, Sonar1.2
/Pitch_DIR: Pitch1.16 (DIR), Teensy4.0.4 (2_OUT2)
/Pitch_ENABLE: Pitch1.9 (~EN), Teensy4.0.6 (4_BCLK2)
/Pitch_FAULT: Pitch1.2 (~FLT), Teensy4.0.7 (5_IN2)
/Pitch_STEP: Pitch1.15 (STEP), Teensy4.0.5 (3_LRCLK2)
/R_A1: Roll1.4 (A1), Roll_Motor1.3
/R_A2: Roll1.3 (A2), Roll_Motor1.4
/R_B1: Roll1.5 (B1), Roll_Motor1.2
/R_B2: Roll1.6 (B2), Roll_Motor1.1
/Roll_DIR: Roll1.16 (DIR), Teensy4.0.27 (20_A6_TX5_LRCLK1)
/Roll_ENABLE: Roll1.9 (~EN), Teensy4.0.29 (22_A8_CTX1)
/Roll_FAULT: Roll1.2 (~FLT), Teensy4.0.30 (23_A9_CRX1_MCLK1)
/Roll_STEP: Roll1.15 (STEP), Teensy4.0.28 (21_A7_RX5_BCLK1)
/ToF_SCL1: Teensy4.0.23 (16_A2_RX4_SCL1), ToF1.2
/ToF_SDA1: Teensy4.0.24 (17_A3_TX4_SDA1), ToF1.1
GND: BMS1.4, DCDC1.5 (-VOUT), GPS1.1, Hall_Effect_Sensor1.1, IMU1.3, Leak1.3, Left_CAN1.1, Limit_Switch1.1, Limit_Switch2.1, Pi_3V3_I2C1.4, Pi_5V_UART1.4, Pitch1.1 (GND), PressureSensor1.1, Right_CAN1.1, Roll1.1 (GND), Sonar1.1, Teensy4.0.1 (GND), Teensy4.0.17 (GND), Teensy4.0.32 (GND), ToF1.3, U1.2 (GND), U1.8 (Rs)

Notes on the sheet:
Have 2 grounds: tracks from battery to DCDC high then copper pours for all other electronics Add Capacitors on the Motor controllers, making sure that the correct ground is connected to the cap Add connector for the ground between the VBDs and the P+R

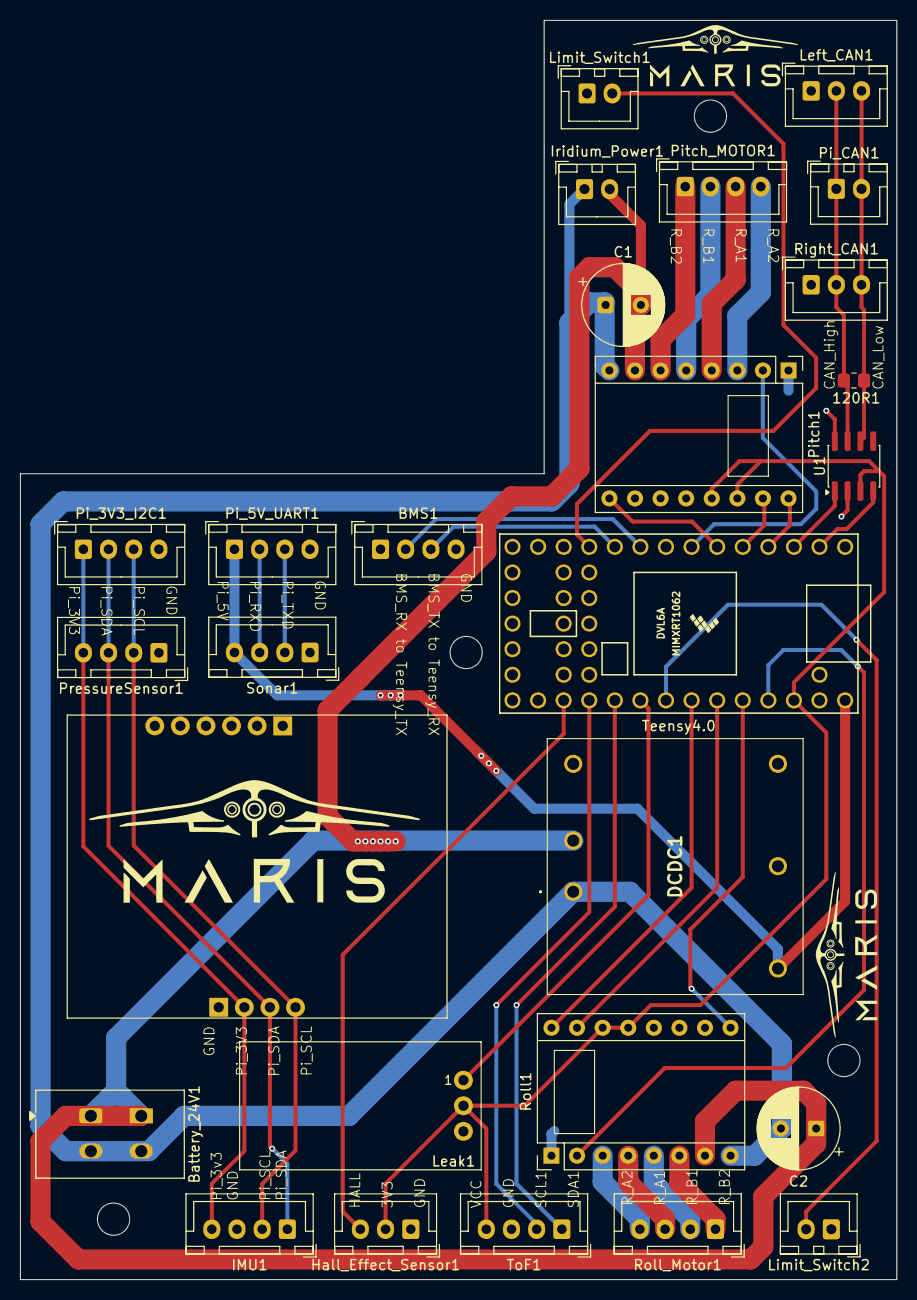
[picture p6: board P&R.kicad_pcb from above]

Board: 2 copper layers, 87.0 x 125.0 mm, 27 parts (0 on the bottom side), 38 nets.

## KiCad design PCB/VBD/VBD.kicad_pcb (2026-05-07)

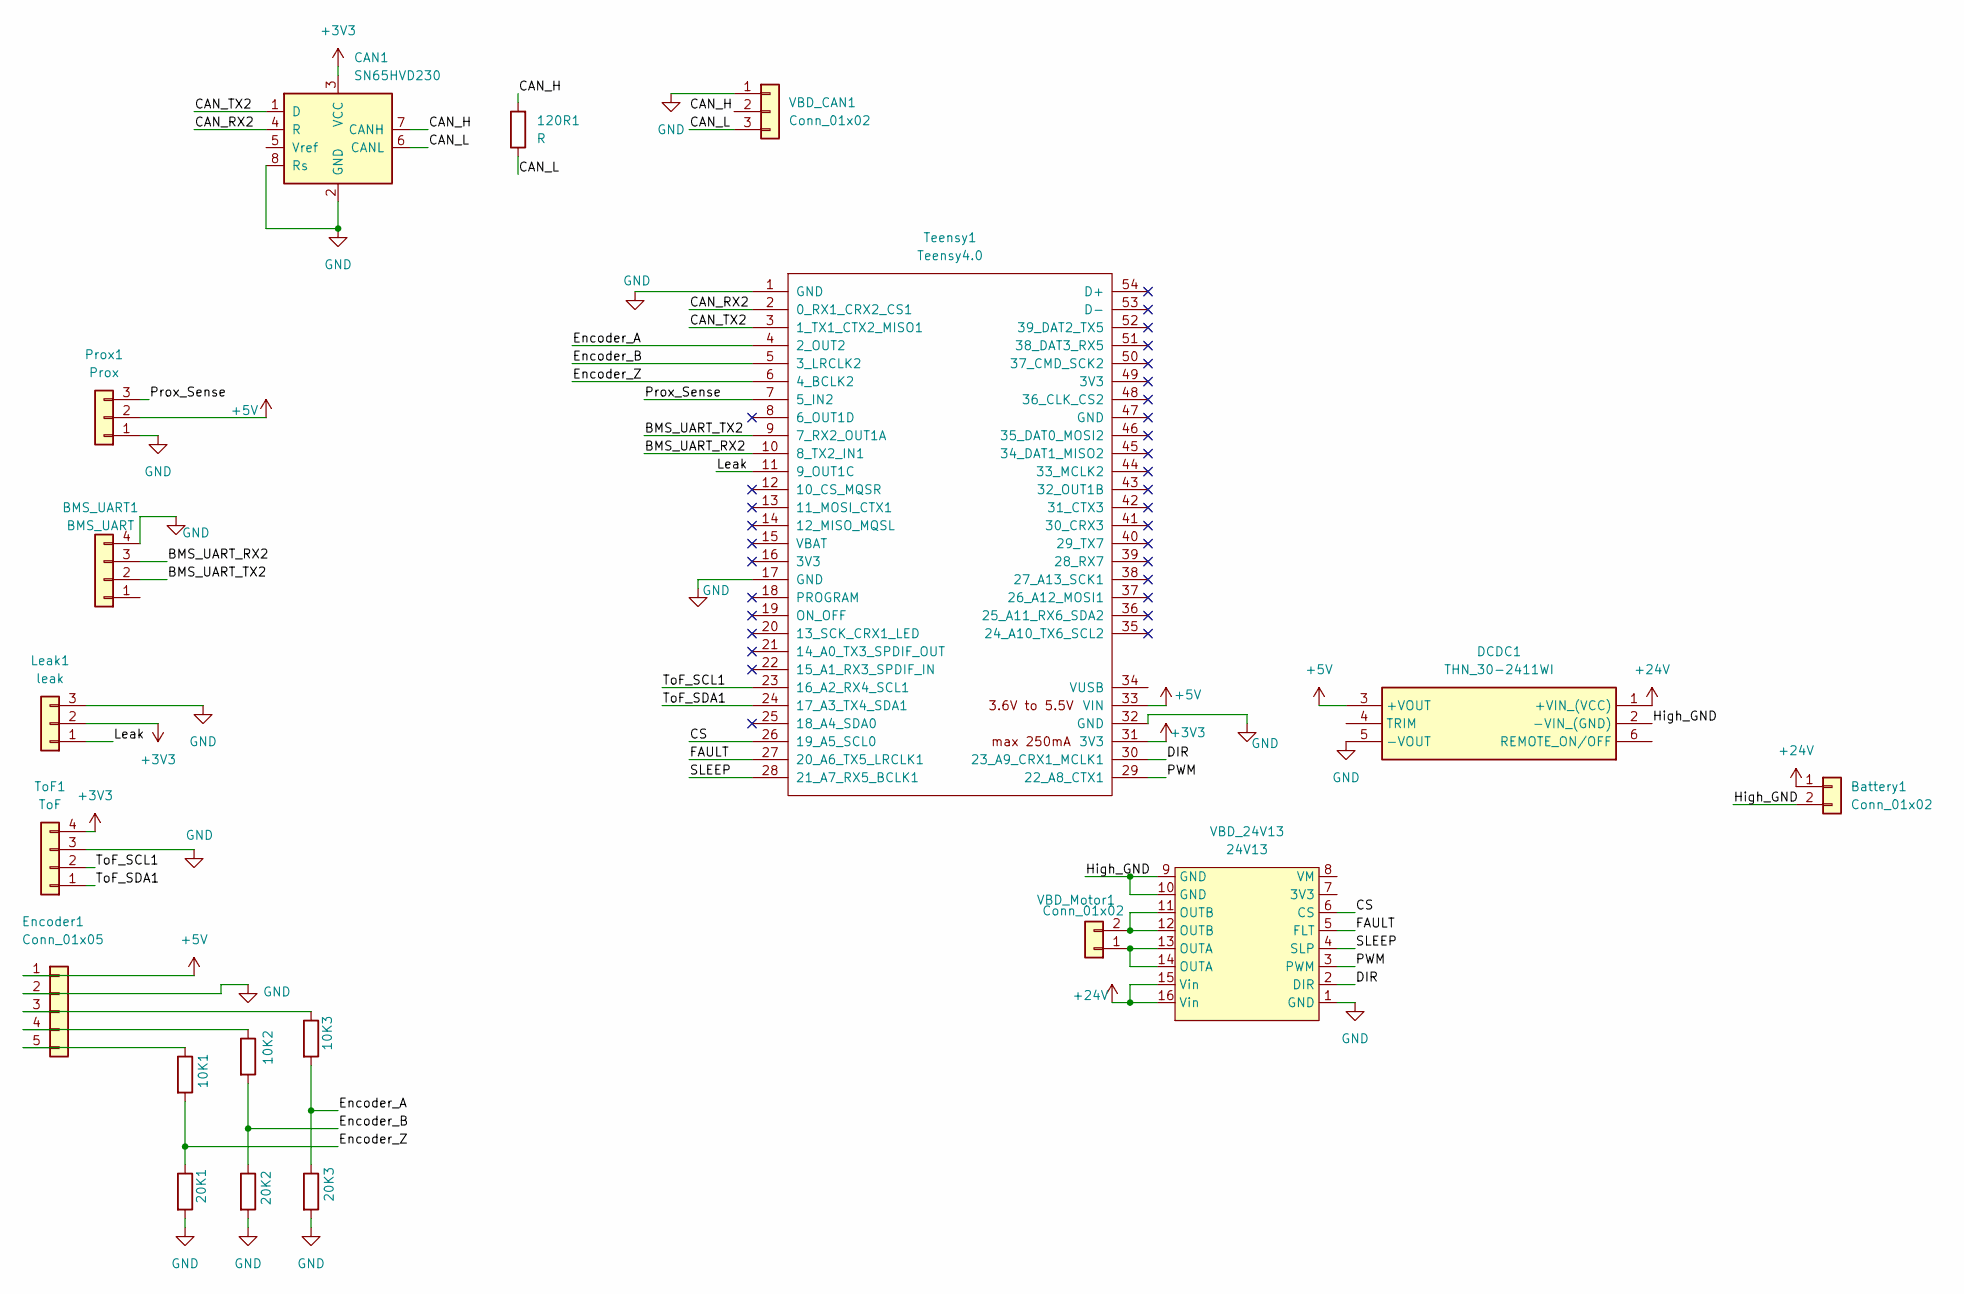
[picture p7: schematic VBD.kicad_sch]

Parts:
10K1, 10K2, 10K3, 20K1, 20K2, 20K3, 120R1: R; R_0805_2012Metric_Pad1.20x1.40mm_HandSolder
BMS_UART1: BMS_UART; JST_XH_B4B-XH-A_1x04_P2.50mm_Vertical
Battery1: Conn_01x02; TerminalBlock_WAGO_2601-1102_1x02_P3.50mm_Horizontal
CAN1: SN65HVD230; SOIC-8_3.9x4.9mm_P1.27mm
DCDC1: THN_30-2411WI; THN302415WI; Mouser Part Number 495-THN-30-2411WI
Encoder1: Conn_01x05; JST_XH_B5B-XH-A_1x05_P2.50mm_Vertical
Leak1: leak; SOS_Leak_Sensor_Board
Prox1: Prox; JST_XH_B3B-XH-A_1x03_P2.50mm_Vertical
Teensy1: Teensy4.0; Teensy40
ToF1: ToF; JST_XH_B4B-XH-A_1x04_P2.50mm_Vertical
VBD_24V13: 24V13; new24V13
VBD_CAN1: Conn_01x02; JST_XH_B3B-XH-A_1x03_P2.50mm_Vertical
VBD_Motor1: Conn_01x02; JST_XH_B2B-XH-A_1x02_P2.50mm_Vertical

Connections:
+3V3: CAN1.3 (VCC), Leak1.2, Teensy1.31 (3V3), ToF1.4
+5V: DCDC1.3 (+VOUT), Encoder1.1, Prox1.2, Teensy1.33 (VIN)
+24V: Battery1.1, DCDC1.1 (+VIN_(VCC)), VBD_24V13.15 (Vin), VBD_24V13.16 (Vin)
/BMS_UART_RX2: BMS_UART1.3, Teensy1.10 (8_TX2_IN1)
/BMS_UART_TX2: BMS_UART1.2, Teensy1.9 (7_RX2_OUT1A)
/CAN_H: 120R1.2, CAN1.7 (CANH), VBD_CAN1.2
/CAN_L: 120R1.1, CAN1.6 (CANL), VBD_CAN1.3
/CAN_RX2: CAN1.4 (R), Teensy1.2 (0_RX1_CRX2_CS1)
/CAN_TX2: CAN1.1 (D), Teensy1.3 (1_TX1_CTX2_MISO1)
/CS: Teensy1.26 (19_A5_SCL0), VBD_24V13.6 (CS)
/DIR: Teensy1.30 (23_A9_CRX1_MCLK1), VBD_24V13.2 (DIR)
/Encoder_A: 10K3.2, 20K3.1, Teensy1.4 (2_OUT2)
/Encoder_B: 10K2.2, 20K2.1, Teensy1.5 (3_LRCLK2)
/Encoder_Z: 10K1.2, 20K1.1, Teensy1.6 (4_BCLK2)
/FAULT: Teensy1.27 (20_A6_TX5_LRCLK1), VBD_24V13.5 (FLT)
/High_GND: Battery1.2, DCDC1.2 (-VIN_(GND)), VBD_24V13.9 (GND), VBD_24V13.10 (GND)
/Leak: Leak1.1, Teensy1.11 (9_OUT1C)
/PWM: Teensy1.29 (22_A8_CTX1), VBD_24V13.3 (PWM)
/Prox_Sense: Prox1.3, Teensy1.7 (5_IN2)
/SLEEP: Teensy1.28 (21_A7_RX5_BCLK1), VBD_24V13.4 (SLP)
/ToF_SCL1: Teensy1.23 (16_A2_RX4_SCL1), ToF1.2
/ToF_SDA1: Teensy1.24 (17_A3_TX4_SDA1), ToF1.1
GND: 20K1.2, 20K2.2, 20K3.2, BMS_UART1.4, CAN1.2 (GND), CAN1.8 (Rs), DCDC1.5 (-VOUT), Encoder1.2, Leak1.3, Prox1.1, Teensy1.1 (GND), Teensy1.17 (GND), Teensy1.32 (GND), ToF1.3, VBD_24V13.1 (GND), VBD_CAN1.1
unnamed: 10K3.1, Encoder1.3
unnamed: 10K2.1, Encoder1.4
unnamed: 10K1.1, Encoder1.5
unnamed: VBD_24V13.13 (OUTA), VBD_24V13.14 (OUTA), VBD_Motor1.1
unnamed: VBD_24V13.11 (OUTB), VBD_24V13.12 (OUTB), VBD_Motor1.2

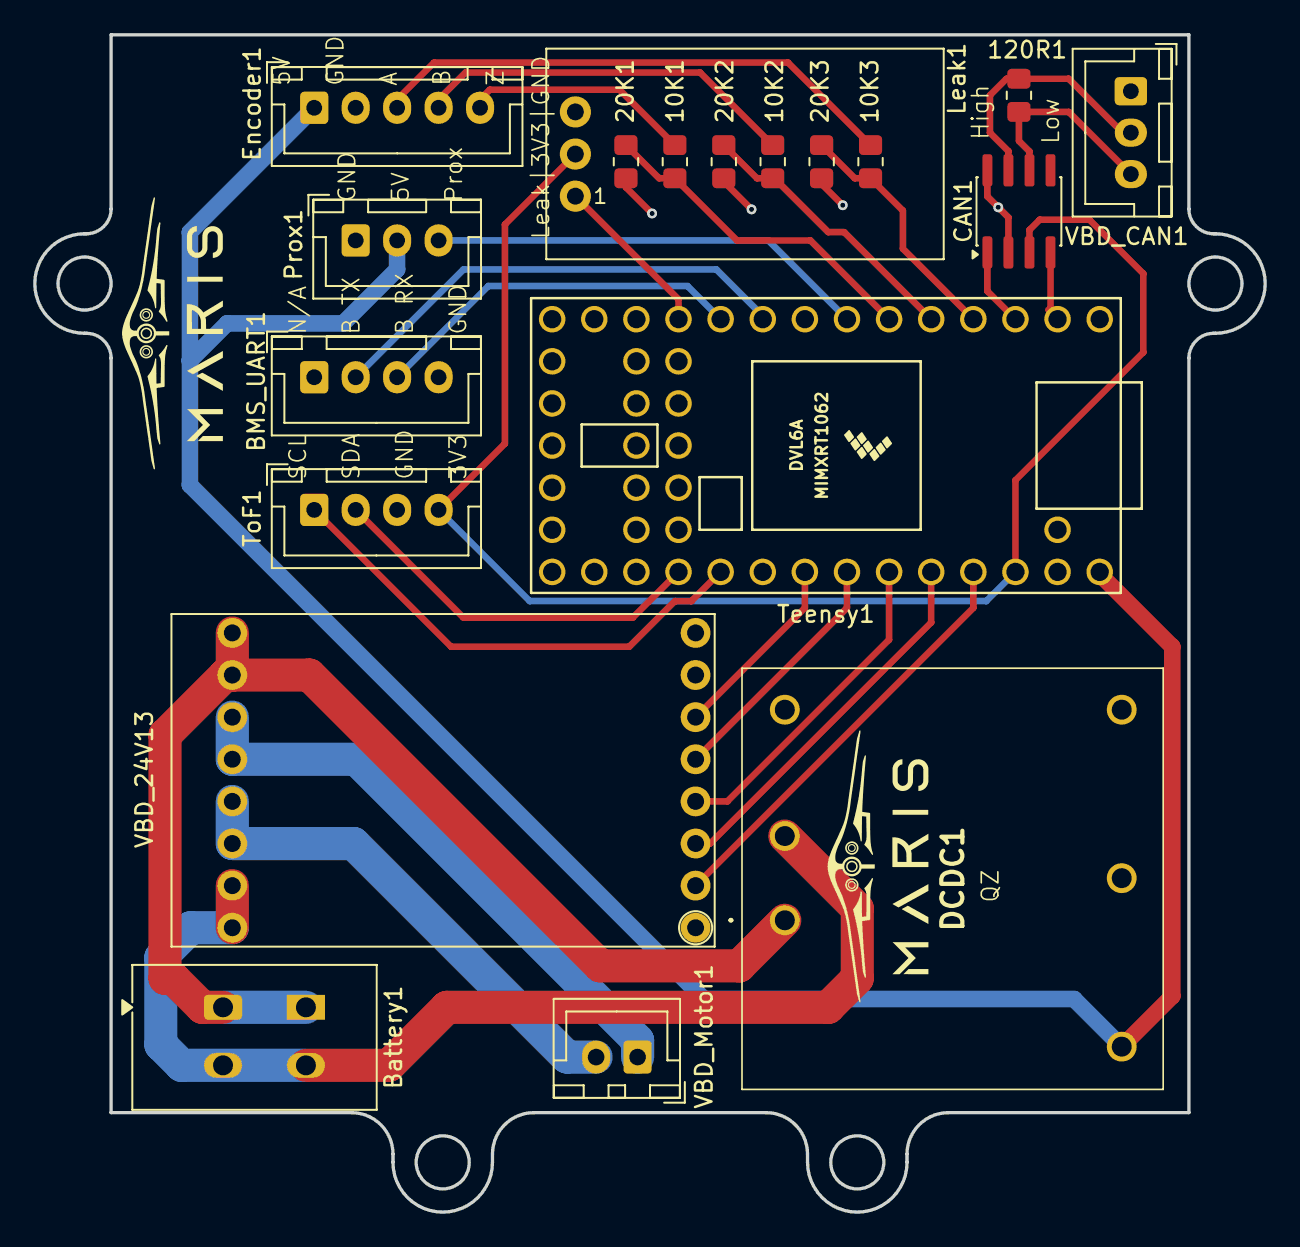
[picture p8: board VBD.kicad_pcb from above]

Board: 2 copper layers, 74.2 x 71.0 mm, 19 parts (0 on the bottom side), 28 nets.

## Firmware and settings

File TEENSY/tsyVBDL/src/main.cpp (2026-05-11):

#include <Arduino.h>
#include <stdint.h>
#include <cmath>

#include "config/pin_map.hpp"
#include "config/constants.hpp"
#include "utils/logger.hpp"

#include "drivers/enc_alt.hpp"
#include "drivers/motor_driver.hpp"
#include "drivers/tof_sensor.hpp"
#include "drivers/can_bus.hpp"
#include "drivers/leak_sensor.hpp"
#include "drivers/bms.hpp"

#include "controllers/estimator.hpp"
#include "controllers/pid_controller.hpp"
#include "controllers/safety_manager.hpp"
#include "controllers/bms_manager.hpp"

#include "protocols/can_messages.hpp"

// -----------------------------
// Hardware configuration
// -----------------------------
// Set false for motors without an encoder — ToF becomes the sole position source.
constexpr bool USE_ENCODER = false;
// Set false to run without BMS hardware connected (disables all BMS faults/timeouts).
constexpr bool USE_BMS = false;

// -----------------------------
// CAN
// -----------------------------
constexpr uint8_t CAN_NODE_ID = config::NODE_ID_RIGHT;
static CanBus canBus;
uint8_t canSequenceControl = 0;
uint8_t canSequenceFault   = 0;
uint8_t canSequenceBms     = 0;
uint8_t canSequenceBmsMore = 0;
uint32_t lastCanTxControl = 0;
uint32_t lastCanTxFault   = 0;
uint32_t lastCanTxBms     = 0;
const uint32_t CAN_TX_CONTROL_INTERVAL_MS = 20;   // 50 Hz
const uint32_t CAN_TX_FAULT_INTERVAL_MS   = 500;  //  2 Hz
const uint32_t CAN_TX_BMS_INTERVAL_MS     = 500;  //  2 Hz
uint32_t lastCanRx = 0;
const uint32_t CAN_TIMEOUT_SMALL_MS = 2000;   // soft fault warning
const uint32_t CAN_TIMEOUT_LARGE_MS = 10000;  // hard fault latch

// -----------------------------
// BMS
// -----------------------------
static BmsUart bmsUart({
    .serial = &Serial2,
    .baud   = BMS_BAUD
});
static BmsManager bmsManager;

// -----------------------------
// State / mode
// -----------------------------
enum class ControlMode {
  OVERRIDE,
  CAN,
  HOMING,
  EMERGENCY_RESURFACE
};

ControlMode mode = ControlMode::CAN;

// -----------------------------
// Runtime
// -----------------------------
float lastTofMm = 0.0f;
float lastTofRawMm = 0.0f;
bool lastDirectionExtend = true;
int pwm = 0;
int manual_pwm_cmd = 0;
const int PWM_MAX = 255;
uint32_t lastPrint = 0;

// Control
float target_mm_cmd = config::STROKE_HARD_MIN_MM;
float target_mm = target_mm_cmd;
float target_percent = 0.0f;
bool homed = false;
bool homingFailed = false;
bool holding = false;
float homingTimer_s = 0.0f;
ControlMode homingReturnMode = ControlMode::CAN;
bool debugPrint = false;
bool override_use_pid = false;

// Serial
String cmdBuffer;
const uint16_t CMD_BUFFER_MAX_LEN = 64;

// LED
uint32_t lastLedToggle = 0;
bool ledOn = false;

// CAN RX de-dup print
struct FrameCache {
  bool valid;
  CanFrame frame;
};
FrameCache lastFrames[2048];

// -----------------------------
// Fault injection flags
// -----------------------------
bool inj_leak = false;
bool inj_driver_fault_raw = false;
bool inj_cmd_timeout_small = false;
bool inj_cmd_timeout_large = false;
bool inj_bms_timeout_small = false;
bool inj_bms_timeout_large = false;
bool inj_bms_temp_high = false;
bool inj_bms_overcurrent = false;
bool inj_bms_switch_fault = false;
bool inj_bms_low_voltage = false;
bool inj_bms_high_voltage = false;
bool inj_tof_invalid = false;
bool inj_tof_out_of_range = false;
bool inj_slip = false;
bool inj_homing_failed = false;

// -----------------------------
// Drivers / controllers
// -----------------------------
static EncoderAlt enc({
  .channel = 2,
  .pin_a = PIN_ENC_A,
  .pin_b = PIN_ENC_B,
  .counts_per_rev = config::COUNTS_PER_SCREW_REV,
  .lead_screw_pitch_mm = config::LEAD_SCREW_MM_PER_REV
});

static MotorDriver motor({
  .pin_pwm = PIN_MOTOR_PWM,
  .pin_dir = PIN_MOTOR_DIR,
  .pin_slp = PIN_MOTOR_SLP,
  .pin_flt = PIN_MOTOR_FLT,
  .pin_cs  = PIN_MOTOR_CS,
  .pwm_freq_hz = 25000.0f,
  .pwm_max = 255,
  .flt_active_low = true,
  .cs_volts_per_amp = 0.04f,
  .adc_ref_volts = 3.3f,
  .adc_bits = 12
});

static ToFSensor tof(PIN_TOF_SDA, PIN_TOF_SCL);
static LeakSensor leak(PIN_LEAK, true); // active HIGH

static Estimator estimator({
  .mm_per_count      = config::MM_PER_COUNT,
  .tof_gain          = config::TOF_FUSION_GAIN,
  .recovery_gain     = config::SLIP_RECOVERY_GAIN,
  .slip_detect_mm    = config::SLIP_DETECT_MM,
  .tof_min_valid_mm  = config::TOF_MIN_VALID_MM,
  .tof_only          = !USE_ENCODER,
  .tof_filter_alpha  = config::TOF_FILTER_ALPHA
});

static PIDController pid;
Estimator::Output lastEst{};
ToFSensor::Reading lastToF{};

static SafetyManager safety;
SafetyManager::Output lastSafety{};

// -----------------------------
// Helpers
// -----------------------------
bool isFrameDifferentIgnoreSeq(const CanFrame& a, const CanFrame& b, int seqIndex)
{
  if (a.id != b.id) return true;
  if (a.len != b.len) return true;

  for (uint8_t i = 0; i < a.len; i++) {
    if (i == seqIndex) continue;
    if (a.data[i] != b.data[i]) return true;
  }
  return false;
}

float percentToMm(float percent)
{
  percent = constrain(percent, 0.0f, 100.0f);
  return config::STROKE_HARD_MIN_MM +
         (percent / 100.0f) * config::STROKE_SPAN_MM;
}

float computeSoftZoneScale(float pos_mm)
{
  if (pos_mm <= config::STROKE_SOFT_START_MM) {
    float t = (pos_mm - config::STROKE_HARD_MIN_MM) /
              (config::STROKE_SOFT_START_MM - config::STROKE_HARD_MIN_MM);
    t = constrain(t, 0.0f, 1.0f);
    return config::SOFT_ZONE_MAX_DUTY +
           t * (1.0f - config::SOFT_ZONE_MAX_DUTY);
  }

  if (pos_mm >= config::STROKE_SOFT_END_MM) {
    float t = (config::STROKE_HARD_MAX_MM - pos_mm) /
              (config::STROKE_HARD_MAX_MM - config::STROKE_SOFT_END_MM);
    t = constrain(t, 0.0f, 1.0f);
    return config::SOFT_ZONE_MAX_DUTY +
           t * (1.0f - config::SOFT_ZONE_MAX_DUTY);
  }

  return 1.0f;
}

bool isHardLimitHit(float pos_mm, bool extending)
{
  if (extending) {
    return pos_mm >= config::STROKE_HARD_MAX_MM;
  }
  return pos_mm <= config::STROKE_HARD_MIN_MM;
}

const char* modeName(ControlMode m)
{
  switch (m) {
    case ControlMode::OVERRIDE:            return "OVERRIDE";
    case ControlMode::CAN:                return "CAN";
    case ControlMode::HOMING:             return "HOMING";
    case ControlMode::EMERGENCY_RESURFACE: return "EMERG_RESURFACE";
  }
  return "?";
}

uint8_t mapSystemState()
{
  if (lastSafety.hard_fault)                    return can::STATE_FAULT;
  if (mode == ControlMode::EMERGENCY_RESURFACE)  return can::STATE_FAULT;
  if (mode == ControlMode::HOMING)               return can::STATE_HOMING;
  if (!homed)                                    return can::STATE_UNHOMED;
  if (fabs(lastEst.vel_est_mm_s) > 0.5f)        return can::STATE_RUN;
  return can::STATE_HOLD;
}

void clearInjectedFaults()
{
  inj_leak = false;
  inj_driver_fault_raw = false;
  inj_cmd_timeout_small = false;
  inj_cmd_timeout_large = false;
  inj_bms_timeout_small = false;
  inj_bms_timeout_large = false;
  inj_bms_temp_high = false;
  inj_bms_overcurrent = false;
  inj_bms_switch_fault = false;
  inj_bms_low_voltage = false;
  inj_bms_high_voltage = false;
  inj_tof_invalid = false;
  inj_tof_out_of_range = false;
  inj_slip = false;
  inj_homing_failed = false;
}

void printInjections()
{
  Serial.print("INJ leak=");
  Serial.print(inj_leak ? 1 : 0);
  Serial.print(" drv=");
  Serial.print(inj_driver_fault_raw ? 1 : 0);
  Serial.print(" s_cmd=");
  Serial.print(inj_cmd_timeout_small ? 1 : 0);
  Serial.print(" h_cmd=");
  Serial.print(inj_cmd_timeout_large ? 1 : 0);
  Serial.print(" s_bms_to=");
  Serial.print(inj_bms_timeout_small ? 1 : 0);
  Serial.print(" h_bms_to=");
  Serial.print(inj_bms_timeout_large ? 1 : 0);
  Serial.print(" bms_temp=");
  Serial.print(inj_bms_temp_high ? 1 : 0);
  Serial.print(" bms_oc=");
  Serial.print(inj_bms_overcurrent ? 1 : 0);
  Serial.print(" bms_sw=");
  Serial.print(inj_bms_switch_fault ? 1 : 0);
  Serial.print(" bms_low=");
  Serial.print(inj_bms_low_voltage ? 1 : 0);
  Serial.print(" bms_high=");
  Serial.print(inj_bms_high_voltage ? 1 : 0);
  Serial.print(" tof_inv=");
  Serial.print(inj_tof_invalid ? 1 : 0);
  Serial.print(" tof_oor=");
  Serial.print(inj_tof_out_of_range ? 1 : 0);
  Serial.print(" slip=");
  Serial.print(inj_slip ? 1 : 0);
  Serial.print(" homefail=");
  Serial.println(inj_homing_failed ? 1 : 0);
}

void printHelp()
{
  Serial.println("\n=== VBD Serial Commands ===");
  Serial.println("-- Always available --");
  Serial.println("auto                -> switch to serial control (exits CAN mode)");
  Serial.println("debug t / debug f   -> enable / disable periodic status output");
  Serial.println("status              -> print current status once");
  Serial.println("help                -> this message");
  Serial.println("-- OVERRIDE mode (after 'auto') --");
  Serial.println("h                   -> auto home via ToF (retracts to 10mm)");
  Serial.println("z                   -> mark homed at 10mm");
  Serial.println("m                   -> switch to raw PWM control");
  Serial.println("a                   -> switch to PID position control (requires homed)");
  Serial.println("c                   -> back to CAN mode (requires homed)");
  Serial.println("%<num>              -> set PID target percent (auto-enables PID)");
  Serial.println("p<num>              -> set PWM (auto-enables PWM)");
  Serial.println("f / b / s           -> extend / retract / stop (auto-enables PWM)");
  Serial.println("recover             -> safety.reset() (clears latched faults)");
  Serial.println("inj / inj0          -> print / clear fault injections");
  Serial.println("-- Hard fault injection --");
  Serial.println("leak1/leak0  drv1/drv0  hcmd1/hcmd0  hbto1/hbto0");
  Serial.println("htemp1/htemp0  hoc1/hoc0  hsw1/hsw0  hhome1/hhome0");
  Serial.println("-- Soft fault injection --");
  Serial.println("scmd1/scmd0  sbto1/sbto0  sblow1/sblow0  sbhigh1/sbhigh0");
  Serial.println("stof1/stof0  soor1/soor0  sslip1/sslip0");
  Serial.println();
}
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
void loop()
{
  uint32_t now = millis();

  // LED heartbeat
  if (!ledOn && (now - lastLedToggle >= 5000)) {
    digitalWrite(LED_BUILTIN, HIGH);
    ledOn = true;
    lastLedToggle = now;
  }
  if (ledOn && (now - lastLedToggle >= 100)) {
    digitalWrite(LED_BUILTIN, LOW);
    ledOn = false;
  }

  // dt
  static uint32_t lastTime = 0;
  float dt = (lastTime == 0) ? 0.0f : (now - lastTime) / 1000.0f;
  lastTime = now;

  // If the loop hiccups badly, drop commanded output immediately.
  if (dt > 0.2f) {
    manual_pwm_cmd = 0;
    pwm = 0;
    holding = false;
    pid.reset();
    motor.setPWM(0);
  }

  // Sensors
  int32_t counts = USE_ENCODER ? enc.readCounts() : 0;

  lastToF = tof.read();
  lastTofRawMm = lastToF.mm;
  lastTofMm = lastToF.mm;

  // Estimator fuses only on fresh + valid samples.
  bool tof_valid_estimator = lastToF.valid && lastToF.fresh;

  lastEst = estimator.update(
    counts,
    tof_valid_estimator,
    lastToF.mm,
    dt
  );

  // Inputs
  readSerialCommands();
  handleCan();
  if (USE_BMS) bmsManager.update(now);

  // Emergency resurface: large CAN timeout only — not triggered if a real hard fault exists
  // (real faults stop motor and Pi coordinates; this is only the Pi-is-dead fallback)
  if (mode == ControlMode::CAN && lastCanRx != 0 &&
      (millis() - lastCanRx > CAN_TIMEOUT_LARGE_MS) &&
      !lastSafety.hard_fault) {
    mode = ControlMode::EMERGENCY_RESURFACE;
    target_mm_cmd = config::STROKE_HARD_MAX_MM;
    target_mm = lastEst.pos_est_mm;
    pid.reset();
    holding = false;
    Serial.println("!! EMERGENCY RESURFACE - CAN lost >10s, extending to 100%");
  }

  // -----------------------------
  // Motion logic
  // -----------------------------
  if (mode == ControlMode::HOMING) {
    handleHoming(dt);

  } else if (mode == ControlMode::OVERRIDE) {
    float pos = lastEst.pos_est_mm;

    if (!override_use_pid) {
      // --- Raw PWM control ---
      bool extending = lastDirectionExtend;
      float duty = static_cast<float>(manual_pwm_cmd) / static_cast<float>(PWM_MAX);
      duty *= computeSoftZoneScale(pos);
      if (isHardLimitHit(pos, extending)) duty = 0.0f;
      duty = constrain(duty, 0.0f, 1.0f);
      pwm = static_cast<int>(roundf(duty * static_cast<float>(PWM_MAX)));
      motor.setDirection(extending ?
        MotorDriver::Direction::EXTEND :
        MotorDriver::Direction::RETRACT);
      motor.setPWM(pwm);

    } else {
      // --- PID position control ---
      float vel = lastEst.vel_est_mm_s;
      float max_step = 40.0f * dt;
      float delta = target_mm_cmd - target_mm;
      if (fabs(delta) > max_step) {
        target_mm += (delta > 0 ? max_step : -max_step);
      } else {
        target_mm = target_mm_cmd;
      }
      target_mm = constrain(target_mm, config::STROKE_HARD_MIN_MM, config::STROKE_HARD_MAX_MM);

      float error = target_mm - pos;
      bool skipPid = false;

      if (holding) {
        if (fabs(error) > config::DRIFT_RESTART_MM) {
          holding = false;
        } else {
          pwm = 0; motor.setPWM(0); skipPid = true;
        }
      }

      if (!skipPid) {
        bool near_target = fabs(error) <= config::POS_TOL_MM;
        bool slow = fabs(vel) < 0.5f;
        bool not_pushing = (error > 0 && vel <= 0) || (error < 0 && vel >= 0);
        if (near_target && slow && not_pushing) {
          pwm = 0; motor.setPWM(0); holding = true; skipPid = true;
        }
      }

      if (!skipPid) {
        float effort = pid.update(target_mm, pos, vel, dt);
        bool dir = (effort > 0);
        lastDirectionExtend = dir;
        motor.setDirection(dir ? MotorDriver::Direction::EXTEND : MotorDriver::Direction::RETRACT);
        float duty = fabs(effort);
        if (duty > 0.0f) duty = config::MIN_DUTY + (1.0f - config::MIN_DUTY) * duty;
        duty *= computeSoftZoneScale(pos);
        // Re-enforce floor after soft-zone scale: motor gets 0 (holding) or ≥ MIN_DUTY, never in-between.
        if (duty > 0.0f && duty < config::MIN_DUTY) duty = config::MIN_DUTY;
        if (isHardLimitHit(pos, dir)) duty = 0.0f;
        // Raw ToF backstop: only fires when filtered pos is already near the limit —
        // a mid-range noise spike can't trigger this and cause a spurious cutoff.
        if (lastToF.valid && dir  && pos >= config::STROKE_HARD_MAX_MM - config::TOF_BACKSTOP_APPROACH_MM && lastTofMm >= config::STROKE_HARD_MAX_MM) duty = 0.0f;
        if (lastToF.valid && !dir && pos <= config::STROKE_HARD_MIN_MM + config::TOF_BACKSTOP_APPROACH_MM && lastTofMm <= config::STROKE_HARD_MIN_MM) duty = 0.0f;
        duty = constrain(duty, 0.0f, 1.0f);
        pwm = duty * PWM_MAX;
        motor.setPWM(pwm);
      }
    }

  } else if (mode == ControlMode::CAN || mode == ControlMode::EMERGENCY_RESURFACE) {
    if (mode == ControlMode::CAN && !homed) {
      motor.setPWM(0);
      pwm = 0;
    } else {

    float pos = lastEst.pos_est_mm;
    float vel = lastEst.vel_est_mm_s;

    float max_step = 40.0f * dt;
    float delta = target_mm_cmd - target_mm;
    if (fabs(delta) > max_step) {
      target_mm += (delta > 0 ? max_step : -max_step);
    } else {
      target_mm = target_mm_cmd;
    }
    target_mm = constrain(target_mm, config::STROKE_HARD_MIN_MM, config::STROKE_HARD_MAX_MM);

    float error = target_mm - pos;
    bool skipPid = false;

    if (holding) {
      if (fabs(error) > config::DRIFT_RESTART_MM) {
        holding = false;
      } else {
        pwm = 0; motor.setPWM(0); skipPid = true;
      }
    }

    if (!skipPid) {
      bool near_target = fabs(error) <= config::POS_TOL_MM;
      bool slow = fabs(vel) < 0.5f;
      bool not_pushing = (error > 0 && vel <= 0) || (error < 0 && vel >= 0);
      if (near_target && slow && not_pushing) {
        pwm = 0; motor.setPWM(0); holding = true; skipPid = true;
      }
    }

    if (!skipPid) {
      float effort = pid.update(target_mm, pos, vel, dt);
      bool dir = (effort > 0);
      lastDirectionExtend = dir;
      motor.setDirection(dir ? MotorDriver::Direction::EXTEND : MotorDriver::Direction::RETRACT);
      float duty = fabs(effort);
      if (duty > 0.0f) duty = config::MIN_DUTY + (1.0f - config::MIN_DUTY) * duty;
      duty *= computeSoftZoneScale(pos);
      if (duty > 0.0f && duty < config::MIN_DUTY) duty = config::MIN_DUTY;
      if (isHardLimitHit(pos, dir)) duty = 0.0f;
      // Raw ToF backstop: only fires when filtered pos is already near the limit —
      // a mid-range noise spike can't trigger this and cause a spurious cutoff.
      if (lastToF.valid && dir  && pos >= config::STROKE_HARD_MAX_MM - config::TOF_BACKSTOP_APPROACH_MM && lastTofMm >= config::STROKE_HARD_MAX_MM) duty = 0.0f;
      if (lastToF.valid && !dir && pos <= config::STROKE_HARD_MIN_MM + config::TOF_BACKSTOP_APPROACH_MM && lastTofMm <= config::STROKE_HARD_MIN_MM) duty = 0.0f;
      duty = constrain(duty, 0.0f, 1.0f);
      pwm = duty * PWM_MAX;
      motor.setPWM(pwm);
    }

    } // end homed/EMERGENCY_RESURFACE branch
  }

  // -----------------------------
  // Build Safety inputs + update
  // -----------------------------
  SafetyManager::Inputs sin{};
  sin.leak_raw = leak.isLeak() || inj_leak;
  sin.driver_fault_raw = motor.faultActive() || inj_driver_fault_raw;

  sin.motor_current_a = motor.readCurrentA();
  sin.motor_enabled = motor.enabled();
  sin.motor_duty = constrain((float)pwm / (float)PWM_MAX, 0.0f, 1.0f);

  sin.pos_est_mm = lastEst.pos_est_mm;
  sin.pos_valid  = homed;
  sin.homing_failed = homingFailed || inj_homing_failed;

  bool in_can_family = (mode == ControlMode::CAN ||
                        mode == ControlMode::EMERGENCY_RESURFACE);
  bool can_small_to = (in_can_family && lastCanRx != 0 &&
                       (millis() - lastCanRx > CAN_TIMEOUT_SMALL_MS));
  sin.cmd_timeout_small = can_small_to || inj_cmd_timeout_small;
  // Large timeout still latches as hard fault so Pi sees FAULT_CMD_TO_L on reconnect.
  // Motor disable is suppressed separately during emergency resurface.
  bool can_large_to = (mode == ControlMode::EMERGENCY_RESURFACE) ||
                      (mode == ControlMode::CAN && lastCanRx != 0 &&
                       (millis() - lastCanRx > CAN_TIMEOUT_LARGE_MS));
  sin.cmd_timeout_large = can_large_to || inj_cmd_timeout_large;
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

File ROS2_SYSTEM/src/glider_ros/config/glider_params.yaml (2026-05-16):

#=============================================================================
#=============================================================================
#Glider ROS 2 system parameters
#=============================================================================
#=============================================================================

#-----------------------------------------------------------------------------
#State Manager Node
#-----------------------------------------------------------------------------
state_manager_node:
  ros__parameters:
    #How long IDLE waits between Iridium comm windows
    idle_iridium_period_s: 100.0

    #Same, but in EMERGENCY state (on surface, controller off)
    emergency_iridium_period_s: 300.0

    #How long to wait for the Iridium modem to settle/acquire signal before starting a send attempt
    iridium_settling_time_s: 60.0

    #Retries per comm window
    iridium_max_attempts: 3

    #Depth below which the glider is considered underwater for emergency surfacing decisions
    surface_depth_m: 1.0

#-----------------------------------------------------------------------------
#Safety Node
#-----------------------------------------------------------------------------
safety_node:
  ros__parameters:
    #Sonar range below which a proximity emergency is triggered
    proximity_threshold_m: 5.0

    #Number of consecutive confident below-threshold readings required before latching the emergency
    proximity_consecutive_count: 3

    #A monitored topic that hasn't published for this long triggers an emergency state
    staleness_threshold_s: 1200.0

#-----------------------------------------------------------------------------
#CAN Bridge Node
#-----------------------------------------------------------------------------
can_bridge_node:
  ros__parameters:
    #SocketCAN interface name
    can_channel: "can0"

    #Rate at which the latest commanded setpoints are re-transmitted to each Teensy 20 Hz 
    republish_rate_hz: 20.0

    #Which actuators participate in the HomeActuators action
    home_vbd_left: true
    home_vbd_right: true
    home_pr: false

#-----------------------------------------------------------------------------
#Sonar Adapter Node
#-----------------------------------------------------------------------------
sonar_adapter_node:
  ros__parameters:
    #Reject readings whose reported confidence is below this percent
    min_confidence: 50.0

    #Moving-average window size
    filter_window: 5

    #Reject a range reading if the last confidence sample is older than this
    confidence_max_age_s: 0.5

#-----------------------------------------------------------------------------
#Telemetry Adapter Node
#-----------------------------------------------------------------------------
telemetry_adapter_node:
  ros__parameters:
    #How often to build and publish a telemetry string on /iridium/sbdwt
    publish_period: 5.0

    #When a field (e.g. GPS) is unavailable, emit "LAT=UNKNOWN" placeholders
    include_unknown_fields: true

#-----------------------------------------------------------------------------
#Pressure Keller Node
#-----------------------------------------------------------------------------
pressure_keller_node:
  ros__parameters:
    #Number of samples averaged at startup (and on /pressure/zero) to fix the
    #atmospheric reference.
    surface_zero_samples: 20

    #Manual fudge factor (m) added on top of the tared depth.
    depth_offset: 0.0

    #fresh water around 1000, sea water around 1029 kg/m^3
    fluid_density: 1000.0

    #EMA on /pressure/depth; smaller α = more smoothing. α=1.0 disables. We can do 0.1 down if not smoothed
    depth_filter_alpha: 0.5

    #Reseed filter if gap since last sample exceeds this
    #since our pressure sensor is 5Hzish, 1s would mean 5 missed values
    depth_filter_reset_gap_s: 1.0

#-----------------------------------------------------------------------------
#IMU MinIMU-9 Driver Node
#-----------------------------------------------------------------------------
imu_minimu_node:
  ros__parameters:
    #Stationary samples averaged at startup (and on /imu/gyro_zero) to fix gyro bias.
    gyro_bias_samples: 250

    #Per-axis variance ceiling (rad^2/s^2); exceeded -> motion assumed, cal restarts.
    gyro_bias_max_var: 0.001

    gyro_publish_during_cal: false

#-----------------------------------------------------------------------------
#IMU Adapter Node
#-----------------------------------------------------------------------------
imu_adapter_node:
  ros__parameters:
    #Stationary samples averaged at startup (and on /imu/mount_zero) to fix roll/pitch offsets.
    mount_offset_samples: 250

    #Per-axis variance ceiling (rad^2); exceeded -> motion assumed, cal restarts.
    mount_offset_max_var: 0.0001

    publish_during_cal: false

    comp_alpha: 0.98
    comp_dt_max_s: 0.2
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

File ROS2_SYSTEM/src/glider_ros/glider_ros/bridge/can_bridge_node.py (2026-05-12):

#!/usr/bin/env python3
"""Bidirectional CAN bridge between three Teensy 4.0 nodes (P&R ID 3, VBD Left ID 1, VBD Right ID 2) and ROS 2 topics."""

import errno
import struct
import threading
import time
import rclpy
from rclpy.node import Node
from rclpy.action import ActionServer
from rclpy.callback_groups import ReentrantCallbackGroup
from rclpy.executors import MultiThreadedExecutor
from std_msgs.msg import Float64, Bool, UInt8, String

from glider_msgs.action import HomeActuators


VBD_L  = 1
VBD_R  = 2
PR     = 3

#VBD stroke geometry — must match Teensy firmware (TEENSY/tsyVBDL/include/config/constants.hpp)
#firmware maps 0-100% command linearly to STROKE_HARD_MIN_MM..STROKE_HARD_MAX_MM (10..140 mm)
VBD_STROKE_MIN_MM  = 10.0
VBD_STROKE_SPAN_MM = 130.0

CMD_BASE      = 0x100
STATUS_BASE   = 0x200
FAULT_BASE    = 0x050
BMS_BASE      = 0x210
BMS_MORE_BASE = 0x220   # VBD only — 0x221/0x222


class CanBridgeNode(Node):

    def __init__(self):
        super().__init__('can_bridge_node')

        #parameters — edit values in config/glider_params.yaml; defaults here are fallbacks
        self.declare_parameter('can_channel', 'can0')
        self.declare_parameter('republish_rate_hz', 20.0)
        self.declare_parameter('home_vbd_left', True)       #Does it exist
        self.declare_parameter('home_vbd_right', False)      #Does it exist
        self.declare_parameter('home_pr', False)             #Does it exist

        self._home_vbd_left = self.get_parameter('home_vbd_left').value
        self._home_vbd_right = self.get_parameter('home_vbd_right').value
        self._home_pr = self.get_parameter('home_pr').value

        self.get_logger().info(
            f'Homing config — vbd_left:{self._home_vbd_left} '
            f'vbd_right:{self._home_vbd_right} pr:{self._home_pr}')

        channel = self.get_parameter('can_channel').value

        try:
            import can as _can
            self.can = _can
            self.bus = _can.interface.Bus(channel=channel, interface='socketcan')
            self.get_logger().info(f'CAN bus opened on {channel}')
        except Exception as e:
            self.get_logger().error(f'Failed to open CAN: {e}')
            raise

        self.seq_pr = 0
        self.seq_vbd_l = 0
        self.seq_vbd_r = 0

        #TX failure tracking — rate-limit spammy warnings when bus is unhealthy
        self._tx_warn_throttle_s = 2.0
        self._last_tx_warn_time = {}
        self._tx_fail_count = 0

        #bus state tracking, log transitions only, not every poll
        self._last_bus_state = None

        self._setup_pr_interface()
        self._setup_vbd_interface('left', VBD_L)
        self._setup_vbd_interface('right', VBD_R)

        #internal homed/fault state — written from CAN RX thread read by action server thread
        self._home_lock = threading.Lock()
        self._vbd_left_homed_state = False
        self._vbd_right_homed_state = False
        self._pr_pitch_homed_state = False
        self._pr_roll_homed_state = False
        self._vbd_left_not_homed_fault = False
        self._vbd_right_not_homed_fault = False
        self._pr_pitch_n_home_fault = False
        self._pr_roll_n_home_fault = False

        #action runs on its own callback group so the 20 Hz republish_commands timer keeps running during blocking _home_execute
        self._action_cb_group = ReentrantCallbackGroup()
        self._home_action_server = ActionServer(
            self,
            HomeActuators,
            '/bridge/home_actuators',
            self._home_execute,
            callback_group=self._action_cb_group,
        )

        self._running = True
        self._rx_thread = threading.Thread(target=self._can_rx_loop, daemon=True)
        self._rx_thread.start()

        rate = self.get_parameter('republish_rate_hz').value
        self.create_timer(1.0 / rate, self._republish_commands)

        #poll bus health at 1 Hz so operator sees ERROR-PASSIVE / BUS-OFF transitions
        self.create_timer(1.0, self._check_bus_state)

        self.get_logger().info('CAN bridge running')

    #interface setup

    def _setup_pr_interface(self):
        self.pr_pitch_mm = 0.0
        self.pr_roll_deg = 0.0
        self.pr_enable = False
        self.pr_home = False

        self.create_subscription(Float64, '/controller/pitch_mm', self._cb_pr_pitch, 10)
        self.create_subscription(Float64, '/controller/roll_deg', self._cb_pr_roll, 10)
        self.create_subscription(Bool, '/controller/pr_enable', self._cb_pr_enable, 10)
        self.create_subscription(Bool, '/controller/pr_home', self._cb_pr_home, 10)

        self.pub_pr_pitch_pos = self.create_publisher(Float64, '/bridge/pr/pitch_pos_mm', 10)
        self.pub_pr_roll_pos = self.create_publisher(Float64, '/bridge/pr/roll_pos_deg', 10)
        self.pub_pr_tof = self.create_publisher(Float64, '/bridge/pr/tof_mm', 10)
        self.pub_pr_leak = self.create_publisher(Bool, '/bridge/pr/leak', 10)
        self.pub_pr_pitch_homed = self.create_publisher(Bool, '/bridge/pr/pitch_homed', 10)
        self.pub_pr_roll_homed = self.create_publisher(Bool, '/bridge/pr/roll_homed', 10)
        self.pub_pr_status = self.create_publisher(String, '/bridge/pr/status_flags', 10)
        self.pub_pr_seq = self.create_publisher(UInt8, '/bridge/pr/seq', 10)
        self.pub_pr_fault = self.create_publisher(String, '/bridge/pr/fault', 10)
        self.pub_pr_bms_v = self.create_publisher(Float64, '/bridge/pr/bms_voltage_v', 10)
        self.pub_pr_bms_t = self.create_publisher(Float64, '/bridge/pr/bms_temp_c', 10)
        self.pub_pr_bms_flag = self.create_publisher(UInt8, '/bridge/pr/bms_flag', 10)

    def _setup_vbd_interface(self, side, node_id):
        setattr(self, f'vbd_{side}_pct', 0)
        setattr(self, f'vbd_{side}_enable', False)
        setattr(self, f'vbd_{side}_home', False)

        self.create_subscription(
            UInt8, f'/controller/vbd_{side}_pct',
            lambda msg, s=side: setattr(self, f'vbd_{s}_pct', msg.data), 10)
        self.create_subscription(
            Bool, f'/controller/vbd_{side}_enable',
            lambda msg, s=side: setattr(self, f'vbd_{s}_enable', msg.data), 10)
        self.create_subscription(
            Bool, f'/controller/vbd_{side}_home',
            lambda msg, s=side: setattr(self, f'vbd_{s}_home', msg.data), 10)
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

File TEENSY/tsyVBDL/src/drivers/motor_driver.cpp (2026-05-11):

#include "drivers/motor_driver.hpp"
#include <Arduino.h>

MotorDriver::MotorDriver(const Config& cfg) : cfg_(cfg) {}

uint16_t MotorDriver::adcMax_() const {
  // e.g. 12-bit -> 4095
  return (1u << cfg_.adc_bits) - 1u;
}

void MotorDriver::begin() {
  pinMode(cfg_.pin_dir, OUTPUT);
  pinMode(cfg_.pin_pwm, OUTPUT);
  pinMode(cfg_.pin_slp, OUTPUT);
  pinMode(cfg_.pin_flt, INPUT_PULLUP); // safe default; FLT often open-drain
  pinMode(cfg_.pin_cs, INPUT);

  // ADC resolution
  analogReadResolution(cfg_.adc_bits);

  // PWM setup
  analogWriteFrequency(cfg_.pin_pwm, cfg_.pwm_freq_hz);
  analogWrite(cfg_.pin_pwm, 0);

  // Default safe state
  digitalWrite(cfg_.pin_dir, LOW);
  digitalWrite(cfg_.pin_slp, LOW);
  enabled_ = false;
  last_pwm_ = 0;
  dir_ = Direction::EXTEND;
}

void MotorDriver::enable() {
  digitalWrite(cfg_.pin_slp, HIGH);
  enabled_ = true;
}

void MotorDriver::disable() {
  // Always stop first
  analogWrite(cfg_.pin_pwm, 0);
  last_pwm_ = 0;
  digitalWrite(cfg_.pin_slp, LOW);
  enabled_ = false;
}

void MotorDriver::setDirection(Direction dir) {
  dir_ = dir;
  digitalWrite(cfg_.pin_dir, (dir_ == Direction::EXTEND) ? HIGH : LOW);
}

void MotorDriver::setPWM(uint16_t pwm) {
  if (pwm > cfg_.pwm_max) pwm = cfg_.pwm_max;
  last_pwm_ = pwm;

  // If disabled, don't drive
  if (!enabled_) {
    analogWrite(cfg_.pin_pwm, 0);
    return;
  }

  analogWrite(cfg_.pin_pwm, pwm);
}

void MotorDriver::setDuty(float duty) {
  if (duty < 0.0f) duty = 0.0f;
  if (duty > 1.0f) duty = 1.0f;
  const uint16_t pwm = static_cast<uint16_t>(duty * static_cast<float>(cfg_.pwm_max));
  setPWM(pwm);
}

void MotorDriver::stop() {
  analogWrite(cfg_.pin_pwm, 0);
  last_pwm_ = 0;
}

bool MotorDriver::faultActive() const {
  const bool raw_high = (digitalRead(cfg_.pin_flt) == HIGH);
  // active-low => fault when pin is LOW
  return cfg_.flt_active_low ? !raw_high : raw_high;
}

float MotorDriver::readCurrentA() const {
  const uint16_t raw = analogRead(cfg_.pin_cs);
  const float volts = (static_cast<float>(raw) / static_cast<float>(adcMax_())) * cfg_.adc_ref_volts;

  // Current sense outputs volts proportional to motor current
  // Some boards output 0V at 0A. If yours has offset, we’ll add later.
  const float amps = volts / cfg_.cs_volts_per_amp;
  return amps;
}

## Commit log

2026-04-26 add ROS2_ANALYSIS folder
    [all_topics.csv, bridge_bms_status.csv, bridge_leak_status.csv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]
2026-04-26 added teensy code
2026-04-28 imu from v5 to v6
2026-04-30 pressure sensor calibration
2026-04-30 -bridge node less spammy if failed -bus state included
    [can_bridge_node.py]
2026-05-01 new controller + mission + IMU changes
2026-05-02 pressure reconnect if fails
    [pressure_keller_node.py]
2026-05-02 added pressure fluid dnesity to glider parameters
2026-05-03 IMU calibration updates ( gyro + offset P&R)
2026-05-07 -added pcb folder -added more readme comments
    [P&R.kicad_pcb, P&R.kicad_sch, VBD.kicad_pcb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]
2026-05-07 -added battery board subfolder -added README for Teensy P&R
    [PR_Battery_Board_A.kicad_pcb, PR_Battery_Board_A.kicad_sch, PR_Battery_Board_B.kicad_pcb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]
2026-05-07 folder ROS2 ANALYSIS changed to ROS2 TESTING
    [all_topics.csv, bridge_bms_status.csv, bridge_leak_status.csv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]
2026-05-11 updated teensy VBD code
2026-05-15 imu changes
2026-05-16 pressure noise cancelation using EMA
    [glider_params.yaml, pressure_keller_node.py]
2026-05-16 added glider.stl for 3d visualiser to have actual glider
2026-05-16 stl too big
2026-05-16 stl right size (16mb)
